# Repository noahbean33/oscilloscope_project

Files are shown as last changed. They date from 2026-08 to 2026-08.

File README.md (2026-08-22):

# Digital Oscilloscope Project

Complete project files for the digital oscilloscope system.

## Project Overview

This is a complete high-performance digital oscilloscope implementation featuring:
- **High-speed analog data acquisition** using ADC
- **FPGA-based signal processing** with Xilinx Artix-7
- **Real-time waveform capture and display**
- **Custom PCB design** with professional circuit layout
- **Embedded firmware** running on MicroBlaze soft processor

## Project Structure

```
oscilloscope_project/
├── oscilloscope-fpga/         # Xilinx Vivado FPGA project (Chapter 8 version)
│   ├── oscilloscope-fpga.xpr  # Main Vivado project file
│   ├── oscilloscope-fpga.srcs/# VHDL source files and constraints
│   └── oscilloscope-fpga.cache/# Vivado build cache
│
├── oscilloscope-software/     # Xilinx Vitis C/C++ software project (Chapter 8 version)
│   ├── oscilloscope-software/ # Application source code
│   └── oscilloscope-software_system/ # System configuration
│
├── oscilloscope-circuit/      # KiCad PCB design project (Chapter 6)
│   ├── Oscilloscope.sch       # Main schematic (hierarchical)
│   ├── Oscilloscope.kicad_pcb # PCB layout
│   ├── *.sch                  # Hierarchical schematic sheets
│   ├── Schematic Symbols.lib  # Custom schematic symbols
│   ├── Footprints.pretty/     # Custom PCB footprints
│   └── Oscilloscope.xlsx      # Bill of materials
│
├── set_drive_letter.bat       # Windows helper script for path length limits
└── README.md                  # This file
```

## Components

### 1. FPGA Project (`oscilloscope-fpga/`)
**Purpose**: Implements high-speed digital logic for ADC interface and data processing

**Key Features**:
- ADC interface logic (SPI communication)
- High-speed data capture buffer
- MicroBlaze soft processor integration
- AXI bus interconnect
- GPIO for status and control
- UART for debugging

**Tools Required**:
- Xilinx Vivado Design Suite (2019.2 or later recommended)
- Xilinx Artix-7 device support

**Opening the Project**:
1. Launch Xilinx Vivado
2. Open Project → Navigate to `oscilloscope-fpga/oscilloscope-fpga.xpr`
3. Generate bitstream or modify design as needed

### 2. Software Project (`oscilloscope-software/`)
**Purpose**: Embedded C firmware for MicroBlaze processor

**Key Features**:
- ADC configuration and control
- Data acquisition and buffering
- Waveform processing algorithms
- User interface logic
- Communication protocols

**Tools Required**:
- Xilinx Vitis (formerly SDK)
- Compatible with Vivado version

**Opening the Project**:
1. Launch Xilinx Vitis
2. Set workspace to `oscilloscope-software/`
3. Import existing application project
4. Build and debug on hardware

### 3. Circuit Design (`oscilloscope-circuit/`)
**Purpose**: Professional PCB schematic and layout

**Schematic Hierarchy**:
- `Oscilloscope.sch` - Top-level sheet
- `ADC.sch` - Analog-to-digital converter circuit
- `Analog Inputs.sch` - Input conditioning and protection
- `Calibration.sch` - Calibration circuitry
- `PMOD Ports.sch` - FPGA interface connectors
- `Power Supply.sch` - Power regulation circuits
- `SPI.sch` - SPI communication interface

**Key Features**:
- High-speed analog front-end
- Multi-layer PCB design
- Proper signal integrity considerations
- Power supply regulation
- FPGA interface via PMOD connectors

**Tools Required**:
- KiCad EDA 5.0 or later

**Opening the Project**:
1. Launch KiCad
2. Open Project → Navigate to `oscilloscope-circuit/Oscilloscope.pro`
3. **Important**: Add custom libraries first:
   - Open KiCad project manager
   - Go to *Preferences → Manage Symbol Libraries*
   - Add `Schematic Symbols.lib` as a project library
   - Go to *Preferences → Manage Footprint Libraries*
   - Add `Footprints.pretty/` directory as a project library
4. Open schematic or PCB editor

## Getting Started

### Prerequisites

**Hardware**:
- Xilinx Arty A7-100 development board
- Custom oscilloscope PCB (optional - can be ordered from Gerber files)
- USB cable for FPGA programming
- Power supply (5V for Arty board)

**Software**:
- Xilinx Vivado Design Suite (free WebPACK edition supports Artix-7)
- Xilinx Vitis Unified Software Platform
- KiCad EDA (for viewing/modifying circuit design)

### Build and Run Instructions

#### Step 1: Build FPGA Design
```bash
# Open oscilloscope-fpga.xpr in Vivado
# In Vivado TCL Console or GUI:
# 1. Run Synthesis
# 2. Run Implementation
# 3. Generate Bitstream
```

#### Step 2: Export Hardware Platform
```bash
# In Vivado, after successful bitstream generation:
# File → Export → Export Hardware
# Include bitstream
# Export to a location accessible by Vitis
```

#### Step 3: Build Software Application
```bash
# Open Vitis and import the software project
# 1. Set hardware platform (exported from Vivado)
# 2. Build application (hammer icon or Project → Build All)
# 3. Connect Arty board via USB
# 4. Program FPGA and run application
```

#### Step 4: Program and Test
```bash
# In Vitis:
# Xilinx → Program FPGA (loads bitstream)
# Run → Debug or Run (launches firmware)
# Monitor via UART terminal (115200 baud, 8N1)
```

### Manufacturing PCB (Optional)

If you want to build the custom oscilloscope circuit:

1. **Generate Manufacturing Files**:
   - Open `Oscilloscope.kicad_pcb` in KiCad
   - File → Plot → Generate Gerbers
   - File → Fabrication Outputs → Generate Drill Files

2. **Order PCB**:
   - Upload Gerber files to PCB manufacturer (OSH Park, JLCPCB, PCBWay, etc.)
   - Recommended specs: 4-layer board, 1.6mm thickness, ENIG finish

3. **Order Components**:
   - Use `Oscilloscope.xlsx` or `Oscilloscope.csv` for BOM
   - Purchase from Digi-Key, Mouser, or other electronics distributors

4. **Assembly**:
   - Follow Chapter 7 guidelines for component placement
   - Use reflow soldering for SMT components
   - Hand solder through-hole components

## System Architecture

```
┌─────────────────────────────────────────────────────────────┐
│                     Oscilloscope System                      │
├─────────────────────────────────────────────────────────────┤
│                                                              │
│  Analog Input → Front-End Conditioning → ADC → FPGA        │
│                                                ↓            │
│                                         Data Capture        │
│                                         & Processing        │
│                                                ↓            │
│                                        MicroBlaze CPU       │
│                                                ↓            │
│                                    Display/Communication    │
│                                                              │
└─────────────────────────────────────────────────────────────┘
```

### Signal Flow:
1. **Analog Input** - External signal via BNC/scope probe
2. **Conditioning** - Amplification, attenuation, filtering
3. **ADC** - High-speed analog-to-digital conversion
4. **FPGA Logic** - Parallel data capture and buffering
5. **MicroBlaze** - Signal processing and control
6. **Output** - Display via UART/interface

## Configuration

### FPGA Clock Configuration
- System clock: Typically 100 MHz from Arty board
- ADC sampling clock: Configurable based on requirements
- Check constraints file (`.xdc`) in `oscilloscope-fpga.srcs/constrs_1/`

### Software Configuration
- UART baud rate: 115200 (default)
- ADC sample rate: Configured in firmware
- Buffer sizes: Adjustable in source code

## Troubleshooting

### Vivado Path Length Issues (Windows)
- Use `set_drive_letter.bat` to create shorter paths
- Edit script to match your installation location
- Maps directory to drive letter Z:

### Library Not Found (KiCad)
- Ensure custom libraries are added to project
- Check `sym-lib-table` and `fp-lib-table` files
- Re-add libraries via Preferences if needed

### FPGA Programming Fails
- Check USB cable connection
- Verify Arty board is powered
- Install Xilinx cable drivers
- Check Device Manager (Windows) or lsusb (Linux)

### Software Build Errors
- Ensure hardware platform matches FPGA design
- Regenerate BSP (Board Support Package)
- Clean and rebuild project

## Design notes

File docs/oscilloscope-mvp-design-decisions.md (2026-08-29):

# MVP Design Decisions

## Status and revision boundary

This file records the implemented **Oscilloscope internal-ADC MVP** decisions as of 2026-08-28. The live design has 101 components and 57 nets. **Proposed, locked, target, configured, implemented, modeled, measured, tested, certified, and production-proven are distinct statuses.** Implementation does not establish measured or certified performance.

## Fixed product requirements and exclusions

- Retain STM32L432KCU6, internal ADC, native USB FS, 192×96 LCD, three buttons, four LEDs, two BNC channels, and STDC14 SWD/VCP.
- **CH1 = PA0 / ADC1_IN5. CH2 = PA1 / ADC1_IN6.** ADC regular sequence is **CH1 rank 1, then CH2 rank 2**.
- Two identical DC-coupled, unipolar channels. No AC coupling, gain/range switching, external ADC, FPGA, bipolar supply, hardware comparator trigger, isolation, battery, or probe-compensation output in MVP.
- Normal rated measurement range is **0–12 V DC**, ground referenced. **15 V is only an unverified overload-survival design target**; it is not bench-tested, safety certified, or part of the normal measurement rating.
- Prohibited: negative inputs, floating measurements, mains, CAT environments, motor/inverter power nodes, high-energy sources, or any source whose ground cannot safely be bonded to USB/PCB ground.
- Low-frequency nominal input impedance: **1.10 MΩ** per channel.
- BNC shells, PCB signal ground, MCU ground, and USB ground are common.

## Locked decision table

| Item | Rev 0.2 MVP decision | Status / verification gate |
|---|---|---|
| ADC pins and sequence | CH1 = PA0/ADC1_IN5, rank 1; CH2 = PA1/ADC1_IN6, rank 2 | Schematic implemented; firmware register/readback confirmation required |
| ADC clock/rate | ADC asynchronous clock target 80 MHz; timer-triggered 3.2 Msps aggregate; 12.5-cycle sample + 12.5-cycle conversion | Proposed configuration; ADC timing remains unmeasured |
| Channel timing | CH1 then CH2, nominal 312.5 ns sample-time offset and 1.6 Msps/channel | Configuration targets, not measured facts |
| Input range | 0–12 V DC normal rated measurement | Locked |
| Overload | 15 V non-destructive survival target | Unverified prototype gate; not a user rating or certification |
| Input impedance | 1.10 MΩ low-frequency nominal | Locked |
| Analog architecture | Divider → CHx_CLAMP → 10 kΩ → TLV9062 non-inverting input → follower → 47 Ω/1 nF ADC RC | Implemented |
| Divider | 3 × 300 kΩ high arm + 200 kΩ low arm; all 0.1%, ≤25 ppm/°C | Locked |
| Compensation | 12 pF C0G across each 300 kΩ; 8.2 pF C0G across 200 kΩ plus 2.2 pF/4.7 pF trim pads | 8.2 pF-only baseline fails modeled ±1 dB-to-100 kHz flatness. Expected robust population is both trims (15.1 pF total); 12.9 pF remains the measured-parasitic alternate. |
| Clamp | One BAV199LT1G per channel, both internal diodes used | Locked; exact mapping below |
| Buffer/filter | TLV9062IDGKR; 1.0 nF C0G at ADC pin; R12/R18 = 47 Ω Yageo RC0603FR-0747RL | Implemented; bounded model passes, hardware timing/settling unmeasured |
| Clock accuracy | HSI timebase with USB-SOF/factory correction | Locked approach; HSI accuracy over temperature is a prototype gate |
| VCP | Explicit crossed target/probe UART nets | Locked; continuity/loopback confirmation required |
| LCD procurement | Exact **ERM19296-1, “4-Wire SPI Pin Header Connection”** option | Locked; connector/interface captured below |
| Backlight resistor | 27 Ω, 0.75 W initial prototype tuning value | Bounded value-selection gate: accept only if measured current is 60–75 mA |
| Backlight switching | Protected-5-V high-side PWM: NCE3401 P-MOS plus 2N7002KT1G gate pull-down; LCD pin 6 remains solid ground | Implemented; PWM high = backlight ON; operating point and thermals unmeasured |
| Spare headers | Remove both TS-107-T-AA headers | Locked |
| Protection/thermal/ESD | Existing specified USB and input-protection architecture | Thermal, hot-plug, overload, and ESD performance remain prototype gates |

## Analog front end

### Per-channel connection

`BNC center → 300 kΩ → 300 kΩ → 300 kΩ → divider node/CHx_CLAMP; 200 kΩ CHx_CLAMP-to-AGND; compensation capacitors across divider resistors; BAV199 clamps at CHx_CLAMP; 10 kΩ CHx_CLAMP-to-TLV9062 non-inverting input; TLV9062 follower; 47 Ω output series; 1 nF ADC-pin-to-AGND; MCU ADC pin.`

The divider node is the named **CH1_CLAMP** or **CH2_CLAMP** net. The 10 kΩ resistor is downstream of that net, between CHx_CLAMP and the corresponding TLV9062 non-inverting input.

### BAV199LT1G exact pin mapping

The authoritative onsemi BAV199LT1G datasheet, SOT-23 Case 318 Style 11, defines **pin 1 = ANODE, pin 2 = CATHODE, pin 3 = CATHODE-ANODE series junction**. Therefore connect each clamp as follows:

- **Pin 1 (lower-diode anode) → AGND**
- **Pin 3 (series junction: lower cathode / upper anode) → CHx_CLAMP**
- **Pin 2 (upper-diode cathode) → VDDA, the 3.3 V analog rail**

This uses both internal diodes. Do not leave either diode unused, and do not connect the upper clamp to noisy digital 3V3.

### Divider calculation and tolerance

Nominal values are `RH = 3 × 300 kΩ = 900 kΩ` and `RL = 200 kΩ`.

- Nominal ratio: `k = RL/(RH+RL) = 200/1100 = 0.1818181818`.
- Low-frequency nominal input impedance: `RH + RL = 1.10 MΩ`.
- 12 V input → 2.1818 V nominal at CHx_CLAMP.
- 15 V input → 2.7273 V nominal; this supports only the unverified overload-survival target.
- 3.3 V ADC full-scale corresponds to 18.15 V nominal input and is headroom, not a rating.

Three equal 300 kΩ, ±0.1% resistors in series form a 900 kΩ arm with **±0.1% guaranteed resistance tolerance**, because their absolute worst-case errors sum in the same proportion as their nominal values; the arm is not ±0.3%.

Exact opposing-arm worst case:

- `kMAX = 200.2/(899.1+200.2) = 0.1821158919`, or **+0.163741%** relative to nominal.
- `kMIN = 199.8/(900.9+199.8) = 0.1815208504`, or **−0.163532%** relative to nominal.

Thus the guaranteed divider-ratio limit is approximately **+0.1637% / −0.1635%** before calibration, commonly rounded to **±0.164%**.

For statistical/RSS estimates, keep assumptions explicit:

- If each resistor's 0.1% is treated as an independent 1σ value, first-order ratio RSS is **0.0945% (1σ)**.
- If ±0.1% is treated as a rectangular guaranteed bound, each resistor has σ = 0.1%/√3 and the first-order ratio RSS is **0.0545% (1σ)**.

Neither RSS figure replaces the guaranteed worst-case limit.

## ADC and firmware acquisition targets

- ADC asynchronous clock target: **80 MHz**.
- Regular conversion sequence: **ADC1_IN5/CH1 rank 1**, then **ADC1_IN6/CH2 rank 2**.
- Per-rank timing target: **12.5 ADC clock cycles sampling + 12.5 cycles conversion = 25 cycles = 312.5 ns** at 80 MHz.
- Timer-triggered sequence target: **3.2 Msps aggregate**, yielding **1.6 Msps/channel** for the two alternating ranks.
- The **312.5 ns channel skew** and **1.6 Msps/channel** values are configuration targets requiring firmware register verification and bench timing confirmation; they are not measured performance claims.
- The superseded 330 Ω/1 nF network modeled at approximately **9.5–9.9 LSB external acquisition error**. The implemented **47 Ω/1 nF** network models at **0.558 LSB worst case** over RADC bounds 0–680 Ω. This is not a measured ADC timing or settling result.
- DMA circular acquisition, software trigger, and 10/50/90% pretrigger remain locked.
- HSI timebase accuracy, including temperature behavior after USB-SOF/factory correction, is a prototype verification gate.

## VCP net naming

Use direction-explicit nets and preserve the crossover:

- **VCP_TARGET_TX_TO_PROBE_RX:** MCU UART TX → STDC14 probe RX.
- **VCP_PROBE_TX_TO_TARGET_RX:** STDC14 probe TX → MCU UART RX.

Do not use ambiguous bare `TX`/`RX` names. Confirm with continuity and loopback during bring-up.

## LCD procurement and interface capture

Procurement is locked to the exact **ERM19296-1 “4-Wire SPI Pin Header Connection”** option. The module uses a **1×20, 2.54 mm-pitch pin header**. Capture the connector as follows for the ordered 4-wire SPI option:

| Pin | Module signal | Rev 0.2 disposition |
|---:|---|---|
| 1–4 | Optional font-chip SI, SO, SCLK, CS# | NC unless the exact ordered option includes and uses the font chip |
| 5 | LEDA | Backlight anode supply path through the prototype-selected series resistor |
| 6 | VSS | Common module ground and backlight return; the authoritative pin table exposes no separate LEDK connector pin |
| 7 | VDD | 3.3 V logic supply |
| 8 | A0(RS) | MCU LCD data/command select |
| 9 | RSTB | MCU LCD reset |
| 10 | CSB | MCU LCD chip select |
| 11–14 | DB7–DB4 | Tie high to VDD for serial mode |
| 15–17 | DB3–DB1 | Tie together and connect to MCU SPI MOSI/SDA |
| 18 | DB0 | Connect to MCU SPI SCK/SCL |
| 19 | ERD | Tie to VDD in serial mode |
| 20 | RWR | Tie to VDD in serial mode |

The ordered module's interface selection must be **IF2:IF1:IF0 = L:L:L for 4-wire serial SPI**. Capture A0/RS, CSB, RSTB, MOSI/SDA, and SCK/SCL explicitly. Incoming inspection must verify the ordered option and any factory straps.

The backlight uses a protected-5-V high-side PWM switch. Protected VBUS connects to the **source of fitted NCE3401 P-channel MOSFET Q1**;

Logic polarity is non-inverting end-to-end: **MCU PWM high turns the 2N7002 on, pulls the NCE3401 gate low, turns the P-MOS on, and turns the backlight ON**. PWM low leaves both devices off through their pull resistors. The fitted NCE3401 has 75 mΩ maximum RDS(on) at VGS = −4.5 V;

The 27 Ω value remains provisional: measure the exact ordered module and retain or change it only if maximum-brightness current is **60–75 mA** under the defined VBUS condition. Verify resistor and MOSFET temperatures at acceptance limits.

## Power budget and current derivation

An LDO input current is approximately its output current plus small quiescent current; it is **not** power-converted as it would be through an ideal switching regulator. The backlight is a separate direct-VBUS load.

The exact accounting is LDO input current = LDO output current + LDO quiescent current, with direct-VBUS loads added separately. Including 80 µA LDO IQ and 20 µA TVS leakage gives 125.10/145.10/175.10 mA; rounded totals are:

- Typical case: `50 mA 3.3 V rail + 75 mA direct-VBUS backlight ≈ 125 mA USB`.
- Design case: `70 mA + 75 mA = 145 mA USB`.
- Validation case: `100 mA + 75 mA = 175 mA USB`.

Backlight remains off before USB configuration; pre-enumeration target is <100 mA. AP7361C thermal performance, VBUS hot-plug behavior, PPTC behavior, and backlight heating remain prototype verification gates.

## Verification gates and claim limits

The following are **not measured facts** and must be labeled as prototype verification gates wherever mentioned:

- Analog bandwidth, amplitude flatness, −3 dB point, alias response, and ADC settling/crosstalk.
- HSI/timebase accuracy over voltage and temperature.
- 15 V overload survival and recovery.
- Divider compensation trim and square-wave response.
- Regulator, MOSFET, LCD/backlight, and enclosure thermal performance.
- USB and external-input ESD/hot-plug robustness.

Required warning wording: **“0–12 V DC RATED MEASUREMENT; 15 V OVERLOAD-SURVIVAL TARGET UNVERIFIED; GROUND REFERENCED; NOT ISOLATED; NO MAINS/CAT/HIGH ENERGY; NO NEGATIVE INPUT.”**

## Implemented PCB and release state

- Board: 100 × 100 mm, four copper layers, nominal 1.30 mm custom stackup; all components top-side.
- Routing: complete, zero airwires and zero DRC errors.
- USB_DP final repair: bottom-layer bypass with explicit top/bottom transition vias.
- USB configuration target: 45 Ω single-ended / 90 Ω differential; fabrication target only, not measured or certified performance.
- Remaining protected warnings: `Trace a4ae` and `Trace b74f`; Gerber cleanup or explicit waiver required.
- SMT assembly blocker: fourteen fabricated 1.0 × 1.0 mm test pads remain BOM elements and must be excluded from BOM and pick-and-place. TP_GND (Keystone 4952) remains included.
- DNI exclusion set: C16, C17, C23, and C24.

## Schematic acceptance

- PA0/ADC1_IN5 is CH1 and PA1/ADC1_IN6 is CH2; rank order is documented.
- Both channels use the exact BAV199 pin mapping above and both internal diodes.
- CHx_CLAMP naming and the downstream 10 kΩ-to-op-amp connection are explicit.
- LCD connector, 4-wire SPI strapping, and signal dispositions are explicit; pin 6 remains solid ground and pin 5 is driven by the protected-5-V high-side PWM path.
- VCP crossover nets are direction-explicit.
- Both TS-107-T-AA headers are absent.
- Implemented items are not described as measured, tested, certified, or production-proven without evidence.

**Remaining schematic blocker:** none identified. Bandwidth, divider compensation, 15 V overload survival, backlight operating point, USB ESD/hot-plug, ADC timing, thermals, and HSI accuracy remain unmeasured prototype gates.

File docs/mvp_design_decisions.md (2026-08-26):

# MVP Design Decisions

## Status and revision boundary

This file locks the **Sillyscope Rev 0.2 MVP** decisions for schematic capture. **Proposed/locked means approved for capture; it does not mean implemented, tested, measured, or certified.** Rev 0.2 circuitry is not yet present in the schematic. Firmware-confirmation and prototype-verification gates do not block capture unless explicitly identified as a capture blocker.

## Fixed product requirements and exclusions

- Retain STM32L432KCU6, internal ADC, native USB FS, 192×96 LCD, three buttons, four LEDs, two BNC channels, and STDC14 SWD/VCP.
- **CH1 = PA0 / ADC1_IN5. CH2 = PA1 / ADC1_IN6.** ADC regular sequence is **CH1 rank 1, then CH2 rank 2**.
- Two identical DC-coupled, unipolar channels. No AC coupling, gain/range switching, external ADC, FPGA, bipolar supply, hardware comparator trigger, isolation, battery, or probe-compensation output in MVP.
- Normal rated measurement range is **0–12 V DC**, ground referenced. **15 V is only an unverified overload-survival design target**; it is not bench-tested, safety certified, or part of the normal measurement rating.
- Prohibited: negative inputs, floating measurements, mains, CAT environments, motor/inverter power nodes, high-energy sources, or any source whose ground cannot safely be bonded to USB/PCB ground.
- Low-frequency nominal input impedance: **1.10 MΩ** per channel.
- BNC shells, PCB signal ground, MCU ground, and USB ground are common.

## Locked decision table

| Item | Rev 0.2 MVP decision | Status / verification gate |
|---|---|---|
| ADC pins and sequence | CH1 = PA0/ADC1_IN5, rank 1; CH2 = PA1/ADC1_IN6, rank 2 | Locked for capture; firmware register/readback confirmation required |
| ADC clock/rate | ADC asynchronous clock target 80 MHz; timer-triggered 3.2 Msps aggregate; 12.5-cycle sample + 12.5-cycle conversion | **Current 330 Ω/1 nF drive fails modeled acquisition settling (~9.5–9.9 LSB).** Change R12/R18 to 47 Ω is recommended before layout freeze; then re-simulate and bench-confirm. |
| Channel timing | CH1 then CH2, nominal 312.5 ns sample-time offset and 1.6 Msps/channel | Configuration targets, not measured facts |
| Input range | 0–12 V DC normal rated measurement | Locked |
| Overload | 15 V non-destructive survival target | Unverified prototype gate; not a user rating or certification |
| Input impedance | 1.10 MΩ low-frequency nominal | Locked |
| Analog architecture | Divider → CHx_CLAMP → 10 kΩ → TLV9062 non-inverting input → follower → 330 Ω/1 nF ADC RC | Locked |
| Divider | 3 × 300 kΩ high arm + 200 kΩ low arm; all 0.1%, ≤25 ppm/°C | Locked |
| Compensation | 12 pF C0G across each 300 kΩ; 8.2 pF C0G across 200 kΩ plus 2.2 pF/4.7 pF trim pads | 8.2 pF-only baseline fails modeled ±1 dB-to-100 kHz flatness. Expected robust population is both trims (15.1 pF total); 12.9 pF remains the measured-parasitic alternate. |
| Clamp | One BAV199LT1G per channel, both internal diodes used | Locked; exact mapping below |
| Buffer/filter | TLV9062IDR; 1.0 nF C0G at ADC pin; **47 Ω series recommended in place of captured 330 Ω** | Simulation-proven change required to retain 12.5-cycle target; not yet implemented |
| Clock accuracy | HSI timebase with USB-SOF/factory correction | Locked approach; HSI accuracy over temperature is a prototype gate |
| VCP | Explicit crossed target/probe UART nets | Locked; continuity/loopback confirmation required |
| LCD procurement | Exact **ERM19296-1, “4-Wire SPI Pin Header Connection”** option | Locked; connector/interface captured below |
| Backlight resistor | 27 Ω, 0.5 W initial prototype tuning value | Bounded value-selection gate: accept only if measured current is 60–75 mA |
| Backlight switching | Protected-5-V high-side PWM: AO3401A P-MOS plus 2N7002KT1G gate pull-down; LCD pin 6 remains solid ground | Locked for capture; PWM high = backlight ON; thermal verification required |
| Spare headers | Remove both TS-107-T-AA headers | Locked |
| Protection/thermal/ESD | Existing specified USB and input-protection architecture | Thermal, hot-plug, overload, and ESD performance remain prototype gates |

## Analog front end

### Per-channel connection

`BNC center → 300 kΩ → 300 kΩ → 300 kΩ → divider node/CHx_CLAMP; 200 kΩ CHx_CLAMP-to-AGND; compensation capacitors across divider resistors; BAV199 clamps at CHx_CLAMP; 10 kΩ CHx_CLAMP-to-TLV9062 non-inverting input; TLV9062 follower; 330 Ω output series; 1 nF ADC-pin-to-VSSA; MCU ADC pin.`

The divider node is the named **CH1_CLAMP** or **CH2_CLAMP** net. The 10 kΩ resistor is downstream of that net, between CHx_CLAMP and the corresponding TLV9062 non-inverting input.

### BAV199LT1G exact pin mapping

The authoritative onsemi BAV199LT1G datasheet, SOT-23 Case 318 Style 11, defines **pin 1 = ANODE, pin 2 = CATHODE, pin 3 = CATHODE-ANODE series junction**. Therefore connect each clamp as follows:

- **Pin 1 (lower-diode anode) → AGND**
- **Pin 3 (series junction: lower cathode / upper anode) → CHx_CLAMP**
- **Pin 2 (upper-diode cathode) → VDDA, the 3.3 V analog rail**

This uses both internal diodes. Do not leave either diode unused, and do not connect the upper clamp to noisy digital 3V3.

### Divider calculation and tolerance

Nominal values are `RH = 3 × 300 kΩ = 900 kΩ` and `RL = 200 kΩ`.

- Nominal ratio: `k = RL/(RH+RL) = 200/1100 = 0.1818181818`.
- Low-frequency nominal input impedance: `RH + RL = 1.10 MΩ`.
- 12 V input → 2.1818 V nominal at CHx_CLAMP.
- 15 V input → 2.7273 V nominal; this supports only the unverified overload-survival target.
- 3.3 V ADC full-scale corresponds to 18.15 V nominal input and is headroom, not a rating.

Three equal 300 kΩ, ±0.1% resistors in series form a 900 kΩ arm with **±0.1% guaranteed resistance tolerance**, because their absolute worst-case errors sum in the same proportion as their nominal values; the arm is not ±0.3%.

Exact opposing-arm worst case:

- `kMAX = 200.2/(899.1+200.2) = 0.1821158919`, or **+0.163741%** relative to nominal.
- `kMIN = 199.8/(900.9+199.8) = 0.1815208504`, or **−0.163532%** relative to nominal.

Thus the guaranteed divider-ratio limit is approximately **+0.1637% / −0.1635%** before calibration, commonly rounded to **±0.164%**.

For statistical/RSS estimates, keep assumptions explicit:

- If each resistor's 0.1% is treated as an independent 1σ value, first-order ratio RSS is **0.0945% (1σ)**.
- If ±0.1% is treated as a rectangular guaranteed bound, each resistor has σ = 0.1%/√3 and the first-order ratio RSS is **0.0545% (1σ)**.

Neither RSS figure replaces the guaranteed worst-case limit.

## ADC and firmware acquisition targets

- ADC asynchronous clock target: **80 MHz**.
- Regular conversion sequence: **ADC1_IN5/CH1 rank 1**, then **ADC1_IN6/CH2 rank 2**.
- Per-rank timing target: **12.5 ADC clock cycles sampling + 12.5 cycles conversion = 25 cycles = 312.5 ns** at 80 MHz.
- Timer-triggered sequence target: **3.2 Msps aggregate**, yielding **1.6 Msps/channel** for the two alternating ranks.
- The **312.5 ns channel skew** and **1.6 Msps/channel** values are configuration targets requiring firmware register verification and bench timing confirmation; they are not measured performance claims.
- Rev 0.2 simulation of the captured 330 Ω/1 nF ADC network produced approximately **9.5–9.9 LSB external acquisition error** for alternating 0.5 V/12 V channel-equivalent levels. A candidate sweep found **47 Ω/1 nF** gives **0.558 LSB worst-case modeled error** over RADC bounds 0–680 Ω. Treat R12/R18=47 Ω as the required pre-layout change unless a subsequent authoritative macromodel contradicts it.
- DMA circular acquisition, software trigger, and 10/50/90% pretrigger remain locked.
- HSI timebase accuracy, including temperature behavior after USB-SOF/factory correction, is a prototype verification gate.

## VCP net naming

Use direction-explicit nets and preserve the crossover:

- **VCP_TARGET_TX_TO_PROBE_RX:** MCU UART TX → STDC14 probe RX.
- **VCP_PROBE_TX_TO_TARGET_RX:** STDC14 probe TX → MCU UART RX.

Do not use ambiguous bare `TX`/`RX` names. Confirm with continuity and loopback during bring-up.

## LCD procurement and interface capture

Procurement is locked to the exact **ERM19296-1 “4-Wire SPI Pin Header Connection”** option. The module uses a **1×20, 2.54 mm-pitch pin header**. Capture the connector as follows for the ordered 4-wire SPI option:

| Pin | Module signal | Rev 0.2 disposition |
|---:|---|---|
| 1–4 | Optional font-chip SI, SO, SCLK, CS# | NC unless the exact ordered option includes and uses the font chip |
| 5 | LEDA | Backlight anode supply path through the prototype-selected series resistor |
| 6 | VSS | Common module ground and backlight return; the authoritative pin table exposes no separate LEDK connector pin |
| 7 | VDD | 3.3 V logic supply |
| 8 | A0(RS) | MCU LCD data/command select |
| 9 | RSTB | MCU LCD reset |
| 10 | CSB | MCU LCD chip select |
| 11–14 | DB7–DB4 | Tie high to VDD for serial mode |
| 15–17 | DB3–DB1 | Tie together and connect to MCU SPI MOSI/SDA |
| 18 | DB0 | Connect to MCU SPI SCK/SCL |
| 19 | ERD | Tie to VDD in serial mode |
| 20 | RWR | Tie to VDD in serial mode |

The ordered module's interface selection must be **IF2:IF1:IF0 = L:L:L for 4-wire serial SPI**. Capture A0/RS, CSB, RSTB, MOSI/SDA, and SCK/SCL explicitly. Incoming inspection must verify the ordered option and any factory straps.

The backlight uses a protected-5-V high-side PWM switch. Connect protected VBUS to the **source of AO3401A P-channel MOSFET**; connect its drain through the provisional **27 Ω, 0.5 W** resistor to LCD **LEDA pin 5**. LCD **pin 6 VSS remains continuously bonded to ground** for both logic and backlight return. Pull the AO3401A gate up to protected VBUS with **100 kΩ** for default OFF. A **2N7002KT1G** N-MOS has its drain at the P-MOS gate, source at ground, and gate driven by the MCU PWM through **100 Ω**, with **100 kΩ gate-to-ground** for default OFF.

Logic polarity is non-inverting end-to-end: **MCU PWM high turns the 2N7002 on, pulls the AO3401A gate low, turns the P-MOS on, and turns the backlight ON**. PWM low leaves both devices off through their pull resistors. AO3401A is rated −30 V VDS and ±12 V VGS, with RDS(on) maximum 60 mΩ at VGS = −4.5 V; the protected-5-V gate swing is within rating and provides negligible conduction loss at 60–75 mA. 2N7002KT1G is rated 60 V VDS, ±20 V VGS, and at least 230 mA continuous drain current under its stated minimum-pad/high-temperature condition; it only sinks the 100 kΩ pull-up current plus gate transient current. These ratings are suitable for this driver.

The 27 Ω value remains provisional: measure the exact ordered module and retain or change it only if maximum-brightness current is **60–75 mA** under the defined VBUS condition. Verify resistor and MOSFET temperatures at acceptance limits.

## Power budget and current derivation

An LDO input current is approximately its output current plus small quiescent current; it is **not** power-converted as it would be through an ideal switching regulator. The backlight is a separate direct-VBUS load.

Ignoring small LDO quiescent current in these rounded totals:

- Typical case: `50 mA 3.3 V rail + 75 mA direct-VBUS backlight ≈ 125 mA USB`.
- Design case: `70 mA + 75 mA = 145 mA USB`.
- Validation case: `100 mA + 75 mA = 175 mA USB`.

Backlight remains off before USB configuration; pre-enumeration target is <100 mA. AP7361C thermal performance, VBUS hot-plug behavior, PPTC behavior, and backlight heating remain prototype verification gates.

## Verification gates and claim limits

The following are **not measured facts** and must be labeled as prototype verification gates wherever mentioned:

- Analog bandwidth, amplitude flatness, −3 dB point, alias response, and ADC settling/crosstalk.
- HSI/timebase accuracy over voltage and temperature.
- 15 V overload survival and recovery.
- Divider compensation trim and square-wave response.
- Regulator, MOSFET, LCD/backlight, and enclosure thermal performance.
- USB and external-input ESD/hot-plug robustness.

Required warning wording: **“0–12 V DC RATED MEASUREMENT; 15 V OVERLOAD-SURVIVAL TARGET UNVERIFIED; GROUND REFERENCED; NOT ISOLATED; NO MAINS/CAT/HIGH ENERGY; NO NEGATIVE INPUT.”**

## Schematic-capture acceptance

- PA0/ADC1_IN5 is CH1 and PA1/ADC1_IN6 is CH2; rank order is documented.
- Both channels use the exact BAV199 pin mapping above and both internal diodes.
- CHx_CLAMP naming and the downstream 10 kΩ-to-op-amp connection are explicit.
- LCD connector, 4-wire SPI strapping, and signal dispositions are explicit; pin 6 remains solid ground and pin 5 is driven by the protected-5-V high-side PWM path.
- VCP crossover nets are direction-explicit.
- Both TS-107-T-AA headers are absent.
- Proposed/locked items are not described as implemented or tested.

**Remaining schematic-capture blocker:** none identified after adopting the high-side backlight switch. Firmware confirmation, compensation selection, bandwidth, HSI accuracy, overload, thermal, hot-plug, backlight-current tuning, and ESD tests remain post-capture prototype gates rather than capture blockers.

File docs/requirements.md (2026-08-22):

- two channels
- display shows one channel
- 0v to 3.3v range
- accurate to 500 khz
- data streaming/logging to pc
- small form factor
- buttons for channel activation
- button for start/stop recording
- led indicator for power, channel activity, recording, etc

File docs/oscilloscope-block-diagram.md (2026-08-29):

# Block Diagram

## Rev 0.2 status

The following architecture is implemented in the live 101-component, 57-net design. Implementation does not imply measured, tested, certified, or production-proven performance.

```mermaid
flowchart LR
  B1[CH1 BNC\n0–12 V rated] --> D1[1.10 MΩ low-frequency nominal\n5.5:1 compensated divider]
  B2[CH2 BNC\n0–12 V rated] --> D2[1.10 MΩ low-frequency nominal\n5.5:1 compensated divider]
  D1 --> C1[CH1_CLAMP\nBAV199: P1 AGND, P3 node, P2 VDDA]
  D2 --> C2[CH2_CLAMP\nBAV199: P1 AGND, P3 node, P2 VDDA]
  C1 --> R1[10 kΩ] --> O1[TLV9062IDGKR buffer A] --> F1[47 Ω R12 + 1 nF] --> A1[PA0 / ADC1_IN5\nCH1 rank 1]
  C2 --> R2[10 kΩ] --> O2[TLV9062IDGKR buffer B] --> F2[47 Ω R18 + 1 nF] --> A2[PA1 / ADC1_IN6\nCH2 rank 2]
  A1 --> MCU[STM32L432KCU6\n80 MHz ADC clock target\n3.2 Msps aggregate target]
  A2 --> MCU

  USB[USB-C VBUS + USB FS] --> ESD[USBLC6-2SC6]
  ESD --> MCU
  USB --> PF[MF-PSMF035X-2] --> V5[Protected VBUS]
  V5 --> LDO[AP7361C 3.3 V]
  V5 --> PM[NCE3401 Q1 P-MOS high-side switch\n100 kΩ gate pull-up = default OFF]
  PM --> BR[27 Ω, 0.75 W provisional] --> BL[ERM19296-1 LEDA pin 5]
  BL --> GND[LCD pin 6 VSS\nsolid common ground/return]
  LDO --> MCU
  LDO --> VDDA[Filtered VDDA]
  VDDA --> C1
  VDDA --> C2
  LDO --> OP[TLV9062]
  LDO --> LCD[ERM19296-1 exact\n4-wire SPI, 1x20 2.54 mm]
  MCU --> LCD
  MCU -->|PWM high = ON\n100 Ω gate series| NM[2N7002KT1G\n100 kΩ gate pulldown]
  NM -->|pulls P-MOS gate low| PM

  MTX[MCU TX] -->|VCP_TARGET_TX_TO_PROBE_RX| PRX[STDC14 probe RX]
  PTX[STDC14 probe TX] -->|VCP_PROBE_TX_TO_TARGET_RX| MRX[MCU RX]
```

## Timing and rating annotations

- ADC sequence target: CH1 rank 1 then CH2 rank 2.
- Target timing: 12.5-cycle sample + 12.5-cycle conversion at 80 MHz, giving 312.5 ns skew and 1.6 Msps/channel at 3.2 Msps aggregate.
- These timing values require firmware and bench confirmation.
- Normal measurement rating is 0–12 V DC. Fifteen-volt survival is an unverified overload target, not a rating.

## Ground and safety

BNC shells, AGND/PCB ground, MCU ground, and USB ground are common. Rev 0.2 remains non-isolated and has no CAT, mains, high-energy, or negative-input rating.

Detailed interface pin dispositions and verification gates: [MVP Design Decisions](https://www.flux.ai/nbean/oscilloscope/files/mvp-design-decisions).

The high-side switch preserves the required solid VSS/backlight return on pin 6. The 27 Ω value remains provisional pending module current and thermal measurement.

## PCB status

The PCB is 100 × 100 mm, four copper layers, nominal 1.30 mm custom stackup, with all components top-side. Routing is complete with zero airwires and zero DRC errors. USB_DP uses a bottom-layer bypass with explicit top/bottom transition vias. The configured USB target is 45 Ω single-ended / 90 Ω differential for fabrication, not measured or certified performance. Protected warnings remain for `Trace a4ae` and `Trace b74f`.

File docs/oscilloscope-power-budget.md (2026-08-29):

# Power Budget

## Revision boundary

These are planning and bounded-calculation values for the implemented design, not measured results. The LCD backlight is supplied directly from protected VBUS; logic and analog circuitry use the 3.3 V LDO.

## Rev 0.2 budget

| Load | Typical/planning | Design/validation |
|---|---:|---:|
| STM32L432KCU6 | 12 mA | 25 mA allowance |
| TLV9062 dual | 1.1 mA | 1.5 mA allowance |
| LCD logic | 5 mA planning | 15 mA allowance |
| Four indicator LEDs | up to 24 mA | 24 mA |
| Miscellaneous | 3–5 mA | included in rail totals |
| **3.3 V rail** | **about 50 mA** | **70 mA design; 100 mA validation case** |
| LCD backlight from protected VBUS | **60–75 mA acceptance band** | **75 mA budget** |

## Correct USB-current derivation

An LDO input current is approximately its output current plus its quiescent current. It is not calculated by ideal power conversion. The backlight current is separately drawn directly from VBUS.

Using AP7361C maximum quiescent current of 80 µA and adding the direct-source backlight and 20 µA TVS leakage separately:

- **Typical:** `50.00 mA LDO output + 0.08 mA LDO IQ + 75.00 mA backlight + 0.02 mA TVS = 125.10 mA USB`.
- **Design:** `70.00 + 0.08 + 75.00 + 0.02 = 145.10 mA USB`.
- **Validation case:** `100.00 + 0.08 + 75.00 + 0.02 = 175.10 mA USB`.

The rounded architecture totals are 125/145/175 mA. Other direct-VBUS loads, if added, must be included separately rather than reflected through the LDO.

Backlight is held off until USB configuration; pre-enumeration target remains <100 mA.

## LDO thermal planning

At 5.0 V input and 3.3 V output:

- 50 mA → `(5.0−3.3)×0.050 = 85 mW`.
- 70 mA → **119 mW**.
- 100 mA → **170 mW**.

These are calculated dissipation targets. AP7361C case temperature, closed-enclosure temperature rise, and 3.3 V regulation under maximum load remain prototype verification gates.

## Backlight value-selection gate

Protected VBUS feeds fitted **NCE3401 Q1** as the P-MOS high-side switch, then provisional **27 Ω R19** (Yageo RC2010FK-0727RL, 0.75 W), then ERM19296-1 LEDA pin 5.

At 75 mA, NCE3401 conduction loss using 75 mΩ maximum RDS(on) at −4.5 V is about `I²R = 0.075²×0.075 = 0.42 mW`.

**27 Ω remains an initial tuning value, not a final electrical acceptance.** Measure the exact ordered module Vf/current and retain or replace the resistor so maximum-brightness current is **60–75 mA**. Verify resistor, P-MOS, LCD, and enclosure temperatures. This correction removes the backlight schematic-capture blocker without changing the 75 mA current budget.

## Protected power path gates

PPTC voltage drop/nuisance trip, VBUS hot-plug overshoot, TVS behavior, regulator and backlight thermal performance, and USB ESD performance remain unmeasured prototype gates.

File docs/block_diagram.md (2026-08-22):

# Block Diagram

## Rev 0.2 status

The following architecture is locked for schematic capture but is not yet implemented or tested.

```mermaid
flowchart LR
  B1[CH1 BNC\n0–12 V rated] --> D1[1.10 MΩ low-frequency nominal\n5.5:1 compensated divider]
  B2[CH2 BNC\n0–12 V rated] --> D2[1.10 MΩ low-frequency nominal\n5.5:1 compensated divider]
  D1 --> C1[CH1_CLAMP\nBAV199: P1 AGND, P3 node, P2 VDDA]
  D2 --> C2[CH2_CLAMP\nBAV199: P1 AGND, P3 node, P2 VDDA]
  C1 --> R1[10 kΩ] --> O1[TLV9062 buffer A] --> F1[330 Ω + 1 nF] --> A1[PA0 / ADC1_IN5\nCH1 rank 1]
  C2 --> R2[10 kΩ] --> O2[TLV9062 buffer B] --> F2[330 Ω + 1 nF] --> A2[PA1 / ADC1_IN6\nCH2 rank 2]
  A1 --> MCU[STM32L432KCU6\n80 MHz ADC clock target\n3.2 Msps aggregate target]
  A2 --> MCU

  USB[USB-C VBUS + USB FS] --> ESD[USBLC6-2SC6]
  ESD --> MCU
  USB --> PF[MF-PSMF035X-2] --> V5[Protected VBUS]
  V5 --> LDO[AP7361C 3.3 V]
  V5 --> PM[AO3401A P-MOS high-side switch\n100 kΩ gate pull-up = default OFF]
  PM --> BR[27 Ω, 0.5 W provisional] --> BL[ERM19296-1 LEDA pin 5]
  BL --> GND[LCD pin 6 VSS\nsolid common ground/return]
  LDO --> MCU
  LDO --> VDDA[Filtered VDDA]
  VDDA --> C1
  VDDA --> C2
  LDO --> OP[TLV9062]
  LDO --> LCD[ERM19296-1 exact\n4-wire SPI, 1x20 2.54 mm]
  MCU --> LCD
  MCU -->|PWM high = ON\n100 Ω gate series| NM[2N7002KT1G\n100 kΩ gate pulldown]
  NM -->|pulls P-MOS gate low| PM

  MTX[MCU TX] -->|VCP_TARGET_TX_TO_PROBE_RX| PRX[STDC14 probe RX]
  PTX[STDC14 probe TX] -->|VCP_PROBE_TX_TO_TARGET_RX| MRX[MCU RX]
```

## Timing and rating annotations

- ADC sequence target: CH1 rank 1 then CH2 rank 2.
- Target timing: 12.5-cycle sample + 12.5-cycle conversion at 80 MHz, giving 312.5 ns skew and 1.6 Msps/channel at 3.2 Msps aggregate.
- These timing values require firmware and bench confirmation.
- Normal measurement rating is 0–12 V DC. Fifteen-volt survival is an unverified overload target, not a rating.

## Ground and safety

BNC shells, AGND/PCB ground, MCU ground, and USB ground are common. Rev 0.2 remains non-isolated and has no CAT, mains, high-energy, or negative-input rating.

Detailed interface pin dispositions and verification gates: [MVP Design Decisions](https://www.flux.ai/nbean/oscilloscope/files/mvp-design-decisions).

The high-side switch preserves the required solid VSS/backlight return on pin 6. The 27 Ω value remains provisional pending exact module Vf/current measurement, 60–75 mA acceptance, and resistor/MOSFET thermal verification. **No true schematic-capture blocker remains identified.**

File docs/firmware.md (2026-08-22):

# Firmware Getting Started

## Rev 0.2 MCU pin map

| STM32L432 pin | Function | Schematic net |
|---|---|---|
| PA0 / ADC1_IN5 | CH1 ADC, sequence rank 1 | CH1_ADC |
| PA1 / ADC1_IN6 | CH2 ADC, sequence rank 2 | CH2_ADC |
| PA2 / USART2_TX | Target TX to probe RX | VCP_TARGET_TX_TO_PROBE_RX |
| PA3 / USART2_RX | Probe TX to target RX | VCP_PROBE_TX_TO_TARGET_RX |
| PA4 / SPI1_NSS | LCD chip select | LCD_CS |
| PA5 / SPI1_SCK | LCD serial clock | LCD_SCK |
| PA7 / SPI1_MOSI | LCD serial data; module DB3–DB1 tied | LCD_MOSI |
| PA8 / TIM1_CH1 | Backlight PWM, active high | LCD_BL_PWM |
| PA11 / USB_DM | Native USB FS D− | USB_DM |
| PA12 / USB_DP | Native USB FS D+ | USB_DP |
| PA13 | SWDIO | SWDIO |
| PA14 | SWCLK | SWCLK |
| PA15 | USB/activity LED | LED_USB_DRV |
| PB0 | LCD A0/RS data-command | LCD_DC |
| PB1 | LCD reset | LCD_RST |
| PB3 | RUN/STOP button, active low | BTN_RUN_STOP |
| PB4 | MODE button, active low | BTN_MODE |
| PB5 | SELECT button, active low | BTN_SELECT |
| PB6 | RUN LED | LED_RUN_DRV |
| PB7 | TRIGGER/ARM LED | LED_TRIGGER_DRV |

PA6, PA9, PA10, PC14 and PC15 are intentionally unused in Rev 0.2.

## Required peripheral setup

- System clock: HSI-based plan; verify the final clock tree and USB clock in STM32CubeMX.
- ADC1: asynchronous clock target 80 MHz; regular sequence IN5 rank 1 then IN6 rank 2; 12.5-cycle sample time; timer-triggered DMA circular operation; target 3.2 Msps aggregate.
- USB device: PA11/PA12 native USB FS.
- SPI1 transmit-only: PA5 SCK, PA7 MOSI; GPIO controls PA4 CS, PB0 A0/RS, PB1 reset.
- TIM1_CH1: PA8 PWM. Logic high commands backlight ON.
- USART2: PA2 TX and PA3 RX, with the direction-explicit STDC14 crossover nets.
- Buttons: GPIO inputs with active-low interpretation; external 10 kΩ pull-ups and 100 Ω/100 nF filters are fitted.
- LEDs: PB6, PB7 and PA15 are active-high outputs; the power LED is rail-driven.

## Startup order

1. Configure power/flash latency and HSI clock tree.
2. Initialize GPIO default states: LCD CS high, LCD reset high after reset pulse, PA8 low, status LEDs off.
3. Start USB device and USART2 VCP test path.
4. Initialize SPI1 and the ERM19296-1 in 4-wire serial mode.
5. Calibrate and configure ADC1, timer trigger and circular DMA.
6. Enable button processing and acquisition state machine.

## Bring-up notes

- Confirm ADC rank order by register readback before interpreting interleaved samples.
- Keep the backlight off before USB configuration.
- The compensation, bandwidth, 15 V overload, HSI accuracy and backlight-current targets are prototype verification gates, not firmware-assumed verified performance.

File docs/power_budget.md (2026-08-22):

# Power Budget

## Revision boundary

Rev 0.2 values are approved planning targets for schematic capture, not measured results. The LCD backlight is supplied directly from protected VBUS; only logic and analog circuitry use the 3.3 V LDO.

## Rev 0.2 budget

| Load | Typical/planning | Design/validation |
|---|---:|---:|
| STM32L432KCU6 | 12 mA | 25 mA allowance |
| TLV9062 dual | 1.1 mA | 1.5 mA allowance |
| LCD logic | 5 mA planning | 15 mA allowance |
| Four indicator LEDs | up to 24 mA | 24 mA |
| Miscellaneous | 3–5 mA | included in rail totals |
| **3.3 V rail** | **about 50 mA** | **70 mA design; 100 mA validation case** |
| LCD backlight from protected VBUS | **60–75 mA acceptance band** | **75 mA budget** |

## Correct USB-current derivation

An LDO input current is approximately its output current plus its quiescent current. It is not calculated by ideal power conversion. The backlight current is separately drawn directly from VBUS.

Using rounded rail values and neglecting the small LDO quiescent current:

- **Typical:** `50 mA LDO input + 75 mA backlight = 125 mA USB`.
- **Design:** `70 mA + 75 mA = 145 mA USB`.
- **Validation case:** `100 mA + 75 mA = 175 mA USB`.

Backlight is held off until USB configuration; pre-enumeration target remains <100 mA.

## LDO thermal planning

At 5.0 V input and 3.3 V output:

- 50 mA → `(5.0−3.3)×0.050 = 85 mW`.
- 70 mA → **119 mW**.
- 100 mA → **170 mW**.

These are calculated dissipation targets. AP7361C case temperature, closed-enclosure temperature rise, and 3.3 V regulation under maximum load remain prototype verification gates.

## Backlight value-selection gate

Protected VBUS feeds an AO3401A P-MOS high-side switch, then the provisional **27 Ω, 0.5 W** resistor, then ERM19296-1 LEDA pin 5. Pin 6 VSS remains solid ground. A 2N7002KT1G level-shift/inverter pulls the P-MOS gate low; **MCU PWM high means backlight ON**. Static pull-up current while on is approximately `5 V / 100 kΩ = 50 µA`, negligible in the rounded USB totals.

At 75 mA, AO3401A conduction loss using its 60 mΩ maximum RDS(on) at −4.5 V is about `I²R = 0.075²×0.060 = 0.34 mW`. The 2N7002 carries only the approximately 50 µA pull-up current in steady state, so its conduction loss is negligible. The resistor worst-case planning dissipation at 75 mA is `I²R = 0.075²×27 = 152 mW`, below its 0.5 W rating but still subject to board/enclosure thermal verification.

**27 Ω remains an initial tuning value, not a final electrical acceptance.** Measure the exact ordered module Vf/current and retain or replace the resistor so maximum-brightness current is **60–75 mA**. Verify resistor, P-MOS, LCD, and enclosure temperatures. This correction removes the backlight schematic-capture blocker without changing the 75 mA current budget.

## Protected power path gates

PPTC voltage drop/nuisance trip, VBUS hot-plug overshoot, TVS behavior, regulator thermal performance, and USB ESD performance remain unverified prototype gates.

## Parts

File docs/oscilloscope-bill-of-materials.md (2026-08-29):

# Bill of Materials

## Live design basis — 2026-08-28

The Oscilloscope design contains **101 schematic components and 57 nets**. It implements the STM32L432KCU6 internal-ADC MVP architecture. This file is a curated BOM guide; the generated BOM remains the export source of truth and must be reviewed before release.

## Principal fitted parts

- U1: STM32L432KCU6, UFQFPN-32.
- U2: AP7361C-33Y5-13 3.3 V LDO.
- U3: TLV9062IDGKR dual op amp, VSSOP-8.
- Q1: NCE3401 P-channel high-side backlight switch.
- Q2: 2N7002KT1G gate pull-down.
- J1: USB4215-03-A USB-C receptacle; J2/J3: Molex 0731000105 BNC; J4: SSW-120-01-T-S LCD socket; J5: FTSH-107-01-L-DV-K-P-TR debug header.
- TP_GND: Keystone 4952 physical test point; **include in BOM and pick-and-place**.

## Critical fitted passives

| Designators | Value / MPN | Status |
|---|---|---|
| R7–R9, R13–R15 | 300 kΩ Vishay TNPW1206300KBYEA | Fitted precision high arms |
| R10, R16 | 200 kΩ Vishay TNPW1206200KBYEA | Fitted precision low arms |
| R12, R18 | **47 Ω Yageo RC0603FR-0747RL** | Fitted ADC isolation resistors |
| C18, C25 | 1.0 nF KEMET C0603C102J5GACTU | Fitted ADC capacitors |
| R19 | 27 Ω Yageo RC2010FK-0727RL | Fitted provisional backlight value; validate operating point |

## DNI and fabricated-feature exclusions

- **DNI:** C16, C17, C23, and C24; exclude from BOM and pick-and-place.
- Fourteen 1.0 × 1.0 mm fabricated PCB test pads currently appear as BOM elements and are an **SMT assembly blocker**: TP_3V3, TP_CH1_DIV, TP_USB_DM, TP_CH1_IN, TP_VBUS_RAW, TP_BL_K, TP_USB_DP, TP_CH2_DIV, TP_NRST, TP_VDDA, TP_CH1_ADC, TP_CH2_ADC, TP_CH2_IN, TP_VBUS_PROT. Exclude all fourteen from BOM and pick-and-place.
- TP_GND is not one of the fabricated pads and remains included.

## Manufacturing status

The 100 × 100 mm PCB uses four copper layers and a nominal 1.30 mm custom stackup; all 101 components are top-side. Routing is complete with zero airwires and zero DRC errors. The configured USB target is 45 Ω single-ended / 90 Ω differential and requires fabricator confirmation; it is not measured or certified impedance. Protected dangling-trace warnings `Trace a4ae` and `Trace b74f` require Gerber cleanup or explicit waiver.

## Claim boundary

BOM selection and implementation do not establish measured bandwidth, divider compensation, 15 V overload survival, backlight operating point, USB ESD/hot-plug robustness, ADC timing, thermals, HSI accuracy, certification, or production readiness.

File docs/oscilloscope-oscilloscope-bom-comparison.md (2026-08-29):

# Oscilloscope BOM Comparison

## Locked architectural conclusion

The comparison design's external LTC2267 ADC, high-speed amplifiers, bipolar rails, FPGA/PMOD-style host assumptions, and high placement count are **not adopted** for the implemented Oscilloscope MVP. The live design uses 101 components and 57 nets and retains the STM32L432KCU6 internal ADC, standalone LCD/buttons/LEDs, native USB, and two BNC channels.

The transferable lessons—defined attenuation, protection, buffering, deliberate filtering, calibration, test points, grounding, and power integrity—are incorporated in [MVP Design Decisions](https://www.flux.ai/nbean/oscilloscope/files/mvp-design-decisions).

## Rev 0.2 answer to the comparison

| Comparison topic | Rev 0.2 MVP choice |
|---|---|
| ADC/host | Keep STM32 internal 12-bit ADC, DMA, native USB, LCD/UI |
| Channels | Keep two sequentially sampled channels; disclose 312.5 ns nominal skew |
| Input | Two identical 1.10 MΩ, 5.5:1, 0–12 V normal channels |
| Protection | Split precision divider, BAV199 low-leakage clamps, buffered ADC input; ELV-only, no CAT rating |
| Amplifier | One TLV9062IDGKR dual 10 MHz RRIO VSSOP-8 |
| Filter | 47 Ω/1 nF per channel plus compensated divider; bandwidth remains unmeasured |
| Trigger | Software rising/falling Auto/Normal/Single with circular pretrigger |
| Clock | HSI retained; USB-SOF/factory correction instead of HSE for MVP |
| Power | Existing AP7361C retained; backlight moved to protected VBUS |
| Calibration | External precision DC/square-wave procedure; coefficients stored in MCU flash |
| Complexity | No external ADC, FPGA, bipolar rail, GDT, PMOD host, or high-speed differential ADC driver |

## Implementation and verification boundary

The internal-ADC MVP architecture and 47 Ω ADC isolation resistors are implemented. R12 and R18 are Yageo RC0603FR-0747RL. This does not establish measured bandwidth, compensated-divider performance, overload survival, timing accuracy, thermals, USB robustness, or certified impedance.

The PCB is 100 × 100 mm, four copper layers, nominal 1.30 mm custom stackup, with all 101 components top-side. Routing is complete with zero airwires and zero DRC errors; two protected legacy dangling-trace warnings remain (`Trace a4ae`, `Trace b74f`).

## Deferred comparison-design features

External ADC/FPGA, simultaneous sampling, bipolar inputs/rails, multiple ranges, AC coupling, hardware trigger, high-order filtering, onboard calibration source, and GDT/surge-rated protection remain deferred until a future product requirement justifies their cost and validation burden.

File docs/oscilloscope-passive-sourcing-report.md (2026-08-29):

# Passive Sourcing Report

## Scope and result

All **63 generic passives** have specified manufacturer part numbers: **33 resistors** and **30 capacitors**. Existing values, connectivity, and footprints are preserved. The live DNI set is **C16, C17, C23, and C24**, excluded from BOM and pick-and-place.

## Grouped production selections

| Manufacturer | MPN | Value / rating / dielectric | Package | Designators |
|---|---|---|---|---|
| Yageo | RC0603FR-075K1L | 5.1 kΩ, 1%, 0.1 W, thick film | 0603 | R1, R2 |
| Yageo | RC0603JR-070RL | 0 Ω jumper, 0.1 W | 0603 | R3, R33 |
| Yageo | RC0603FR-07100KL | 100 kΩ, 1%, 0.1 W, thick film | 0603 | R4, R20, R22 |
| Yageo | RC0603FR-0710KL | 10 kΩ, 1%, 0.1 W, thick film | 0603 | R5, R6, R11, R17, R23, R25, R27 |
| Vishay | TNPW1206300KBYEA | 300 kΩ, 0.1%, 10 ppm/°C, 200 V, 0.52 W, thin film | 1206 | R7–R9, R13–R15 |
| Vishay | TNPW1206200KBYEA | 200 kΩ, 0.1%, 10 ppm/°C, 200 V, 0.52 W, thin film | 1206 | R10, R16 |
| Yageo | RC0603FR-0747RL | 47 Ω, 1%, 0.1 W, thick film | 0603 | R12, R18 |
| Yageo | RC2010FK-0727RL | 27 Ω, 1%, 0.75 W, thick film; value remains provisional in Role Details | 2010 | R19 |
| Yageo | RC0603FR-07100RL | 100 Ω, 1%, 0.1 W, thick film | 0603 | R21, R24, R26, R28 |
| Yageo | RC0603FR-07200RL | 200 Ω, 1%, 0.1 W, thick film | 0603 | R29–R32 |
| TDK | C2012X7R1E475K125AB | 4.7 µF, 25 V, ±10%, X7R | 0805 | C1, C2, C5 |
| TDK | C1608X7R1H104K080AA | 100 nF, 50 V, ±10%, X7R | 0603 | C3, C4, C6, C10, C11, C26, C28–C30 |
| TDK | C1608X7R1E105K080AB | 1 µF, 25 V, ±10%, X7R | 0603 | C7, C9, C27 |
| TDK | C1608X7R1H103K080AA | 10 nF, 50 V, ±10%, X7R | 0603 | C8 |
| KEMET | C0603C120J5GACTU | 12 pF, 50 V, ±5%, C0G/NP0 | 0603 | C12–C14, C19–C21 |
| KEMET | C0603C829C5GACTU | 8.2 pF, 50 V, ±0.25 pF, C0G/NP0 | 0603 | C15, C22 |
| KEMET | C0603C229C5GACTU | 2.2 pF, 50 V, ±0.25 pF, C0G/NP0, DNI | 0603 | C16, C23 |
| KEMET | C0603C479C5GACTU | 4.7 pF, 50 V, ±0.25 pF, C0G/NP0, DNI | 0603 | C17, C24 |
| KEMET | C0603C102J5GACTU | 1.0 nF, 50 V, ±5%, C0G/NP0 | 0603 | C18, C25 |

## Selection notes

- Precision divider parts exceed the locked requirements: 0.1% tolerance, 10 ppm/°C TCR, 200 V rating, and 0.52 W in the existing 1206 footprint. Substitution is disabled.
- C1 and C2 retain the 4.7 µF nominal value and 0805 footprint, but use a 25 V X7R part to improve DC-bias margin relative to a 16 V selection. Substitution is disabled for the regulator input/output pair.
- Analog compensation and ADC-filter C0G parts have substitution disabled.
- R12 and R18 use 47 Ω after ADC acquisition-settling simulation showed the original 330 Ω value produced approximately 9.5–9.9 LSB of external settling error at the locked 12.5-cycle sample time. The implemented 47 Ω/1 nF network models at 0.558 LSB worst case.
- Commodity pull, damping, LED, gate, debounce, and decoupling parts allow same-spec substitutes.
- C16, C17, C23, and C24 are the live DNI parts and must remain excluded from BOM and pick-and-place.

## Final verification

| Review | Open error/warning findings |
|---|---:|
| Manufacturer Part Number manufacturing review | 0 |
| Capacitor voltage rating review | 0 |
| Resistor power rating review | 0 |
| Parts availability review | 0 |
| Missing footprint review | 0 |
| Current PCB routing | 0 airwires; 0 DRC errors; 2 protected dangling-trace warnings |

The intended assembly population is **33 resistors and 26 capacitors**, with C16/C17/C23/C24 excluded. Fourteen fabricated 1.0 × 1.0 mm PCB test pads are also currently BOM elements and must be excluded from BOM and pick-and-place; TP_GND stays included.

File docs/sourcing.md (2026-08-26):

# Passive Sourcing Report

## Scope and result

All **63 generic passives** in Oscilloscope Rev 0.2 now have an exact production manufacturer part number: **33 resistors** and **30 capacitors**. Existing values, connectivity, and footprints were preserved. The four optional trim capacitors remain DNI and are excluded from both BOM and pick-and-place outputs.

## Grouped production selections

| Manufacturer | MPN | Value / rating / dielectric | Package | Designators |
|---|---|---|---|---|
| Yageo | RC0603FR-075K1L | 5.1 kΩ, 1%, 0.1 W, thick film | 0603 | R1, R2 |
| Yageo | RC0603JR-070RL | 0 Ω jumper, 0.1 W | 0603 | R3, R33 |
| Yageo | RC0603FR-07100KL | 100 kΩ, 1%, 0.1 W, thick film | 0603 | R4, R20, R22 |
| Yageo | RC0603FR-0710KL | 10 kΩ, 1%, 0.1 W, thick film | 0603 | R5, R6, R11, R17, R23, R25, R27 |
| Vishay | TNPW1206300KBYEA | 300 kΩ, 0.1%, 10 ppm/°C, 200 V, 0.52 W, thin film | 1206 | R7–R9, R13–R15 |
| Vishay | TNPW1206200KBYEA | 200 kΩ, 0.1%, 10 ppm/°C, 200 V, 0.52 W, thin film | 1206 | R10, R16 |
| Yageo | RC0603FR-0747RL | 47 Ω, 1%, 0.1 W, thick film | 0603 | R12, R18 |
| Yageo | RC2010FK-0727RL | 27 Ω, 1%, 0.75 W, thick film; value remains provisional in Role Details | 2010 | R19 |
| Yageo | RC0603FR-07100RL | 100 Ω, 1%, 0.1 W, thick film | 0603 | R21, R24, R26, R28 |
| Yageo | RC0603FR-07200RL | 200 Ω, 1%, 0.1 W, thick film | 0603 | R29–R32 |
| TDK | C2012X7R1E475K125AB | 4.7 µF, 25 V, ±10%, X7R | 0805 | C1, C2, C5 |
| TDK | C1608X7R1H104K080AA | 100 nF, 50 V, ±10%, X7R | 0603 | C3, C4, C6, C10, C11, C26, C28–C30 |
| TDK | C1608X7R1E105K080AB | 1 µF, 25 V, ±10%, X7R | 0603 | C7, C9, C27 |
| TDK | C1608X7R1H103K080AA | 10 nF, 50 V, ±10%, X7R | 0603 | C8 |
| KEMET | C0603C120J5GACTU | 12 pF, 50 V, ±5%, C0G/NP0 | 0603 | C12–C14, C19–C21 |
| KEMET | C0603C829C5GACTU | 8.2 pF, 50 V, ±0.25 pF, C0G/NP0 | 0603 | C15, C22 |
| KEMET | C0603C229C5GACTU | 2.2 pF, 50 V, ±0.25 pF, C0G/NP0, DNI | 0603 | C16, C23 |
| KEMET | C0603C479C5GACTU | 4.7 pF, 50 V, ±0.25 pF, C0G/NP0, DNI | 0603 | C17, C24 |
| KEMET | C0603C102J5GACTU | 1.0 nF, 50 V, ±5%, C0G/NP0 | 0603 | C18, C25 |

## Selection notes

- Precision divider parts exceed the locked requirements: 0.1% tolerance, 10 ppm/°C TCR, 200 V rating, and 0.52 W in the existing 1206 footprint. Substitution is disabled.
- C1 and C2 retain the 4.7 µF nominal value and 0805 footprint, but use a 25 V X7R part to improve DC-bias margin relative to a 16 V selection. Substitution is disabled for the regulator input/output pair.
- Analog compensation and ADC-filter C0G parts have substitution disabled.
- R12 and R18 use 47 Ω after ADC acquisition-settling simulation showed the original 330 Ω value produced approximately 9.5–9.9 LSB of external settling error at the locked 12.5-cycle sample time. The implemented 47 Ω/1 nF network models at 0.558 LSB worst case.
- Commodity pull, damping, LED, gate, debounce, and decoupling parts allow same-spec substitutes.
- C16, C17, C23, and C24 retain `Exclude from BOM: true` and now also have `Exclude from Pick & Place: true`, while retaining documented optional-population MPNs.

## Final verification

| Review | Open error/warning findings |
|---|---:|
| Manufacturer Part Number manufacturing review | 0 |
| Capacitor voltage rating review | 0 |
| Resistor power rating review | 0 |
| Parts availability review | 0 |
| Missing footprint review | 0 |
| ERC review set | 0 |

BOM summary shows **33 resistor instances** and **26 populated capacitor instances**. The difference from 30 schematic capacitors is the four intentionally excluded DNI trim capacitors. No package changes were required, and every selected MPN package agrees with its existing 0603, 0805, 1206, or 2010 footprint.

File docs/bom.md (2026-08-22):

# Bill of Materials

## Revision boundary

This is the Rev 0.2 delta approved for schematic capture. It is not yet implemented or tested.

## Retained principal parts

- STM32L432KCU6, UFQFPN32.
- AP7361C-33Y5-13 3.3 V LDO.
- Exact **ERM19296-1, “4-Wire SPI Pin Header Connection”** procurement option.
- Existing USB-C receptacle, two BNCs, STDC14, buttons, and LEDs.

## Locked Rev 0.2 additions/changes

| Block | Exact part/value or approved requirement | Qty | Note |
|---|---|---:|---|
| Dual input buffer | TLV9062IDR, TI, SOIC-8 | 1 | One channel per input |
| High divider | 300 kΩ, 0.1%, ≤25 ppm/°C, 1206, ≥100 V working, pulse-rated | 6 | Three in series per channel; combined arm remains ±0.1% |
| Low divider | 200 kΩ, 0.1%, ≤25 ppm/°C, 1206 | 2 | One per channel |
| High compensation | 12 pF C0G, ≥50 V | 6 | Across each 300 kΩ |
| Low compensation | 8.2 pF C0G fitted; 2.2 pF and 4.7 pF C0G DNI | 2 fitted + 4 DNI | Prototype trim gate |
| Rail clamps | BAV199LT1G, onsemi, SOT-23 | 2 | Pin 1→AGND; pin 3→CHx_CLAMP; pin 2→VDDA; both diodes used |
| Clamp-to-buffer | 10 kΩ, 1% | 2 | CHx_CLAMP to TLV9062 non-inverting input |
| ADC isolation/filter | 330 Ω, 1% + 1.0 nF C0G | 2 each | To PA0/ADC1_IN5 and PA1/ADC1_IN6 |
| Op-amp decoupling | 100 nF X7R | 1 | Close to TLV9062 supply |
| USB data ESD | USBLC6-2SC6 | 1 | Prototype ESD performance gate |
| VBUS PPTC | MF-PSMF035X-2 | 1 | 0.35 A hold |
| VBUS TVS | SMAJ5.0A-TR | 1 | Hot-plug behavior remains a gate |
| VBUS input capacitor | 4.7 µF X7R, ≥16 V | 1 replacement | Account for DC bias |
| Backlight high-side MOSFET | AO3401A, Alpha & Omega Semiconductor, P-channel, SOT-23 | 1 | Source to protected VBUS; drain to backlight resistor; −30 V VDS, ±12 V VGS, ≤60 mΩ at VGS = −4.5 V |
| Backlight gate-pull N-MOS | 2N7002KT1G, onsemi, SOT-23 | 1 | Drain pulls AO3401A gate low; source to GND; 60 V VDS, ±20 V VGS |
| Backlight resistor | 27 Ω, 0.5 W initial prototype value | 1 | Select final value for 60–75 mA; value is not architecture-locked |
| P-MOS gate pull-up | 100 kΩ | 1 | AO3401A gate to protected VBUS; default OFF |
| N-MOS gate parts | 100 Ω series, 100 kΩ pulldown | 1 each | MCU PWM through 100 Ω; 2N7002 gate to GND through 100 kΩ; PWM high = ON |
| NRST capacitor | 100 nF X7R | 1 | — |
| VDDA ferrite | BLM21PG221SN1D-class | 1 | — |
| VDDA/VREF capacitors | VDDA 100 nF + 1 µF; VREF+ 10 nF + 1 µF | as required | — |
| Button RC | 100 Ω series + 100 nF to ground | 3 each | — |

## LCD connector/interface capture

The exact 4-wire SPI module option uses a **1×20, 2.54 mm-pitch pin header**. Capture: pins 1–4 optional font-chip interface (NC unless ordered/used); pin 5 LEDA; pin 6 VSS, also the documented backlight return; pin 7 VDD; pin 8 A0/RS; pin 9 RSTB; pin 10 CSB; pins 11–14 DB7–DB4 tied to VDD; pins 15–17 DB3–DB1 tied together as MOSI/SDA; pin 18 DB0 as SCK/SCL; pins 19–20 ERD/RWR tied to VDD. Ordered interface selection is IF2:IF1:IF0 = L:L:L. No separate LEDK connector pin is documented.

## Removed items

- **Remove both TS-107-T-AA headers.** They are not present in the Rev 0.2 BOM or schematic.
- Remove the invalid AO3400A low-side backlight switch and any switched-return/LEDK net. Retain LCD pin 6 as solid ground.

## Net labels affecting capture

- CH1 ADC: PA0 / ADC1_IN5, rank 1.
- CH2 ADC: PA1 / ADC1_IN6, rank 2.
- VCP: `VCP_TARGET_TX_TO_PROBE_RX` and `VCP_PROBE_TX_TO_TARGET_RX`.

**Remaining capture blocker:** none identified. Capture the protected-5-V AO3401A/2N7002KT1G high-side PWM circuit exactly as specified; 27 Ω selection and thermal acceptance remain prototype gates.

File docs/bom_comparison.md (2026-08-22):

# Oscilloscope BOM Comparison

## Locked architectural conclusion

The comparison design's external LTC2267 ADC, high-speed amplifiers, bipolar rails, FPGA/PMOD-style host assumptions, and high placement count are **not adopted** for Sillyscope Rev 0.2 MVP. Sillyscope retains the STM32L432KCU6 internal ADC and original standalone LCD/buttons/LEDs/native-USB/two-BNC architecture.

The transferable lessons—defined attenuation, protection, buffering, deliberate filtering, calibration, test points, grounding, and power integrity—are incorporated in [MVP Design Decisions](https://www.flux.ai/nbean/oscilloscope/files/mvp-design-decisions).

## Rev 0.2 answer to the comparison

| Comparison topic | Rev 0.2 MVP choice |
|---|---|
| ADC/host | Keep STM32 internal 12-bit ADC, DMA, native USB, LCD/UI |
| Channels | Keep two sequentially sampled channels; disclose 312.5 ns nominal skew |
| Input | Two identical 1.10 MΩ, 5.5:1, 0–12 V normal channels |
| Protection | Split precision divider, BAV199 low-leakage clamps, buffered ADC input; ELV-only, no CAT rating |
| Amplifier | One TLV9062IDR dual 10 MHz RRIO SOIC-8 |
| Filter | 330 Ω/1 nF per channel plus compensated divider; ~200 kHz expected useful bandwidth |
| Trigger | Software rising/falling Auto/Normal/Single with circular pretrigger |
| Clock | HSI retained; USB-SOF/factory correction instead of HSE for MVP |
| Power | Existing AP7361C retained; backlight moved to protected VBUS |
| Calibration | External precision DC/square-wave procedure; coefficients stored in MCU flash |
| Complexity | No external ADC, FPGA, bipolar rail, GDT, PMOD host, or high-speed differential ADC driver |

## Important boundary

The Rev 0.1A schematic still has direct BNC-to-ADC paths and lacks these proposed additions. No Rev 0.2 capability or safety rating should be attributed to Rev 0.1A.

## Deferred comparison-design features

External ADC/FPGA, simultaneous sampling, bipolar inputs/rails, multiple ranges, AC coupling, hardware trigger, high-order filtering, onboard calibration source, and GDT/surge-rated protection remain deferred until a future product requirement justifies their cost and validation burden.

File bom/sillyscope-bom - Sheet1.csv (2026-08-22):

Part Number | Description | Manufacturer | Package | Designator | Quantity | Price (AUD) | Real Price (AUD) | URL
STM32L432KCU6 | STM32 Microcontroller | STMicroelectronics | UFQFPN | U1 | 1 | $7.57 | $7.57 | https://www.digikey.com.au/en/products/detail/stmicroelectronics/STM32L432KCU6/6132749
FTSH-107-01-L-DV-K-P | JTAG programming header | Samtec | SMD | J2 | 1 | $4.98 | $4.98 | https://www.digikey.com.au/en/products/detail/samtec-inc/FTSH-107-01-L-DV-K-P/7434355
GSB1C41110SSHR | USB-C Header | Amphenol ICC | SMD | J1 | 1 | $0.98 | $0.98 | https://www.digikey.com.au/en/products/detail/amphenol-cs-commercial-products/GSB1C41110SSHR/21623839
AP7361C-33Y5-13 | Linear Voltage Regulator 3.3V | Diodes Incorporated | SMD | U2 | 1 | $0.79 | $0.79 | https://www.digikey.com.au/en/products/detail/diodes-incorporated/AP7361C-33Y5-13/5638323
ERM19296-1 | LCD Display (ST75256, 4-Wire SPI) | EastRising | Breakout | LCD1 | 1 | $12.22 | $12.22 | https://www.buydisplay.com/2-8-inch-white-192x96-graphic-lcd-display-module-st75256-for-arduino
Y41A00517FPLFS | UI Push Button (Red) | C&K | Through-Hole | BTN3 | 1 | $2.56 | $2.56 | https://www.digikey.com.au/en/products/detail/c-k/Y41A00517FPLFS/1466332
Y41A00511FPLFS | UI Push Button (Black) | C&K | Through-Hole | BTN1,BTN2 | 2 | $2.56 | $5.12 | https://www.digikey.com.au/en/products/detail/c-k/Y41A00511FPLFS/1466335
LTL-4252N | LED Yellow (2.1V, Power) | Lite-On | Through-Hole | D1 | 1 | $0.30 | $0.30 | https://www.digikey.com.au/en/products/detail/liteon/LTL-4252N/214456
LTL-4238 | LED Green (2.1V, Channel) | Lite-On | Through-Hole | D2,D3 | 2 | $0.30 | $0.60 | https://www.digikey.com.au/en/products/detail/liteon/LTL-4238/217578
C503B-RCN-CW0Z0AA1 | LED Red (2.1V, Recording) | Cree LED | Through-Hole | D4 | 1 | $0.28 | $0.28 | https://www.digikey.com.au/en/products/detail/cree-led/C503B-RCN-CW0Z0AA1/1922930
CF14JT5K10 | 5.1kOhm Resistor | Stackpole | Through-Hole | R1,R2 | 2 | $0.16 | $0.32 | https://www.digikey.com.au/en/products/detail/stackpole-electronics-inc/CF14JT5K10/1741447
CF14JT10K0 | 10kOhm Resistor | Stackpole | Through-Hole | R3,R8,R9,R10,R11,R13 | 6 | $0.16 | $0.96 | https://www.digikey.com.au/en/products/detail/stackpole-electronics-inc/CF14JT10K0/1741265
KGM21NR71H104JT | 0.1uF Ceramic Cap (5%) | Kyocera | SMD (0805) | C5,C6,C7 | 3 | $0.17 | $0.51 | https://www.digikey.com.au/en/products/detail/kyocera-avx/KGM21NR71H104JT/929984
CONBNC001 | BNC Connector | TE Connectivity Linx | Through-Hole | J3,J4 | 2 | $2.78 | $5.56 | https://www.digikey.com.au/en/products/detail/te-connectivity-linx/CONBNC001/16013844
C0805C475J8RACAUTO | 4.7uF Ceramic Cap (5%) | KEMET | SMD (0805) | C1,C2,C8 | 3 | $0.89 | $2.67 | https://www.digikey.com.au/en/products/detail/kemet/C0805C475J8RACAUTO/7427538
CF14JT1K00 | 1kOhm Resistor (5%) | Stackpole | Through-Hole | R14,R15 | 2 | $0.16 | $0.32 | https://www.digikey.com.au/en/products/detail/stackpole-electronics-inc/CF14JT1K00/1741314
MBB02070C1000FCT00 | 100Ohm Resistor | Vishay | Through-Hole | R12 | 1 | $0.16 | $0.16 | https://www.digikey.com.au/en/products/detail/vishay-beyschlag-draloric-bc-components/MBB02070C1000FCT00/5062929
CF18JT200R | 200Ohm Resistor (5%) | Stackpole | Through-Hole | R4,R5,R6,R7 | 4 | $0.16 | $0.64 | https://www.digikey.com.au/en/products/detail/stackpole-electronics-inc/CF18JT200R/1741632
5000 | Test Point Header (Red) OPTIONAL | Keystone | Through-Hole | TP1,TP2 | 2 | $0.62 | $1.24 | https://www.digikey.com.au/en/products/detail/keystone-electronics/5000/255326
5001 | Test Point Header (Black) OPTIONAL | Keystone | Through-Hole | TP5 | 1 | $0.41 | $0.41 | https://www.digikey.com.au/en/products/detail/keystone-electronics/5001/255327
5009 | Test Point Header (Yellow) OPTIONAL | Keystone | Through-Hole | TP3,TP4 | 2 | $0.62 | $1.24 | https://www.digikey.com.au/en/products/detail/keystone-electronics/5009/362671
TS-107-T-AA | 7-Position Pin Header | Samtec | Through-Hole | N/A | 2 | $2.02 | $4.04 | https://www.digikey.com.au/en/products/detail/samtec-inc/TS-107-T-AA/10218878
STLINK-V3MINIESTM32 | STM32 Programmer | STMicroelectronics | N/A | N/A | 1 | $18.56 | $18.56 | https://www.digikey.com.au/en/products/detail/stmicroelectronics/stlink-v3minie/16284301
Totals (AUD) exc. Shipping |  |  |  |  | 43 |  | $72.03
Totals w/out Programmer (AUD) exc. Shipping |  |  |  |  | 42 |  | $53.47
Totals (USD) exc. Shipping |  |  |  |  |  |  | $47.56
Totals w/out Programmer (USD) exc. Shipping |  |  |  |  |  |  | $35.30

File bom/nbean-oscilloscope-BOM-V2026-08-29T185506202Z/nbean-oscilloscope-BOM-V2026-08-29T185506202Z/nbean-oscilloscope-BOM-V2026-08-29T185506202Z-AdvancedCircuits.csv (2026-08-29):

Component Description | QTY | Ref Des | Mfg P/N # | Manufacturer | Distributor P/N #
Non-Polarized Capacitor, 4.7uF, SMD_0805_2012Metric | 3 | C1,C2,C5 | C2012X7R1E475K125AB | TDK
Non-Polarized Capacitor, 10nF, SMD_0603_1608Metric | 1 | C8 | C1608X7R1H103K080AA | TDK
Non-Polarized Capacitor, 100nF, SMD_0603_1608Metric | 9 | C10,C11,C26,C28,C29,C3,C30,C4,C6 | C1608X7R1H104K080AA | TDK
Non-Polarized Capacitor, 12pF, SMD_0603_1608Metric | 6 | C12,C13,C14,C19,C20,C21 | C0603C120J5GACTU | KEMET
Non-Polarized Capacitor, 8.2pF, SMD_0603_1608Metric | 2 | C15,C22 | C0603C829C5GACTU | KEMET
Non-Polarized Capacitor, 1.0nF, SMD_0603_1608Metric | 2 | C18,C25 | C0603C102J5GACTU | KEMET
Non-Polarized Capacitor, 1uF, SMD_0603_1608Metric | 3 | C27,C7,C9 | C1608X7R1E105K080AB | TDK
Protection | 1 | D1 | USBLC6-2SC6 | STMicroelectronics
Diode, D_SMA | 1 | D2 | SMAJ5.0A-TR | STMicroelectronics
Diodes - General Purpose, SOT-23_L2.9-W1.3-P1.90-LS2.4-BR | 2 | D3,D4 | BAV199LT1G | onsemi(安森美)
Resettable Fuses, F0805 | 1 | F1 | MF-PSMF035X-2 | BOURNS
Ferrite Beads, L0805 | 1 | FB1 | BLM21PG221SZ1D | muRata(村田)
USB C, GCT_USB4215-03-A_REVA | 1 | J1 | USB4215-03-A | GCT
Connector | 2 | J2,J3 | 0731000105 | Molex
Connector | 1 | J4 | SSW-120-01-T-S | Samtec
Connector, FTSH-107-XX-YYY-DV-K-P-TR | 1 | J5 | FTSH-107-01-L-DV-K-P-TR | SAMTEC
LED, D_0603_1608Metric | 1 | LED1 | APTD1608CGCK | Kingbright
LED | 1 | LED2 | 150060RS75000 | Würth Elektronik
LED | 1 | LED3 | 150060YS75000 | Würth Elektronik
Light Emitting Diodes (LED), LED0603-RD | 1 | LED4 | LTST-C190TBKT | LITEON(光宝)
MOSFETs, SOT-23-3_L2.9-W1.6-P1.90-LS2.8-BR | 1 | Q1 | NCE3401 | NCE(无锡新洁能)
MOSFETs, SOT-23-3_L2.9-W1.3-P1.90-LS2.4-BR | 1 | Q2 | 2N7002KT1G | onsemi(安森美)
Resistor, 5.1kΩ, SMD_0603_1608Metric | 2 | R1,R2 | RC0603FR-075K1L | Yageo
Resistor, 0Ω, SMD_0603_1608Metric | 2 | R3,R33 | RC0603JR-070RL | Yageo
Resistor, 200kΩ, SMD_1206_3216Metric | 2 | R10,R16 | TNPW1206200KBYEA | Vishay
Resistor, 10kΩ, SMD_0603_1608Metric | 7 | R11,R17,R23,R25,R27,R5,R6 | RC0603FR-0710KL | Yageo
Resistor, 47Ω, SMD_0603_1608Metric | 2 | R12,R18 | RC0603FR-0747RL | Yageo
Resistor, 300kΩ, SMD_1206_3216Metric | 6 | R13,R14,R15,R7,R8,R9 | TNPW1206300KBYEA | Vishay
Resistor, 27Ω, SMD_2010_5025Metric | 1 | R19 | RC2010FK-0727RL | Yageo
Resistor, 100kΩ, SMD_0603_1608Metric | 3 | R20,R22,R4 | RC0603FR-07100KL | Yageo
Resistor, 100Ω, SMD_0603_1608Metric | 4 | R21,R24,R26,R28 | RC0603FR-07100RL | Yageo
Resistor, 200Ω, SMD_0603_1608Metric | 4 | R29,R30,R31,R32 | RC0603FR-07200RL | Yageo
Electromechanical Components | 3 | SW1,SW2,SW3 | 434123043816 | Würth
Connector | 14 | TP_3V3,TP_BL_K,TP_CH1_ADC,TP_CH1_DIV,TP_CH1_IN,TP_CH2_ADC,TP_CH2_DIV,TP_CH2_IN,TP_NRST,TP_USB_DM,TP_USB_DP,TP_VBUS_PROT,TP_VBUS_RAW,TP_VDDA | PCB-TESTPAD-1.0X1.0 | PCB Fabricated Feature
Test Points/Test Rings, CONN-TH_L3.0-W1.2 | 1 | TP_GND | 4952 | Keystone
ST Microelectronics, UFQFPN-32_L5.0-W5.0-P0.50-TL-EP3.5 | 1 | U1 | STM32L432KCU6 | ST(意法半导体)
Linear Voltage Regulators (LDO), SOT-89-5_L4.5-W2.5-P1.50-LS4.5-BR | 1 | U2 | AP7361C-33Y5-13 | DIODES(美台)
Operational Amplifier (OP-AMP), SOP65P490X110-8N | 1 | U3 | TLV9062IDGKR | Texas Instruments

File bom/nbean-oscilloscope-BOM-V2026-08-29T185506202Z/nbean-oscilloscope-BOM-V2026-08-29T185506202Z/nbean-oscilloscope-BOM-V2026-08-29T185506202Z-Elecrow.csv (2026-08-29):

*Reference | *Manufacturer Part number | *QTY | *Original | Description | Purchase Link
"C1 | C2 | C5" | "C2012X7R1E475K125AB" | "3" | "Y" | "A generic fixed capacitor ideal for rapid circuit topology development. You can choose between polarized and non-polarized types | its symbol and the footprint will automatically adapt based on your selection. Supported options include standard SMD sizes for ceramic capacitors (e.g. | 0402 | 0603 | 0805) | SMD sizes for aluminum electrolytic capacitors | and through-hole footprints for polarized capacitors.
Save precious design time by seamlessly add more information to this part (value | footprint | etc.) as it becomes available.
Standard capacitor values: 1.0pF | 10pF | 100pF | 1000pF | 0.01uF | 0.1uF | 1.0uF | 10uF | 100uF | 1000uF | 10000uF
1.1pF | 11pF | 110pF | 1100pF
1.2pF | 12pF | 120pF | 1200pF
1.3pF | 13pF | 130pF | 1300pF
1.5pF | 15pF | 150pF | 1500pF | 0.015uF | 0.15uF | 1.5uF | 15uF | 150uF | 1500uF
1.6pF | 16pF | 160pF | 1600pF
1.8pF | 18pF | 180pF | 1800pF
2.0pF | 20pF | 200pF | 2000pF
2.2pF | 22pF | 220pF | 2200pF | 0.022uF | 0.22uF | 2.2uF | 22uF | 220uF | 2200uF
2.4pF | 24pF | 240pF | 2400pF
2.7pF | 27pF | 270pF | 2700pF
3.0pF | 30pF | 300pF | 3000pF
3.3pF | 33pF | 330pF | 3300pF | 0.033uF | 0.33uF | 3.3uF | 33uF | 330uF | 3300uF
3.6pF | 36pF | 360pF | 3600pF
3.9pF | 39pF | 390pF | 3900pF
4.3pF | 43pF | 430pF | 4300pF
4.7pF | 47pF | 470pF | 4700pF | 0.047uF | 0.47uF | 4.7uF | 47uF | 470uF | 4700uF
5.1pF | 51pF | 510pF | 5100pF
5.6pF | 56pF | 560pF | 5600pF
6.2pF | 62pF | 620pF | 6200pF
6.8pF | 68pF | 680pF | 6800pF | 0.068uF | 0.68uF | 6.8uF | 68uF | 680uF | 6800uF
7.5pF | 75pF | 750pF | 7500pF
8.2pF | 82pF | 820pF | 8200pF
9.1pF | 91pF | 910pF | 9100pF #generics #CommonPartsLibrary" | ""
"C8" | "C1608X7R1H103K080AA" | "1" | "N" | "A generic fixed capacitor ideal for rapid circuit topology development. You can choose between polarized and non-polarized types | its symbol and the footprint will automatically adapt based on your selection. Supported options include standard SMD sizes for ceramic capacitors (e.g. | 0402 | 0603 | 0805) | SMD sizes for aluminum electrolytic capacitors | and through-hole footprints for polarized capacitors.
Save precious design time by seamlessly add more information to this part (value | footprint | etc.) as it becomes available.
Standard capacitor values: 1.0pF | 10pF | 100pF | 1000pF | 0.01uF | 0.1uF | 1.0uF | 10uF | 100uF | 1000uF | 10000uF
1.1pF | 11pF | 110pF | 1100pF
1.2pF | 12pF | 120pF | 1200pF
1.3pF | 13pF | 130pF | 1300pF
1.5pF | 15pF | 150pF | 1500pF | 0.015uF | 0.15uF | 1.5uF | 15uF | 150uF | 1500uF
1.6pF | 16pF | 160pF | 1600pF
1.8pF | 18pF | 180pF | 1800pF
2.0pF | 20pF | 200pF | 2000pF
2.2pF | 22pF | 220pF | 2200pF | 0.022uF | 0.22uF | 2.2uF | 22uF | 220uF | 2200uF
2.4pF | 24pF | 240pF | 2400pF
2.7pF | 27pF | 270pF | 2700pF
3.0pF | 30pF | 300pF | 3000pF
3.3pF | 33pF | 330pF | 3300pF | 0.033uF | 0.33uF | 3.3uF | 33uF | 330uF | 3300uF
3.6pF | 36pF | 360pF | 3600pF
3.9pF | 39pF | 390pF | 3900pF
4.3pF | 43pF | 430pF | 4300pF
4.7pF | 47pF | 470pF | 4700pF | 0.047uF | 0.47uF | 4.7uF | 47uF | 470uF | 4700uF
5.1pF | 51pF | 510pF | 5100pF
5.6pF | 56pF | 560pF | 5600pF
6.2pF | 62pF | 620pF | 6200pF
6.8pF | 68pF | 680pF | 6800pF | 0.068uF | 0.68uF | 6.8uF | 68uF | 680uF | 6800uF
7.5pF | 75pF | 750pF | 7500pF
8.2pF | 82pF | 820pF | 8200pF
9.1pF | 91pF | 910pF | 9100pF #generics #CommonPartsLibrary" | ""
"C10 | C11 | C26 | C28 | C29 | C3 | C30 | C4 | C6" | "C1608X7R1H104K080AA" | "9" | "N" | "A generic fixed capacitor ideal for rapid circuit topology development. You can choose between polarized and non-polarized types | its symbol and the footprint will automatically adapt based on your selection. Supported options include standard SMD sizes for ceramic capacitors (e.g. | 0402 | 0603 | 0805) | SMD sizes for aluminum electrolytic capacitors | and through-hole footprints for polarized capacitors.
Save precious design time by seamlessly add more information to this part (value | footprint | etc.) as it becomes available.
Standard capacitor values: 1.0pF | 10pF | 100pF | 1000pF | 0.01uF | 0.1uF | 1.0uF | 10uF | 100uF | 1000uF | 10000uF
1.1pF | 11pF | 110pF | 1100pF
1.2pF | 12pF | 120pF | 1200pF
1.3pF | 13pF | 130pF | 1300pF
1.5pF | 15pF | 150pF | 1500pF | 0.015uF | 0.15uF | 1.5uF | 15uF | 150uF | 1500uF
1.6pF | 16pF | 160pF | 1600pF
1.8pF | 18pF | 180pF | 1800pF
2.0pF | 20pF | 200pF | 2000pF
2.2pF | 22pF | 220pF | 2200pF | 0.022uF | 0.22uF | 2.2uF | 22uF | 220uF | 2200uF
2.4pF | 24pF | 240pF | 2400pF
2.7pF | 27pF | 270pF | 2700pF
3.0pF | 30pF | 300pF | 3000pF
3.3pF | 33pF | 330pF | 3300pF | 0.033uF | 0.33uF | 3.3uF | 33uF | 330uF | 3300uF
3.6pF | 36pF | 360pF | 3600pF
3.9pF | 39pF | 390pF | 3900pF
4.3pF | 43pF | 430pF | 4300pF
4.7pF | 47pF | 470pF | 4700pF | 0.047uF | 0.47uF | 4.7uF | 47uF | 470uF | 4700uF
5.1pF | 51pF | 510pF | 5100pF
5.6pF | 56pF | 560pF | 5600pF
6.2pF | 62pF | 620pF | 6200pF
6.8pF | 68pF | 680pF | 6800pF | 0.068uF | 0.68uF | 6.8uF | 68uF | 680uF | 6800uF
7.5pF | 75pF | 750pF | 7500pF
8.2pF | 82pF | 820pF | 8200pF
9.1pF | 91pF | 910pF | 9100pF #generics #CommonPartsLibrary" | ""
"C12 | C13 | C14 | C19 | C20 | C21" | "C0603C120J5GACTU" | "6" | "Y" | "A generic fixed capacitor ideal for rapid circuit topology development. You can choose between polarized and non-polarized types | its symbol and the footprint will automatically adapt based on your selection. Supported options include standard SMD sizes for ceramic capacitors (e.g. | 0402 | 0603 | 0805) | SMD sizes for aluminum electrolytic capacitors | and through-hole footprints for polarized capacitors.
Save precious design time by seamlessly add more information to this part (value | footprint | etc.) as it becomes available.
Standard capacitor values: 1.0pF | 10pF | 100pF | 1000pF | 0.01uF | 0.1uF | 1.0uF | 10uF | 100uF | 1000uF | 10000uF
1.1pF | 11pF | 110pF | 1100pF
1.2pF | 12pF | 120pF | 1200pF
1.3pF | 13pF | 130pF | 1300pF
1.5pF | 15pF | 150pF | 1500pF | 0.015uF | 0.15uF | 1.5uF | 15uF | 150uF | 1500uF
1.6pF | 16pF | 160pF | 1600pF
1.8pF | 18pF | 180pF | 1800pF
2.0pF | 20pF | 200pF | 2000pF
2.2pF | 22pF | 220pF | 2200pF | 0.022uF | 0.22uF | 2.2uF | 22uF | 220uF | 2200uF
2.4pF | 24pF | 240pF | 2400pF
2.7pF | 27pF | 270pF | 2700pF
3.0pF | 30pF | 300pF | 3000pF
3.3pF | 33pF | 330pF | 3300pF | 0.033uF | 0.33uF | 3.3uF | 33uF | 330uF | 3300uF
3.6pF | 36pF | 360pF | 3600pF
3.9pF | 39pF | 390pF | 3900pF
4.3pF | 43pF | 430pF | 4300pF
4.7pF | 47pF | 470pF | 4700pF | 0.047uF | 0.47uF | 4.7uF | 47uF | 470uF | 4700uF
5.1pF | 51pF | 510pF | 5100pF
5.6pF | 56pF | 560pF | 5600pF
6.2pF | 62pF | 620pF | 6200pF
6.8pF | 68pF | 680pF | 6800pF | 0.068uF | 0.68uF | 6.8uF | 68uF | 680uF | 6800uF
7.5pF | 75pF | 750pF | 7500pF
8.2pF | 82pF | 820pF | 8200pF
9.1pF | 91pF | 910pF | 9100pF #generics #CommonPartsLibrary" | ""
"C15 | C22" | "C0603C829C5GACTU" | "2" | "Y" | "A generic fixed capacitor ideal for rapid circuit topology development. You can choose between polarized and non-polarized types | its symbol and the footprint will automatically adapt based on your selection. Supported options include standard SMD sizes for ceramic capacitors (e.g. | 0402 | 0603 | 0805) | SMD sizes for aluminum electrolytic capacitors | and through-hole footprints for polarized capacitors.
Save precious design time by seamlessly add more information to this part (value | footprint | etc.) as it becomes available.
Standard capacitor values: 1.0pF | 10pF | 100pF | 1000pF | 0.01uF | 0.1uF | 1.0uF | 10uF | 100uF | 1000uF | 10000uF
1.1pF | 11pF | 110pF | 1100pF
1.2pF | 12pF | 120pF | 1200pF
1.3pF | 13pF | 130pF | 1300pF
1.5pF | 15pF | 150pF | 1500pF | 0.015uF | 0.15uF | 1.5uF | 15uF | 150uF | 1500uF
1.6pF | 16pF | 160pF | 1600pF
1.8pF | 18pF | 180pF | 1800pF
2.0pF | 20pF | 200pF | 2000pF
2.2pF | 22pF | 220pF | 2200pF | 0.022uF | 0.22uF | 2.2uF | 22uF | 220uF | 2200uF
2.4pF | 24pF | 240pF | 2400pF
2.7pF | 27pF | 270pF | 2700pF
3.0pF | 30pF | 300pF | 3000pF
3.3pF | 33pF | 330pF | 3300pF | 0.033uF | 0.33uF | 3.3uF | 33uF | 330uF | 3300uF
3.6pF | 36pF | 360pF | 3600pF
3.9pF | 39pF | 390pF | 3900pF
4.3pF | 43pF | 430pF | 4300pF
4.7pF | 47pF | 470pF | 4700pF | 0.047uF | 0.47uF | 4.7uF | 47uF | 470uF | 4700uF
5.1pF | 51pF | 510pF | 5100pF
5.6pF | 56pF | 560pF | 5600pF
6.2pF | 62pF | 620pF | 6200pF
6.8pF | 68pF | 680pF | 6800pF | 0.068uF | 0.68uF | 6.8uF | 68uF | 680uF | 6800uF
7.5pF | 75pF | 750pF | 7500pF
8.2pF | 82pF | 820pF | 8200pF
9.1pF | 91pF | 910pF | 9100pF #generics #CommonPartsLibrary" | ""
"C18 | C25" | "C0603C102J5GACTU" | "2" | "Y" | "A generic fixed capacitor ideal for rapid circuit topology development. You can choose between polarized and non-polarized types | its symbol and the footprint will automatically adapt based on your selection. Supported options include standard SMD sizes for ceramic capacitors (e.g. | 0402 | 0603 | 0805) | SMD sizes for aluminum electrolytic capacitors | and through-hole footprints for polarized capacitors.
Save precious design time by seamlessly add more information to this part (value | footprint | etc.) as it becomes available.
Standard capacitor values: 1.0pF | 10pF | 100pF | 1000pF | 0.01uF | 0.1uF | 1.0uF | 10uF | 100uF | 1000uF | 10000uF
1.1pF | 11pF | 110pF | 1100pF
1.2pF | 12pF | 120pF | 1200pF
1.3pF | 13pF | 130pF | 1300pF
1.5pF | 15pF | 150pF | 1500pF | 0.015uF | 0.15uF | 1.5uF | 15uF | 150uF | 1500uF
1.6pF | 16pF | 160pF | 1600pF
1.8pF | 18pF | 180pF | 1800pF
2.0pF | 20pF | 200pF | 2000pF
2.2pF | 22pF | 220pF | 2200pF | 0.022uF | 0.22uF | 2.2uF | 22uF | 220uF | 2200uF
2.4pF | 24pF | 240pF | 2400pF
2.7pF | 27pF | 270pF | 2700pF
3.0pF | 30pF | 300pF | 3000pF
3.3pF | 33pF | 330pF | 3300pF | 0.033uF | 0.33uF | 3.3uF | 33uF | 330uF | 3300uF
3.6pF | 36pF | 360pF | 3600pF
3.9pF | 39pF | 390pF | 3900pF
4.3pF | 43pF | 430pF | 4300pF
4.7pF | 47pF | 470pF | 4700pF | 0.047uF | 0.47uF | 4.7uF | 47uF | 470uF | 4700uF
5.1pF | 51pF | 510pF | 5100pF
5.6pF | 56pF | 560pF | 5600pF
6.2pF | 62pF | 620pF | 6200pF
6.8pF | 68pF | 680pF | 6800pF | 0.068uF | 0.68uF | 6.8uF | 68uF | 680uF | 6800uF
7.5pF | 75pF | 750pF | 7500pF
8.2pF | 82pF | 820pF | 8200pF
9.1pF | 91pF | 910pF | 9100pF #generics #CommonPartsLibrary" | ""
"C27 | C7 | C9" | "C1608X7R1E105K080AB" | "3" | "N" | "A generic fixed capacitor ideal for rapid circuit topology development. You can choose between polarized and non-polarized types | its symbol and the footprint will automatically adapt based on your selection. Supported options include standard SMD sizes for ceramic capacitors (e.g. | 0402 | 0603 | 0805) | SMD sizes for aluminum electrolytic capacitors | and through-hole footprints for polarized capacitors.
Save precious design time by seamlessly add more information to this part (value | footprint | etc.) as it becomes available.
Standard capacitor values: 1.0pF | 10pF | 100pF | 1000pF | 0.01uF | 0.1uF | 1.0uF | 10uF | 100uF | 1000uF | 10000uF
1.1pF | 11pF | 110pF | 1100pF
1.2pF | 12pF | 120pF | 1200pF
1.3pF | 13pF | 130pF | 1300pF
1.5pF | 15pF | 150pF | 1500pF | 0.015uF | 0.15uF | 1.5uF | 15uF | 150uF | 1500uF
1.6pF | 16pF | 160pF | 1600pF
1.8pF | 18pF | 180pF | 1800pF
2.0pF | 20pF | 200pF | 2000pF
2.2pF | 22pF | 220pF | 2200pF | 0.022uF | 0.22uF | 2.2uF | 22uF | 220uF | 2200uF
2.4pF | 24pF | 240pF | 2400pF
2.7pF | 27pF | 270pF | 2700pF
3.0pF | 30pF | 300pF | 3000pF
3.3pF | 33pF | 330pF | 3300pF | 0.033uF | 0.33uF | 3.3uF | 33uF | 330uF | 3300uF
3.6pF | 36pF | 360pF | 3600pF
3.9pF | 39pF | 390pF | 3900pF
4.3pF | 43pF | 430pF | 4300pF
4.7pF | 47pF | 470pF | 4700pF | 0.047uF | 0.47uF | 4.7uF | 47uF | 470uF | 4700uF
5.1pF | 51pF | 510pF | 5100pF
5.6pF | 56pF | 560pF | 5600pF
6.2pF | 62pF | 620pF | 6200pF
6.8pF | 68pF | 680pF | 6800pF | 0.068uF | 0.68uF | 6.8uF | 68uF | 680uF | 6800uF
7.5pF | 75pF | 750pF | 7500pF
8.2pF | 82pF | 820pF | 8200pF
9.1pF | 91pF | 910pF | 9100pF #generics #CommonPartsLibrary" | ""
"D1" | "USBLC6-2SC6" | "1" | "" | "17V Clamp 5A (8/20µs) Ipp Tvs Diode Surface Mount SOT-23-6 #C7519" | ""
"D2" | "SMAJ5.0A-TR" | "1" | "" | "13.4V Clamp 174A (8/20µs) Ipp Tvs Diode Surface Mount DO-214AC (SMA) #Commonpartslibrary
#Circuitprotection
#TVS
#Diode" | ""
"D3 | D4" | "BAV199LT1G" | "2" | "" | "Diodes - General Purpose
BAV199LT1G
SOT-23_L2.9-W1.3-P1.90-LS2.4-BR
LCSC Part Number: C145516
JLCPCB Part Class: Extended Part
Manufactured by onsemi(安森美) " | ""
"F1" | "MF-PSMF035X-2" | "1" | "" | "Resettable Fuses
MF-PSMF035X-2
F0805
LCSC Part Number: C116172
JLCPCB Part Class: Extended Part
Manufactured by BOURNS " | ""
"FB1" | "BLM21PG221SZ1D" | "1" | "" | "Ferrite Beads
BLM21PG221SZ1D
L0805
LCSC Part Number: C437411
JLCPCB Part Class: Extended Part
Manufactured by muRata(村田) " | ""
"J1" | "USB4215-03-A" | "1" | "" | "USB-C (USB TYPE-C) USB 2.0 Receptacle Connector 24 (16+8 Dummy) Position Surface Mount | Right Angle; Through Hole USB Type-C receptacle 16 pin USB2.0
The USB4215-03-A is a USB Type-C receptacle connector designed for USB 2.0 applications. It features a 16-pin configuration supporting reversible plug orientation with standard USB 2.0 differential data lines and configuration channel (CC) pins. The connector is intended for surface-mount PCB assembly with through-hole shell stakes for enhanced mechanical strength. It is widely used in compact embedded systems for power delivery | charging interfaces | and basic data communication.
Key Features
USB Type-C receptacle (USB 2.0 compliant)
16 functional pins (no SuperSpeed support)
Reversible plug orientation
Surface-mount contacts with through-hole shell tabs
Compact | low-profile design
High insertion cycle durability
Suitable for automated assembly
Electrical Characteristics
Rated Current:
VBUS: up to 5.0 A (depending on PCB design and cable)
Signal pins: 0.25 A max
Rated Voltage: 20 V DC max
Contact Resistance: ≤ 40 mΩ
Insulation Resistance: ≥ 100 MΩ
Dielectric Withstanding Voltage: 100 V AC
Mechanical Characteristics
Mounting Type: Surface Mount (SMT) with Through-Hole Shield Tabs
Number of Positions: 16
Mating Cycles: 10 | 000 cycles (typical)
Insertion Force: 5–20 N
Extraction Force: 8–20 N
Material Specifications
Contacts: Copper Alloy
Contact Plating: Gold over Nickel
Housing: High-temperature thermoplastic (UL94V-0)
Shell: Stainless Steel
Environmental Characteristics
Operating Temperature Range: -25°C to +85°C
Storage Temperature Range: -40°C to +85°C
RoHS Compliant: Yes
Halogen Free: Yes
Pin Configuration (USB 2.0 Type-C)
VBUS (Power)
GND (Ground)
D+ / D− (USB 2.0 differential pair)
CC1 / CC2 (Configuration channel)
SBU pins (optional/unused in USB 2.0 designs)
Applications
USB power input (5 V / USB-C PD trigger designs)
Embedded systems and development boards
Consumer electronics
Charging interfaces
Low-speed USB communication devices
Packaging
Tape & Reel for automated pick-and-place assembly
Compliance & Standards
USB Type-C Specification (USB 2.0 interface)
RoHS / REACH compliant
UL recognized materials
#CommonPartsLibrary #Connector #USB-C" | ""
"J2 | J3" | "0731000105" | "2" | "" | "BNC Connector Jack | Female Socket 50 Ohms Through Hole | Right Angle Solder #commonpartslibrary
#connector
#bnc
#femalesocket" | ""
"J4" | "SSW-120-01-T-S" | "1" | "" | "20 Position Receptacle Connector 0.100"" (2.54mm) Through Hole Tin
The SSW-120-01-T-S is a single-row | 20-position female (receptacle) socket strip with a 2.54 mm (0.1"") pitch | intended for through-hole PCB mounting. It uses Samtec’s Tiger Buy™ contact system | providing reliable electrical performance and durability for repeated mating cycles.
It is commonly used in embedded systems | development boards | and general PCB interconnections | especially where standard 0.1"" headers are required.
Female header 1x20 2.54mm
Key Features
Standard 2.54 mm Pitch
Industry-standard spacing compatible with most pin headers and prototyping systems
20 Positions | Single Row
Ideal for compact signal connections and header interfaces
Tiger Buy™ Contact System
Provides low insertion force and reliable electrical contact
Available in standard or low insertion force variants
Through-Hole Mounting
Ensures strong mechanical retention and durability on PCBs
Tin-Plated Contacts (T option)
Cost-effective plating suitable for general-purpose applications
High-Speed Capability
Supports signals up to ~8 Gbps | depending on application and layout
Wide Operating Temperature Range
Typically −55 °C to +105 °C | suitable for industrial environments
Material Construction
Contacts: Phosphor bronze
Insulator: High-temperature plastic (e.g. | LCP)
Versatile Mating Compatibility
Mates with common Samtec header series (TSW | MTSW | etc.) and standard 0.025"" square posts
#CommonPartsLibrary #Connector #SSW-120" | ""
"J5" | "FTSH-107-01-L-DV-K-P-TR" | "1" | "" | "Samtec | FTSH | 14 Way | 2 Row | Vertical Pin Header Connector Header Surface Mount 14 position 0.050"" (1.27mm) #CommonPartsLibrary #Connector #Header #FTSH" | ""
"LED1" | "APTD1608CGCK" | "1" | "" | "Green 570nm LED Indication - Discrete 2.1V 0603 (1608 Metric)
Green LED Chip LED | 1.6 × 0.8 mm SMD Package – APTD1608CGCK is a surface-mount green LED with a water-clear lens | designed for indicator applications. It features a 568 nm dominant wavelength | 20 mA forward current | 2.5 V typical forward voltage | and is housed in a 1608 (0603) package.
#LED #GreenLED #SMDLED #IndicatorLED #Kingbright #APTD1608CGCK
#commonpartslibrary
#optoelectronic
#led
#green" | ""
"LED2" | "150060RS75000" | "1" | "" | "Red 0603 SMD LED – Water-clear red chip LED designed for status indication and general-purpose PCB indicator applications. The Würth Elektronik 150060RS75000 uses AlInGaP chip technology | with a 625 nm dominant wavelength | 630 nm peak wavelength | and 140° viewing angle. At 20 mA | it has a typical 2 V forward voltage and 120–250 mcd luminous intensity. The device supports 30 mA continuous forward current | 100 mA peak forward current | and −40°C to +85°C operating temperature.
#WurthElektronik #150060RS75000 #LED #RedLED #0603LED #SMDLED #ChipLED #IndicatorLED #AlInGaP #PCBDesign" | ""
"LED3" | "150060YS75000" | "1" | "" | "Yellow 0603 SMD LED – Water-clear yellow chip LED designed for status indication and general-purpose PCB indicator applications. The Würth Elektronik 150060YS75000 uses AlInGaP chip technology | with a 590 nm dominant wavelength | 595 nm peak wavelength | and 140° viewing angle. At 20 mA | it has a typical 2 V forward voltage and 120–250 mcd luminous intensity. The device supports 30 mA continuous forward current | 100 mA peak forward current | and −40°C to +85°C operating temperature.
#WurthElektronik #150060YS75000 #LED #RedLED #0603LED #SMDLED #ChipLED #IndicatorLED #AlInGaP #PCBDesign" | ""
"LED4" | "LTST-C190TBKT" | "1" | "" | "Light Emitting Diodes (LED)
LTST-C190TBKT
LED0603-RD
LCSC Part Number: C125096
JLCPCB Part Class: Extended Part
Manufactured by LITEON(光宝) " | ""
"Q1" | "NCE3401" | "1" | "" | "MOSFETs
NCE3401
SOT-23-3_L2.9-W1.6-P1.90-LS2.8-BR
LCSC Part Number: C113490
JLCPCB Part Class: Extended Part
Manufactured by NCE(无锡新洁能) " | ""
"Q2" | "2N7002KT1G" | "1" | "" | "MOSFETs
2N7002KT1G
SOT-23-3_L2.9-W1.3-P1.90-LS2.4-BR
LCSC Part Number: C116584
JLCPCB Part Class: Extended Part
Manufactured by onsemi(安森美) " | ""
"R1 | R2" | "RC0603FR-075K1L" | "2" | "N" | "A generic fixed resistor ideal for rapid circuit topology development. Its footprint automatically adapts based on the selected package case code—supporting 0402 | 0603 | 0805 | 1203 | and many other standard SMD packages | as well as axial horizontal and vertical configurations.
Save precious design time by seamlessly add more information to this part (value | footprint | etc.) as it becomes available.
Standard resistor values:
1.0 ohm | 10 ohm | 100 ohm | 1.0k ohm | 10k ohm | 100k ohm | 1.0M ohm
1.1 ohm | 11 ohm | 110 ohm | 1.1k ohm | 11k ohm | 110k ohm | 1.1M ohm
1.2 ohm | 12 ohm | 120 ohm | 1.2k ohm | 12k ohm | 120k ohm | 1.2M ohm
1.3 ohm | 13 ohm | 130 ohm | 1.3k ohm | 13k ohm | 130k ohm | 1.3M ohm
1.5 ohm | 15 ohm | 150 ohm | 1.5k ohm | 15k ohm | 150k ohm | 1.5M ohm
1.6 ohm | 16 ohm | 160 ohm | 1.6k ohm | 16k ohm | 160k ohm | 1.6M ohm
1.8 ohm | 18 ohm | 180 ohm | 1.8K ohm | 18k ohm | 180k ohm | 1.8M ohm
2.0 ohm | 20 ohm | 200 ohm | 2.0k ohm | 20k ohm | 200k ohm | 2.0M ohm
2.2 ohm | 22 ohm | 220 ohm | 2.2k ohm | 22k ohm | 220k ohm | 2.2M ohm
2.4 ohm | 24 ohm | 240 ohm | 2.4k ohm | 24k ohm | 240k ohm | 2.4M ohm
2.7 ohm | 27 ohm | 270 ohm | 2.7k ohm | 27k ohm | 270k ohm | 2.7M ohm
3.0 ohm | 30 ohm | 300 ohm | 3.0K ohm | 30K ohm | 300K ohm | 3.0M ohm
3.3 ohm | 33 ohm | 330 ohm | 3.3k ohm | 33k ohm | 330k ohm | 3.3M ohm
3.6 ohm | 36 ohm | 360 ohm | 3.6k ohm | 36k ohm | 360k ohm | 3.6M ohm
3.9 ohm | 39 ohm | 390 ohm | 3.9k ohm | 39k ohm | 390k ohm | 3.9M ohm
4.3 ohm | 43 ohm | 430 ohm | 4.3k ohm | 43K ohm | 430K ohm | 4.3M ohm
4.7 ohm | 47 ohm | 470 ohm | 4.7k ohm | 47k ohm | 470k ohm | 4.7M ohm
5.1 ohm | 51 ohm | 510 ohm | 5.1k ohm | 51k ohm | 510k ohm | 5.1M ohm
5.6 ohm | 56 ohm | 560 ohm | 5.6k ohm | 56k ohm | 560k ohm | 5.6M ohm
6.2 ohm | 62 ohm | 620 ohm | 6.2k ohm | 62K ohm | 620K ohm | 6.2M ohm
6.8 ohm | 68 ohm | 680 ohm | 6.8k ohm | 68k ohm | 680k ohm | 6.8M ohm
7.5 ohm | 75 ohm | 750 ohm | 7.5k ohm | 75k ohm | 750k ohm | 7.5M ohm
8.2 ohm | 82 ohm | 820 ohm | 8.2k ohm | 82k ohm | 820k ohm | 8.2M ohm
9.1 ohm | 91 ohm | 910 ohm | 9.1k ohm | 91k ohm | 910k ohm | 9.1M ohm
#generics #CommonPartsLibrary" | ""
"R3 | R33" | "RC0603JR-070RL" | "2" | "N" | "A generic fixed resistor ideal for rapid circuit topology development. Its footprint automatically adapts based on the selected package case code—supporting 0402 | 0603 | 0805 | 1203 | and many other standard SMD packages | as well as axial horizontal and vertical configurations.
Save precious design time by seamlessly add more information to this part (value | footprint | etc.) as it becomes available.
Standard resistor values:
1.0 ohm | 10 ohm | 100 ohm | 1.0k ohm | 10k ohm | 100k ohm | 1.0M ohm
1.1 ohm | 11 ohm | 110 ohm | 1.1k ohm | 11k ohm | 110k ohm | 1.1M ohm
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

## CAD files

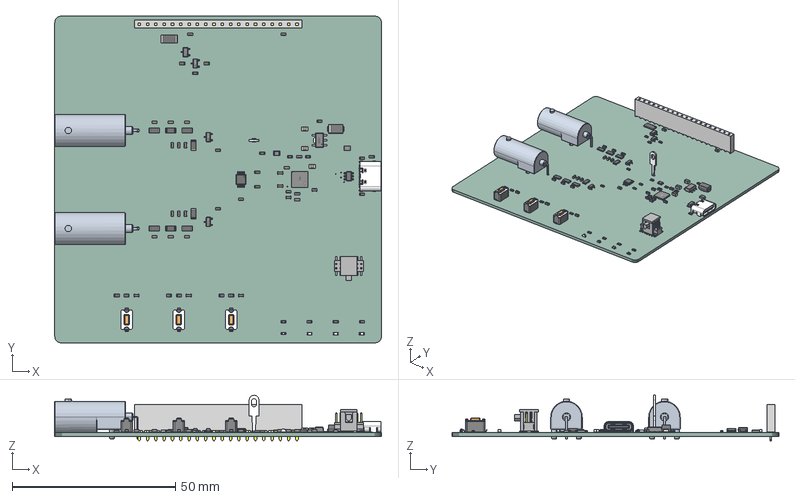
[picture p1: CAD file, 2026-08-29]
docs/oscilloscope.step
100.1 x 100.0 x 13.9 mm
C_0603_1608Metric x 27
150060YS75000 x 2
R_1206_3216Metric x 8
R_0603_1608Metric x 24
R0805_L2.0-W1.3-H0.6
HSMA-C120
FTSH-107-01-L-DV-K-P-TR_pp_pad
FTSH-107-01-L-DV-K-P-TR_pins2
FTSH-107-01-L-DV-K-P-TR_pins1
FTSH-107-01-L-DV-K-P-TR_body
SOT-23-3P_L2.9-W1.3-H1.0-LS2.4-P0.95 x 3
Frame x 3
Cover x 3
pins x 6
C_0805_2012Metric x 3
LED0603-RD
BODY_MUA08A
LEAD_MUA08A x 8
SOT_23_6
UFQFPN-32_L5.0-W5.0-H0.6-P0.50
CONN-TH_L3.0-W1.2
D_SMA
R_2010_5025Metric
F0805_L2.1-W1.4-H0.8
T1SSW-120-01-T-S
P2SSW-120-01-T-S
SOT-89-5_L4.5-W2.5-H1.5-LS4.1-P1.50
HSG_ASM_1
SOT-23-3L_L2.9-W1.6-H1.1-LS2.8-P0.95
input_PCB

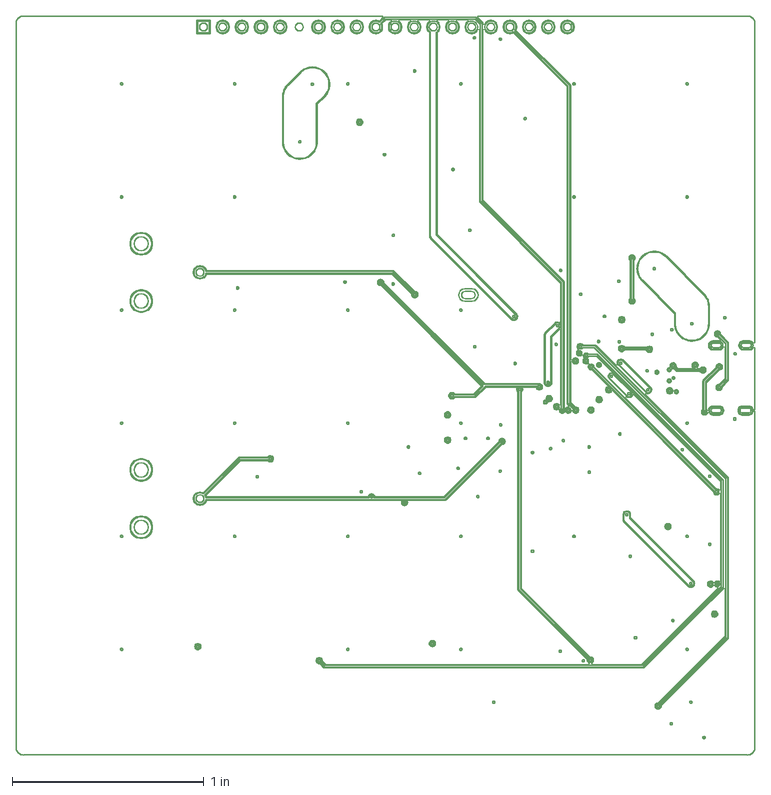
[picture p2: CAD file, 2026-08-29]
manufacturing/oscilloscope-dxf/oscilloscope-In1_Cu.dxf
3.86 x 3.86 in

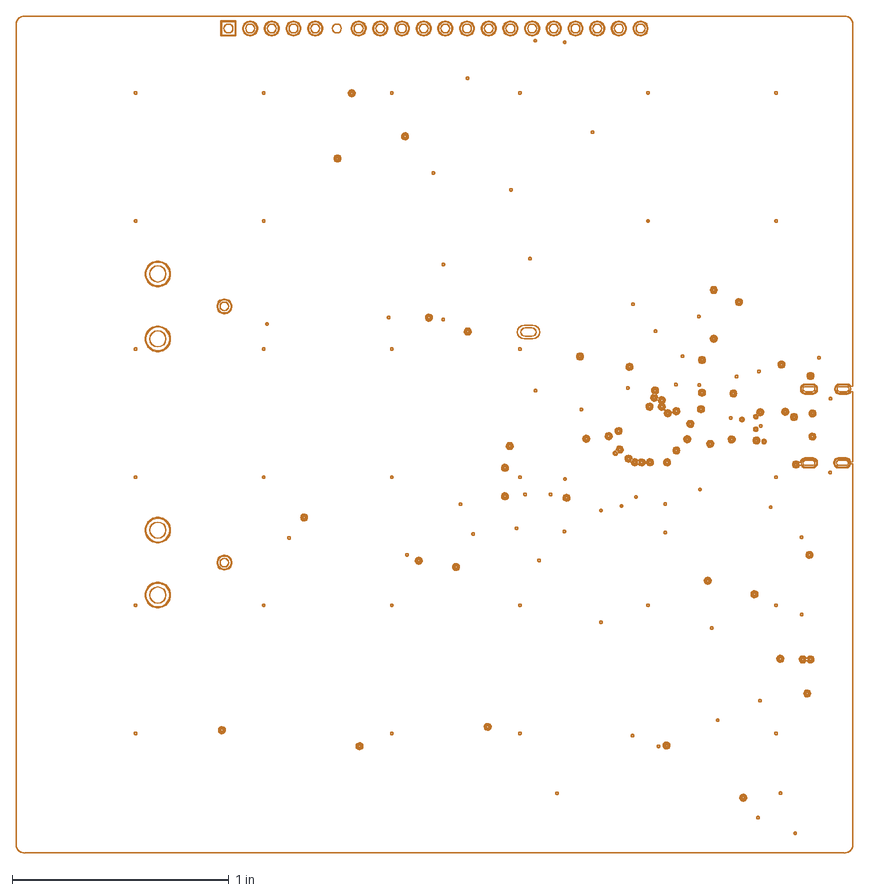
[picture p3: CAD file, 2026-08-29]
manufacturing/oscilloscope-dxf/oscilloscope-In2_Cu.dxf
3.86 x 3.86 in

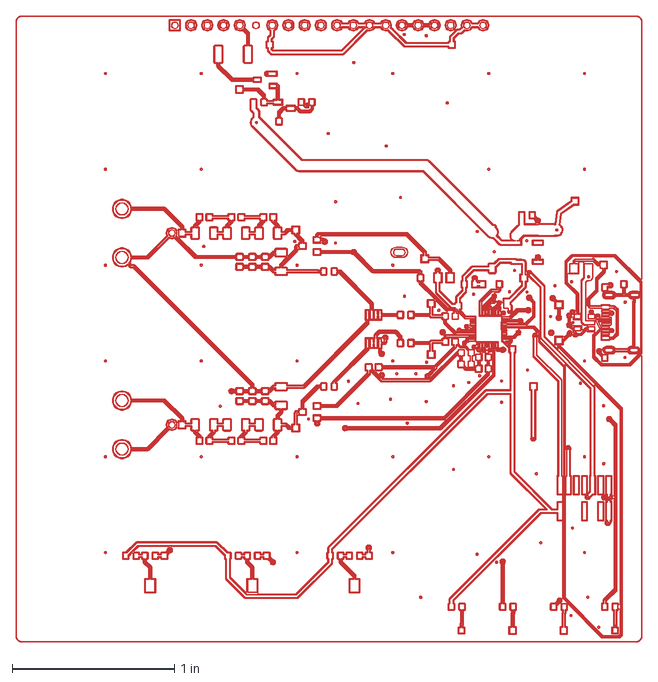
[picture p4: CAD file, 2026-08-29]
manufacturing/oscilloscope-dxf/oscilloscope-F_Cu.dxf
3.86 x 3.86 in

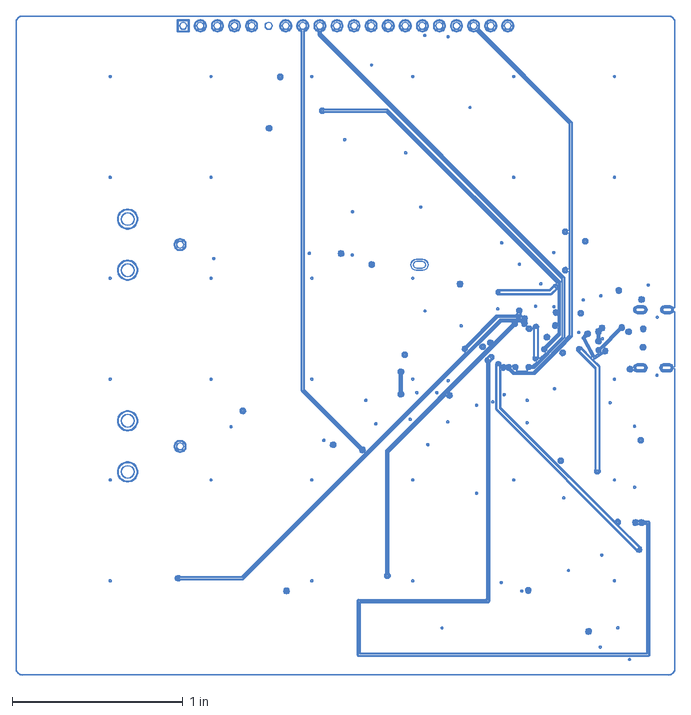
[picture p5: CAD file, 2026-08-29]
manufacturing/oscilloscope-dxf/oscilloscope-B_Cu.dxf
3.86 x 3.86 in

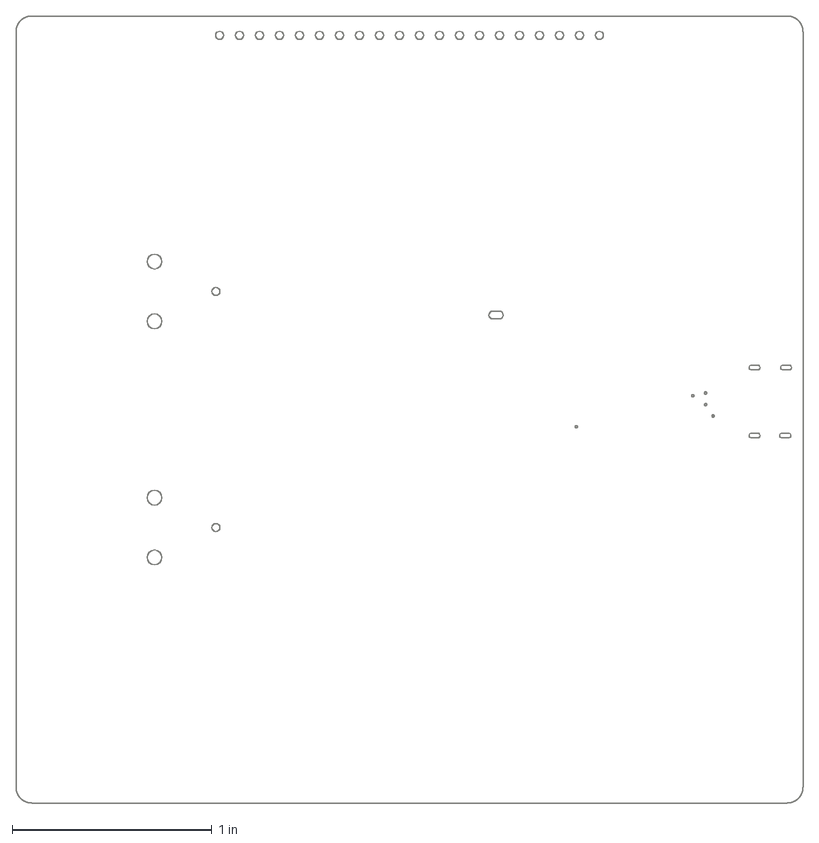
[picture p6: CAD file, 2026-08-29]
manufacturing/oscilloscope-dxf/oscilloscope-Edge_Cuts.dxf
3.94 x 3.94 in

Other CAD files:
manufacturing/oscilloscope-dxf/oscilloscope-B_Mask.dxf
manufacturing/oscilloscope-dxf/oscilloscope-B_Paste.dxf
manufacturing/oscilloscope-dxf/oscilloscope-B_Silkscreen.dxf
manufacturing/oscilloscope-dxf/oscilloscope-F_Mask.dxf
manufacturing/oscilloscope-dxf/oscilloscope-F_Paste.dxf
manufacturing/oscilloscope-dxf/oscilloscope-F_Silkscreen.dxf

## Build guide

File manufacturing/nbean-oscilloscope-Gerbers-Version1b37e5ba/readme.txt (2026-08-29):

Project Name: Oscilloscope
Project Version: #1b37e5ba
Project Url: https://www.flux.ai/nbean/oscilloscope~47

Project Description:
Welcome to your new project. Imagine what you can build here.

Index:

Bottom Copper (Gerber): oscilloscope-b_cu.gbr
Bottom Solder Mask (Gerber): oscilloscope-b_mask.gbr
Bottom Solder Paste (Gerber): oscilloscope-b_paste.gbr
Bottom Silkscreen (Gerber): oscilloscope-b_silks.gbr
Board Outline (Gerber): oscilloscope-edge_cuts.gbr
Top Copper (Gerber): oscilloscope-f_cu.gbr
Top Solder Mask (Gerber): oscilloscope-f_mask.gbr
Top Solder Paste (Gerber): oscilloscope-f_paste.gbr
Top Silkscreen (Gerber): oscilloscope-f_silks.gbr
Mid-Layer 1 (Gerber): oscilloscope-in1_cu.gbr
Mid-Layer 2 (Gerber): oscilloscope-in2_cu.gbr
Drill Holes (Excellon): oscilloscope.drl
Electrical Test Netlist (IPC-D-356): oscilloscope.d356
Component Positions, for assembly (Pick and Place, CSV): pick_and_place.csv

Bill of Materials: multiple versions are provided optimized for various contract manufacturers:

Bill of Materials (AdvancedCircuits): BOM/nbean-oscilloscope-BOM-V1b37e5ba-AdvancedCircuits.csv
Bill of Materials (AllPCB): BOM/nbean-oscilloscope-BOM-V1b37e5ba-AllPCB.csv
Bill of Materials (Elecrow): BOM/nbean-oscilloscope-BOM-V1b37e5ba-Elecrow.csv
Bill of Materials (Eurocircuits): BOM/nbean-oscilloscope-BOM-V1b37e5ba-Eurocircuits.csv
Bill of Materials (Flux): BOM/nbean-oscilloscope-BOM-V1b37e5ba-Flux.csv
Bill of Materials (JLCPCB): BOM/nbean-oscilloscope-BOM-V1b37e5ba-JLCPCB.csv
Bill of Materials (PCBWay): BOM/nbean-oscilloscope-BOM-V1b37e5ba-PCBWay.csv
Bill of Materials (Seeed): BOM/nbean-oscilloscope-BOM-V1b37e5ba-Seeed.csv

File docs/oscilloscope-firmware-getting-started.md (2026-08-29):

# Firmware Getting Started

## Live MCU pin map (STM32L432KCU6 U1)

| STM32L432 pin | Function | Schematic net |
|---|---|---|
| PA0 / ADC1_IN5 | CH1 ADC, sequence rank 1 | CH1_ADC |
| PA1 / ADC1_IN6 | CH2 ADC, sequence rank 2 | CH2_ADC |
| PA2 / USART2_TX | Target TX to probe RX | VCP_TARGET_TX_TO_PROBE_RX |
| PA3 / USART2_RX | Probe TX to target RX | VCP_PROBE_TX_TO_TARGET_RX |
| PA4 / SPI1_NSS | LCD chip select | LCD_CS |
| PA5 / SPI1_SCK | LCD serial clock | LCD_SCK |
| PA7 / SPI1_MOSI | LCD serial data; module DB3–DB1 tied | LCD_MOSI |
| PA8 / TIM1_CH1 | Backlight PWM, active high | LCD_BL_PWM |
| PA11 / USB_DM | Native USB FS D− | USB_DM |
| PA12 / USB_DP | Native USB FS D+ | USB_DP |
| PA13 | SWDIO | SWDIO |
| PA14 | SWCLK | SWCLK |
| PA15 | USB/activity LED | LED_USB_DRV |
| PB0 | LCD A0/RS data-command | LCD_DC |
| PB1 | LCD reset | LCD_RST |
| PB3 | RUN/STOP button, active low | BTN_RUN_STOP |
| PB4 | MODE button, active low | BTN_MODE |
| PB5 | SELECT button, active low | BTN_SELECT |
| PB6 | RUN LED | LED_RUN_DRV |
| PB7 | TRIGGER/ARM LED | LED_TRIGGER_DRV |

PA6, PA9, PA10, PC14 and PC15 are intentionally unused. PH3/BOOT0 is strapped low through R6.

## Required peripheral setup

- System clock: HSI-based plan; verify the final clock tree and USB clock in STM32CubeMX.
- ADC1: proposed asynchronous clock target 80 MHz; regular sequence IN5 rank 1 then IN6 rank 2; 12.5-cycle sample time; timer-triggered DMA circular operation; target 3.2 Msps aggregate. Timing remains unmeasured.
- USB device: PA11/PA12 native USB FS.
- SPI1 transmit-only: PA5 SCK, PA7 MOSI; GPIO controls PA4 CS, PB0 A0/RS, PB1 reset.
- TIM1_CH1: PA8 PWM. Logic high commands backlight ON.
- USART2: PA2 TX and PA3 RX, with the direction-explicit STDC14 crossover nets.
- Buttons: GPIO inputs with active-low interpretation; external 10 kΩ pull-ups and 100 Ω/100 nF filters are fitted.
- LEDs: PB6, PB7 and PA15 are active-high outputs; the power LED is rail-driven.

## Startup order

1. Configure power/flash latency and HSI clock tree.
2. Initialize GPIO default states: LCD CS high, LCD reset high after reset pulse, PA8 low, status LEDs off.
3. Start USB device and USART2 VCP test path.
4. Initialize SPI1 and the ERM19296-1 in 4-wire serial mode.
5. Calibrate and configure ADC1, timer trigger and circular DMA.
6. Enable button processing and acquisition state machine.

## STM32 HAL implementation skeleton

Generate the clock, GPIO, ADC1, DMA, TIM trigger, SPI1, USART2, and USB-device setup with STM32CubeMX for the **STM32L432KCU6** package, then keep application code within generated user sections. The following calls are real STM32 HAL APIs; they are an implementation example, not tested project firmware:

```c
static void Scope_StartAcquisition(void)
{
    HAL_ADCEx_Calibration_Start(&hadc1, ADC_SINGLE_ENDED);
    HAL_TIM_Base_Start(&htim6); /* Use the timer selected as ADC external trigger. */
    HAL_ADC_Start_DMA(&hadc1, (uint32_t *)adc_interleaved,
                      ADC_INTERLEAVED_SAMPLE_COUNT);
}

static void Backlight_Set(uint16_t compare)
{
    __HAL_TIM_SET_COMPARE(&htim1, TIM_CHANNEL_1, compare);
}

static void Lcd_Write(const uint8_t *data, uint16_t length)
{
    HAL_GPIO_WritePin(LCD_CS_GPIO_Port, LCD_CS_Pin, GPIO_PIN_RESET);
    HAL_SPI_Transmit(&hspi1, (uint8_t *)data, length, HAL_MAX_DELAY);
    HAL_GPIO_WritePin(LCD_CS_GPIO_Port, LCD_CS_Pin, GPIO_PIN_SET);
}

static void ProbeUart_Send(const uint8_t *data, uint16_t length)
{
    HAL_UART_Transmit(&huart2, (uint8_t *)data, length, HAL_MAX_DELAY);
}
```

ADC channel configuration must explicitly use `ADC_CHANNEL_5` as rank 1 and `ADC_CHANNEL_6` as rank 2, both with `ADC_SAMPLETIME_12CYCLES_5`, and an external timer trigger selected in CubeMX/HAL. Verify generated register settings and actual sample timing before relying on the target rate.

Toolchain: STM32CubeIDE with the STM32CubeL4 HAL package. Build and flash with the generated CubeIDE project or equivalent `arm-none-eabi-gcc` flow; no repository-specific build command is documented or claimed tested here.

## Bring-up notes

- Confirm ADC rank order by register readback before interpreting interleaved samples.
- Keep the backlight off before USB configuration.
- Bandwidth, divider compensation, 15 V overload survival, backlight operating point, USB ESD/hot-plug, ADC timing, thermals, and HSI accuracy are prototype verification gates, not firmware-assumed verified performance.

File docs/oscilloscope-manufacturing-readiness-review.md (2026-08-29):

# Manufacturing Readiness Review

**Review date:** 2026-08-28  
**Scope:** Pre-export validation for bare-board fabrication and SMT assembly. No manufacturing files were exported during this review.

## Release Decision

| Package | Status | Decision |
|---|---|---|
| Bare PCB fabrication | **Conditionally ready** | Mandatory connectivity/fabrication gates pass. Resolve or formally waive the two protected dangling-copper warnings before release. |
| SMT assembly | **Blocked pending BOM cleanup** | Fourteen fabricated PCB test pads are currently included as BOM elements and should be excluded from BOM and pick-and-place outputs. |

## Mandatory Fabrication Gates

| Gate | Result | Evidence |
|---|---|---|
| Airwires | **PASS** | 0 remaining airwires. |
| DRC errors | **PASS** | 0 current DRC errors. Two protected dangling-trace warnings remain and are tracked separately. |
| Overlapping copper / shorts | **PASS** | 0 open overlapping-copper or overlapping-trace errors. |
| Missing footprints | **PASS** | 101 schematic components are placed; no missing-footprint error. |
| Invalid layers | **PASS** | No invalid-layer error. |
| Board outline | **PASS** | Closed 100 mm × 100 mm rectangular outline with 2 mm corner radius. |
| Stackup definition | **PASS WITH FAB CONFIRMATION** | Four copper layers; nominal finished thickness 1.30 mm. Custom construction must be approved by the selected fabricator. |
| Components outside board | **PASS / MECHANICAL REVIEW REQUIRED** | No open component-outside-board DRC. J1, J2, and J3 intentionally overhang the board edge; confirm panelization and enclosure clearances. |
| Production MPN coverage | **PASS WITH EXCLUSIONS** | Active components and fitted passives have MPNs. DNI capacitors are marked excluded. |

## Fabrication and Assembly Blockers

### 1. Fabricated test pads are included in the assembly BOM

**Severity:** Assembly-package blocker  
**Affected:** TP_3V3, TP_CH1_DIV, TP_USB_DM, TP_CH1_IN, TP_VBUS_RAW, TP_BL_K, TP_USB_DP, TP_CH2_DIV, TP_NRST, TP_VDDA, TP_CH1_ADC, TP_CH2_ADC, TP_CH2_IN, TP_VBUS_PROT.

These are 1.0 mm × 1.0 mm PCB copper features but currently appear as a BOM line with MPN `PCB-TESTPAD-1.0X1.0`. Mark all fourteen **Exclude from BOM = true** and **Exclude from Pick & Place = true** before producing assembly files. TP_GND is a real Keystone 4952 component and should remain in the BOM.

### 2. Two protected dangling-copper groups remain

**Severity:** Fabrication release warning; waiver or cleanup required  
**DRC groups:** `Trace a4ae` and `Trace b74f`.

The board has zero airwires and no copper-short errors, so these warnings do not represent missing electrical connectivity. They are locked legacy protected copper. Remove them if the editor permits, or visually verify in the Gerber viewer that they do not create exposed stubs, unintended antennas, mask slivers, or copper near the board edge. Record an explicit waiver if retained.

## Required Fabricator Confirmations

1. **Stackup:** Approve the custom four-layer, 1.30 mm nominal construction rather than silently substituting a standard 1.6 mm stackup.
2. **USB impedance:** Request 90 Ω differential USB 2.0 routing (45 Ω single-ended target per leg) using the released stackup. The configured target is a design target, not measured or certified impedance.
   - The final USB_DP repair is a bottom-layer bypass with explicit top/bottom transition vias; inspect both transitions and reference-plane continuity in Gerbers.
3. **Minimum geometry:** Confirm support for 0.15 mm USB traces, 0.15 mm USB clearance rule, and 0.30 mm finished via drills with 0.60 mm pads.
4. **Edge connectors:** Confirm J1 USB-C and J2/J3 BNC overhangs are acceptable for panel rails, routing tabs, and assembly fixtures.
5. **Surface finish:** Select a finish compatible with the USB-C fine-pitch contacts and exposed test pads; ENIG is preferred for flatness and probe durability.

## BOM and Assembly Notes

- 101 placed components; all are on the top side.
- DNI capacitors C16, C17, C23, and C24 are the live exclusion set; verify all four are omitted from generated BOM and pick-and-place outputs.
- Several active parts are extended-class items for JLCPCB-style assembly; verify stock and substitution policy before ordering.
- Confirm polarity/orientation for LEDs, D1/D2/D3/D4, Q1/Q2, and connector pin-1 conventions in the pick-and-place preview.

## Pre-Order Checklist

- [ ] Exclude the fourteen fabricated test pads from BOM and pick-and-place.
- [ ] Verify C16/C17/C23/C24 are excluded from the generated assembly outputs.
- [ ] Remove or waive `Trace a4ae` and `Trace b74f` after Gerber inspection.
- [ ] Confirm the 1.30 mm four-layer stackup with the fabricator.
- [ ] Confirm controlled-impedance service and USB geometry.
- [ ] Inspect all Gerber layers, solder-mask openings, drill files, and the closed outline in an independent viewer.
- [ ] Verify J1/J2/J3 edge geometry against panelization and enclosure constraints.
- [ ] Review BOM quantities and pick-and-place rotations before release.

## Conclusion

There are **zero airwires and zero DRC errors**, with no hard bare-board connectivity or copper-short blockers. SMT assembly export is blocked until the fourteen fabricated test-pad entries are excluded. The two protected dangling-copper warnings, USB transition-via review, and the custom stackup require explicit review before the manufacturing package is released.

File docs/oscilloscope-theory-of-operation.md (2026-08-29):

# Theory of Operation

## Design and claim boundary

This file describes the live **101-component, 57-net STM32L432KCU6 internal-ADC MVP** as of 2026-08-28. Implemented circuitry, configured targets, and modeled results must not be described as measured, tested, certified, or production-proven without evidence.

## Analog signal paths

Each channel is DC-coupled and unipolar:

`BNC → 3 × 300 kΩ high arm → CHx_CLAMP with 200 kΩ low arm and compensation → BAV199LT1G rail clamp → 10 kΩ → TLV9062IDGKR unity buffer → 47 Ω / 1 nF ADC network → STM32 ADC`

- CH1 terminates at PA0 / ADC1_IN5.
- CH2 terminates at PA1 / ADC1_IN6.
- R12 and R18 are **47 Ω Yageo RC0603FR-0747RL**.
- D3/D4 BAV199 mapping is pin 1 to AGND, pin 3 to CHx_CLAMP, and pin 2 to VDDA.
- Nominal low-frequency input impedance is 1.10 MΩ and nominal divider ratio is 5.5:1.

The normal measurement range is 0–12 V DC. Fifteen volts is an **unmeasured overload-survival target**, not a normal rating or safety certification. Inputs are ground referenced and non-isolated; negative, mains, CAT, floating, and high-energy measurements are prohibited.

## Acquisition architecture

The proposed firmware configuration uses ADC1 rank 1 = IN5/CH1 and rank 2 = IN6/CH2, an 80 MHz asynchronous ADC clock target, 12.5-cycle sample time, timer-triggered DMA, and 3.2 Msps aggregate target. Calculated target values are 312.5 ns rank spacing and 1.6 Msps/channel. ADC timing, settling, crosstalk, and rate remain unmeasured.

The implemented 47 Ω/1 nF network passed a bounded acquisition model at 0.558 LSB worst-case external error. That is a simulation result, not a hardware measurement.

## LCD, controls, and backlight

J4 is the SSW-120-01-T-S 1×20 interface for the exact ERM19296-1 4-wire SPI pin-header option. U1 uses PA4 for LCD_CS, PA5 for LCD_SCK, PA7 for LCD_MOSI, PB0 for LCD_DC, and PB1 for LCD_RST.

The backlight is switched from VBUS_PROT by fitted **NCE3401 Q1** with 2N7002KT1G Q2 as the gate pull-down. PA8/TIM1_CH1 drives the control path; PWM high commands backlight ON. R19 is a provisional 27 Ω Yageo RC2010FK-0727RL. LCD pin 6 remains continuously grounded. Backlight current and thermal performance remain unmeasured.

Buttons are active-low on PB3/PB4/PB5. Status LED drive nets use PB6, PB7, and PA15. USART2 uses PA2 TX on `VCP_TARGET_TX_TO_PROBE_RX` and PA3 RX on `VCP_PROBE_TX_TO_TARGET_RX`.

## USB and power

USB FS uses PA11/USB_DM and PA12/USB_DP through USBLC6-2SC6. The final USB_DP repair uses a bottom-layer bypass with explicit top/bottom transition vias. The configured routing target is **45 Ω single-ended / 90 Ω differential**; this is a fabrication target, not measured or certified impedance.

USB VBUS passes through MF-PSMF035X-2 protection to VBUS_PROT. AP7361C-33Y5-13 generates 3.3 V; FB1 filters VDDA. LDO input current is **output current plus quiescent current**. Direct-VBUS loads such as the backlight and protection leakage are added separately. Bounded totals including 80 µA LDO IQ and 20 µA TVS leakage are 125.10 mA typical, 145.10 mA design, and 175.10 mA validation case.

## PCB implementation state

The PCB is 100 × 100 mm with four copper layers and a nominal 1.30 mm custom stackup. All 101 components are top-side. Routing is complete with zero airwires and zero DRC errors.

Two locked legacy protected dangling-trace warnings remain: `Trace a4ae` and `Trace b74f`. They require Gerber review and cleanup or an explicit waiver.

Fourteen fabricated 1.0 × 1.0 mm test pads are currently BOM elements and must be excluded from BOM and pick-and-place before SMT assembly export. TP_GND is a real Keystone 4952 component and remains included. The live DNI exclusion set is C16, C17, C23, and C24.

## Unmeasured prototype gates

Bandwidth, divider compensation, 15 V overload survival, backlight operating point, USB ESD/hot-plug behavior, ADC timing, thermals, and HSI accuracy remain open prototype validation gates.

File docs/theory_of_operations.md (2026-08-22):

# Theory of Operation

## Revision boundary

Rev 0.1A is the existing reviewed design. Rev 0.2 is **approved for schematic capture but not yet implemented or tested**. Detailed controls are in [MVP Design Decisions](https://www.flux.ai/nbean/oscilloscope/files/mvp-design-decisions).

## Rev 0.2 signal path

Each channel is a DC-coupled unipolar path: **1.10 MΩ low-frequency nominal, compensated 5.5:1 divider → CHx_CLAMP → BAV199LT1G rail clamp → 10 kΩ → TLV9062IDR unity buffer → 330 Ω/1 nF ADC filter → MCU ADC input**.

- CH1 terminates at **PA0 / ADC1_IN5**.
- CH2 terminates at **PA1 / ADC1_IN6**.
- ADC regular sequence is CH1 rank 1 followed by CH2 rank 2.

For each BAV199LT1G, pin 1 goes to AGND, pin 3 goes to CHx_CLAMP, and pin 2 goes to VDDA. This uses the lower diode from AGND to CHx_CLAMP and the upper diode from CHx_CLAMP to VDDA.

Normal rated measurement is **0–12 V DC**. The 15 V figure is only an **unverified overload-survival design target**, not a normal rating, bench result, or safety certification.

## Acquisition timing

The configuration target is an **80 MHz asynchronous ADC clock**, timer-triggered **3.2 Msps aggregate**, and **12.5-cycle sampling + 12.5-cycle conversion** per rank. This produces target values of **312.5 ns CH1-to-CH2 skew** and **1.6 Msps/channel** for the alternating sequence. These are firmware/bench confirmation targets, not measured facts.

Triggering remains software-based with selectable channel/edge/level, Auto/Normal/Single modes, and circular pretrigger buffering. HSI timebase accuracy after USB-SOF/factory correction remains a prototype verification gate.

## VCP

The UART crossover is explicit:

- `VCP_TARGET_TX_TO_PROBE_RX`: MCU TX → STDC14 probe RX.
- `VCP_PROBE_TX_TO_TARGET_RX`: STDC14 probe TX → MCU RX.

## LCD and backlight

Procure only the exact **ERM19296-1 “4-Wire SPI Pin Header Connection”** option. It uses a 1×20, 2.54 mm header. Four-wire SPI uses A0/RS, CSB, RSTB, DB3–DB1 tied as MOSI/SDA, and DB0 as SCK/SCL; DB7–DB4, ERD, and RWR are tied high, with IF2:IF1:IF0 = L:L:L.

The backlight is PWM-switched on the high side so LCD pin 6 remains a solid common ground. Protected VBUS feeds the source of an AO3401A P-MOS; its drain feeds the provisional 27 Ω, 0.5 W resistor and then LEDA pin 5. A 100 kΩ source-to-gate pull-up defaults the P-MOS OFF. A 2N7002KT1G pulls the P-MOS gate low; its source is grounded and its MCU-driven gate has 100 Ω series resistance and a 100 kΩ ground pulldown. **MCU PWM high turns the backlight ON.** The AO3401A −30 V VDS, ±12 V VGS and 60 mΩ maximum RDS(on) at −4.5 V are suitable at 5 V and 60–75 mA; the 2N7002KT1G 60 V VDS, ±20 V VGS and ≥230 mA stated continuous-current capability provide ample driver margin. The 27 Ω value remains provisional pending exact module Vf/current measurement and resistor/MOSFET thermal verification at the 60–75 mA acceptance band.

## Power and grounding

LDO input current is approximately LDO output current, while the backlight is a separate direct-VBUS load. Rounded USB totals are therefore 50+75 = **125 mA typical**, 70+75 = **145 mA design**, and 100+75 = **175 mA validation case**.

BNC shells, PCB ground, and USB ground are common. The instrument is non-isolated and limited to ground-referenced, current-limited extra-low-voltage sources.

## Prototype verification gates

Bandwidth/flatness, ADC settling and crosstalk, compensation trim, HSI accuracy, 15 V overload survival, thermal performance, hot-plug behavior, and ESD robustness are prototype verification gates rather than implemented or measured performance claims.

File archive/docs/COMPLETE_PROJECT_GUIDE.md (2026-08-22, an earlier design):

# Complete Digital Oscilloscope Project Guide

**Build a Professional High-Performance Digital Oscilloscope System**

From zero to working oscilloscope with FPGA, custom PCB, and embedded software.

---

## Table of Contents

1. [Project Overview](#project-overview)
2. [Prerequisites](#prerequisites)
3. [Phase 1: FPGA Development](#phase-1-fpga-development)
4. [Phase 2: PCB Design and Manufacturing](#phase-2-pcb-design-and-manufacturing)
5. [Phase 3: Hardware Assembly](#phase-3-hardware-assembly)
6. [Phase 4: Hardware Bring-Up](#phase-4-hardware-bring-up)
7. [Phase 5: Software Development](#phase-5-software-development)
8. [Phase 6: System Integration and Testing](#phase-6-system-integration-and-testing)
9. [Troubleshooting Guide](#troubleshooting-guide)
10. [Performance Optimization](#performance-optimization)

---

## Project Overview

### What You'll Build

A **complete digital oscilloscope system** featuring:
- **100 MHz+ sampling rate** analog-to-digital conversion
- **FPGA-based digital signal processing** with Xilinx Artix-7
- **Custom 4-layer PCB** with high-speed analog front-end
- **MicroBlaze soft processor** running embedded firmware
- **Real-time waveform capture** and display
- **Ethernet connectivity** for data transfer
- **Professional instrument-grade** design

### System Architecture

```
┌─────────────────────────────────────────────────────────┐
│                  Digital Oscilloscope                    │
├─────────────────────────────────────────────────────────┤
│                                                          │
│  Signal Input (BNC/Probe)                               │
│         ↓                                               │
│  Analog Conditioning (Amp/Atten/Filter)                 │
│         ↓                                               │
│  High-Speed ADC (SPI Interface)                         │
│         ↓                                               │
│  FPGA Logic (Artix-7)                                   │
│    ├─ Data Capture State Machine                       │
│    ├─ High-Speed Buffer (BRAM)                         │
│    ├─ Trigger Detection                                │
│    └─ MicroBlaze Processor                             │
│         ↓                                               │
│  External DDR3 Memory                                   │
│         ↓                                               │
│  Processing & Display                                   │
│    ├─ UART Terminal Output                             │
│    ├─ Ethernet Data Export                             │
│    └─ Waveform Analysis                                │
│                                                          │
└─────────────────────────────────────────────────────────┘
```

### Time and Cost Estimate

| Phase | Duration | Cost (USD) |
|---|---|---|
| FPGA Development | 2-4 weeks | $0 (software is free) |
| PCB Design | 1-2 weeks | $0 (KiCad is free) |
| PCB Manufacturing | 1-2 weeks | $50-150 (3 boards) |
| Component Procurement | 1-2 weeks | $100-200 |
| Assembly | 1 week | $0-50 (tools if needed) |
| Bring-Up & Testing | 1-2 weeks | $0 |
| Software Development | 2-4 weeks | $0 |
| **Total** | **2-4 months** | **$150-400** |

### Required Hardware

**Essential:**
- Xilinx Arty A7-100 FPGA board (~$200-250)
- USB cable for programming
- 5V power supply (usually included)
- Computer (Windows/Linux/Mac)

**For Complete System:**
- Custom PCB (designed, ordered, assembled)
- Electronic components (see BOM)
- Soldering equipment
- Basic test equipment (multimeter, power supply)

---

## Prerequisites

### Knowledge Requirements

**Essential Skills:**
- ✅ Basic electronics (Ohm's law, voltage/current)
- ✅ Programming in C (moderate level)
- ✅ Command-line comfort (file navigation, running commands)
- ✅ Patience and problem-solving attitude

**Helpful But Not Required:**
- HDL experience (VHDL or Verilog/SystemVerilog)
- PCB design experience
- Soldering experience
- FPGA development background
- Embedded systems knowledge

### Software Installation

#### 1. Xilinx Vivado Design Suite

**Version:** 2019.2 or later (2020.1 recommended for this project)

**Download:**
1. Go to [Xilinx Downloads](https://www.xilinx.com/support/download.html)
2. Create free account (required)
3. Download **Vivado ML Edition - WebPACK** (free version)
4. Size: ~35 GB download, 100 GB installed

**Installation (Linux):**
```bash
# Extract installer
tar -xvf Xilinx_Unified_2020.1_*.tar.gz
cd Xilinx_Unified_2020.1_*/

# Run installer
sudo ./xsetup

# Follow GUI installer:
# - Select "Vivado"
# - Edition: "Vivado ML Standard" or "WebPACK"
# - Include: Artix-7 device support
# - Install to: /tools/Xilinx (or your preference)
```

**Installation (Windows):**
1. Run installer executable
2. Follow on-screen instructions
3. Select WebPACK edition
4. Include Artix-7 devices
5. Takes 2-4 hours to install

**Post-Installation:**
```bash
# Add to PATH (Linux)
echo 'source /tools/Xilinx/Vivado/2020.1/settings64.sh' >> ~/.bashrc
source ~/.bashrc

# Verify installation
vivado -version
```

#### 2. Xilinx Vitis (for embedded software)

**Included with Vivado 2019.2+**

If separate installation needed:
```bash
# Usually at same location as Vivado
source /tools/Xilinx/Vitis/2020.1/settings64.sh
```

#### 3. KiCad EDA (for PCB design)

**Version:** 5.x or 6.x

**Installation (Linux):**
```bash
# Ubuntu/Debian
sudo add-apt-repository ppa:kicad/kicad-6.0-releases
sudo apt update
sudo apt install kicad

# Arch Linux
sudo pacman -S kicad kicad-library kicad-library-3d
```

**Installation (Windows/Mac):**
1. Download from [kicad.org](https://www.kicad.org/download/)
2. Run installer
3. Include all libraries (symbols, footprints, 3D models)

#### 4. Serial Terminal Software

**Linux:**
```bash
sudo apt install minicom
# Or
sudo apt install screen
```

**Windows:**
- PuTTY: https://www.putty.org/
- Tera Term: https://ttssh2.osdn.jp/

**Mac:**
```bash
brew install minicom
```

#### 5. Git (Version Control)

```bash
# Linux
sudo apt install git

# Windows
# Download from git-scm.com

# Mac
brew install git
```

---

## Phase 1: FPGA Development

**Goal:** Create and program the FPGA bitstream  
**Duration:** 2-4 weeks (first-time), 3-5 days (experienced)  
**Prerequisites:** Vivado installed, Arty board available

### Step 1.1: Open Existing Project

```bash
# Navigate to project
cd /path/to/oscilloscope_project/oscilloscope-fpga

# Launch Vivado
vivado oscilloscope-fpga.xpr &
```

**First Time Opening:**
- Vivado will auto-upgrade project if needed
- May take 5-10 minutes to index
- All IP cores will be validated

### Step 1.2: Understand Project Structure

**In Vivado GUI:**

1. **Sources Panel** (left side)
   - Design Sources
     - `design_1` (block design)
     - `adc_interface` (custom ADC interface)
     - `design_1_wrapper` (top-level)
   - Constraints
     - `arty.xdc` (pin assignments)

2. **Block Design** (double-click `design_1.bd`)
   - MicroBlaze processor
   - DDR3 memory controller
   - AXI interconnect
   - Peripherals (GPIO, UART, SPI, Ethernet, Timer)
   - Custom `adc_interface` module

### Step 1.3: Review and Customize Design

#### Customize ADC Interface (Optional)

**File:** `sources_1/new/adc_interface.vhd`

```vhdl
-- Current: 1kHz calibration clock
-- Modify CLK_1KHZ_PERIOD to change frequency
constant clk_1khz_period : integer := 10 * 1000;  -- Divide by 10,000

-- For 10kHz: change to 1000
-- For 100Hz: change to 100,000
```

#### Modify Block Design (If Needed)

**Add Custom Logic:**
1. Open block design (`design_1.bd`)
2. Right-click canvas → **Add Module**
3. Select your custom module
4. Connect to AXI bus or GPIO
5. **Validate Design** (F6)
6. **Save** (Ctrl+S)

**Add IP Cores:**
1. Click **+** icon or IP Integrator → **Add IP**
2. Search for IP (e.g., "FIFO", "DMA", "Timer")
3. Double-click to add
4. Configure parameters
5. Connect ports

### Step 1.4: Synthesize Design

**Method 1: GUI**
1. Flow Navigator → **Synthesis → Run Synthesis**
2. Wait 10-15 minutes
3. Review results

**Method 2: TCL Console**
```tcl
# In Vivado TCL console
reset_run synth_1
launch_runs synth_1 -jobs 4
wait_on_run synth_1

# Check status
get_property STATUS [get_runs synth_1]
# Should return: "synth_design Complete!"
```

**Check for Errors:**
- Messages tab → Filter "Error"
- Should be 0 errors
- Warnings are often OK, but review critical ones

### Step 1.5: Implement Design

```tcl
# In Vivado TCL console
launch_runs impl_1 -jobs 4
wait_on_run impl_1

# Or use GUI: Flow Navigator → Implementation → Run Implementation
```

**Duration:** 15-25 minutes

**Check Results:**
```tcl
# Timing summary
open_run impl_1
report_timing_summary -file timing_summary.rpt

# Utilization
report_utilization -file utilization.rpt -hierarchical

# Power
report_power -file power.rpt
```

### Step 1.6: Generate Bitstream

```tcl
# TCL command
launch_runs impl_1 -to_step write_bitstream
wait_on_run impl_1

# Or GUI: Flow Navigator → Generate Bitstream
```

**Output:** `oscilloscope-fpga.runs/impl_1/design_1_wrapper.bit`

### Step 1.7: Program FPGA

**Connect Hardware:**
1. Connect Arty A7-100 via USB (JTAG port)
2. Power on board (LED should light)
3. Wait for enumeration (10 seconds)

**Program via Vivado:**
```tcl
# Open Hardware Manager
open_hw_manager
connect_hw_server
open_hw_target

# Program device
set_property PROGRAM.FILE {./oscilloscope-fpga.runs/impl_1/design_1_wrapper.bit} [get_hw_devices xc7a100t_0]
program_hw_devices [get_hw_devices xc7a100t_0]

# Or use GUI: Flow Navigator → Program and Debug → Open Hardware Manager
```

**Verify Programming:**
- DONE LED lights up (green)
- User LEDs may show activity
- Board is now running FPGA design

### Step 1.8: Export Hardware for Software

**This creates the hardware description for Vitis:**

```tcl
# In Vivado
write_hw_platform -fixed -include_bit -force -file design_1_wrapper.xsa

# Or GUI:
# File → Export → Export Hardware
# - Include bitstream: YES
# - Output: design_1_wrapper.xsa
```

**Save to:** `oscilloscope-fpga/design_1_wrapper.xsa`

---

## Phase 2: PCB Design and Manufacturing

**Goal:** Design, order, and receive custom PCB  
**Duration:** 3-5 weeks total (1 week design, 2-3 weeks manufacturing)  
**Cost:** $50-150 for 3 boards

### Step 2.1: Review Existing Design

**Open KiCad Project:**
```bash
cd /path/to/oscilloscope_project/oscilloscope-circuit
kicad Oscilloscope.pro
```

**Add Required Libraries (IMPORTANT):**

1. **Symbol Libraries:**
   - KiCad → Preferences → Manage Symbol Libraries
   - Add: `Schematic Symbols.lib` (in project folder)
   - Scope: "Project" (not global)

2. **Footprint Libraries:**
   - KiCad → Preferences → Manage Footprint Libraries
   - Add: `Footprints.pretty/` directory
   - Scope: "Project"

### Step 2.2: Understand Schematic

**Hierarchical Design:**

- **Oscilloscope.sch** - Top sheet (interconnections)
  - **ADC.sch** - ADC interface (SPI, power)
  - **Analog Inputs.sch** - Input conditioning, protection
  - **Calibration.sch** - Calibration DAC and reference
  - **PMOD Ports.sch** - FPGA interface connectors
  - **Power Supply.sch** - Regulators (3.3V, 5V, analog)
  - **SPI.sch** - SPI communication bus

**Key Components:**
- High-speed ADC (likely AD9226 or similar)
- Operational amplifiers for signal conditioning
- Voltage regulators
- PMOD connectors (interface to FPGA)
- Protection diodes

### Step 2.3: Modify Design (Optional)

**Common Modifications:**

**Change Input Range:**
1. Open `Analog Inputs.sch`
2. Modify resistor divider values
3. Update op-amp gain
4. Update annotations

**Add Features:**
- Additional input channels
- Different ADC
- Trigger circuit improvements
- Power supply changes

**Always:**
- Run **ERC** (Electrical Rules Check)
- Update BOM
- Test in simulation if possible

### Step 2.4: Review PCB Layout

**Open PCB Editor:**
- From schematic: Tools → Update PCB from Schematic
- Or directly: `Oscilloscope.kicad_pcb`

**Check Layout:**
- **4-layer stackup:** Signal / Ground / Power / Signal
- High-speed traces (ADC → FPGA) are length-matched
- Ground pour on all layers
- Power decoupling caps near ICs
- Proper clearances for high voltage

**Important Considerations:**
- Analog and digital grounds separated, joined at one point
- Bypass capacitors close to IC power pins
- Trace impedance controlled for high-speed signals
- No ground plane splits under critical paths

### Step 2.5: Design Rule Check (DRC)

```
In PCB Editor:
- Inspect → Design Rules Checker
- Run DRC
- Fix all errors
- Review warnings
```

**Common Issues:**
- Trace too close to edge
- Via too close to pad
- Copper clearance violation
- Unconnected nets

### Step 2.6: Generate Manufacturing Files

#### Gerber Files (for fabrication)

```
In PCB Editor:
1. File → Plot
2. Settings:
   - Format: Gerber
   - Layers: All copper, soldermask, silkscreen, edge cuts
   - Options:
     ☑ Use Protel filename extensions
     ☑ Plot footprint values
     ☑ Plot footprint references
3. Plot Format Settings:
   - Coordinate format: 4.6, unit mm
4. Click "Plot"
5. Click "Generate Drill Files"
   - Format: Excellon
   - Units: Millimeters
   - Zeros: Decimal format
6. Generate Drill File
```

**Output Files:**
```
Oscilloscope-F_Cu.gbr        (Top copper)
Oscilloscope-In1_Cu.gbr      (Inner layer 1 - Ground)
Oscilloscope-In2_Cu.gbr      (Inner layer 2 - Power)
Oscilloscope-B_Cu.gbr        (Bottom copper)
Oscilloscope-F_Mask.gbr      (Top soldermask)
Oscilloscope-B_Mask.gbr      (Bottom soldermask)
Oscilloscope-F_SilkS.gbr     (Top silkscreen)
Oscilloscope-B_SilkS.gbr     (Bottom silkscreen)
Oscilloscope-Edge_Cuts.gbr   (Board outline)
Oscilloscope.drl             (Drill file)
```

#### Bill of Materials (BOM)

```
In Schematic:
1. Tools → Generate Bill of Materials
2. Select BOM plugin
3. Or use existing: Oscilloscope.csv / Oscilloscope.xlsx
```

**Review BOM:**
- Check component availability (Digi-Key, Mouser)
- Note lead times
- Verify part numbers
- Check for obsolete parts

### Step 2.7: Order PCBs

#### Recommended Manufacturers

**Budget Option (2-3 week delivery):**
- **JLCPCB** - jlcpcb.com
  - ~$20 for 5 boards
  - Good quality
  - Slow shipping (2-3 weeks)

**Fast Option (1 week delivery):**
- **OSH Park** - oshpark.com
  - ~$10/sq.in for 3 boards
  - High quality (Purple!)
  - Made in USA
  - 10-12 day turnaround

**Professional Option:**
- **PCBWay** - pcbway.com
- **Sunstone Circuits** - sunstone.com

#### Specifications to Order

```
Board Specifications:
- Layers: 4
- Dimensions: ~100mm x 70mm (check your design)
- Thickness: 1.6mm
- Copper weight: 1 oz (35μm)
- Surface finish: ENIG (best) or HASL
- Soldermask: Green (or your choice)
- Silkscreen: White
- Min trace/space: 6/6 mil
- Min hole: 0.3mm
```

#### Upload Files

1. Zip all Gerber files:
```bash
cd gerber_output/
zip oscilloscope_gerbers.zip *.gbr *.drl
```

2. Upload to manufacturer website
3. Review automatically generated preview
4. **CRITICAL:** Check preview carefully:
   - All layers present
   - Board outline correct
   - No missing copper
   - Drill holes aligned

5. Add to cart and order

**Cost:** $20-60 for 3-5 boards + shipping

### Step 2.8: Order Components

**Use BOM file:** `Oscilloscope.xlsx` or `.csv`

**Recommended Suppliers:**
- Digi-Key (digikey.com)
- Mouser (mouser.com)
- Newark/Element14

**Ordering Strategy:**
1. Copy BOM to spreadsheet
2. Search each part on supplier website
3. Check stock and price
4. Order 10% extra of small components (resistors, caps)
5. Order exact quantity for ICs

**Expected Cost:** $100-200 depending on ADC and components chosen

---

## Phase 3: Hardware Assembly

**Goal:** Assemble populated PCB  
**Duration:** 1-2 days  
**Prerequisites:** PCB received, components received

### Step 3.1: Gather Tools and Materials

#### Essential Tools

- **Soldering iron** (temperature controlled, 350°C)
  - Recommendation: Hakko FX-888D or similar
  - Fine tip (0.5mm conical)
- **Solder** (60/40 or 63/37 tin/lead, or lead-free)
  - 0.5mm or 0.8mm diameter
- **Flux** (rosin flux pen or paste)
- **Tweezers** (ESD-safe, fine tip)
- **Magnification**
  - Magnifying glass
  - Or microscope (10x-40x)
- **Multimeter**
- **Wire cutters** (flush cut)
- **Solder wick** (desoldering braid)
- **Isopropyl alcohol** (IPA, 90%+) and brush

#### Optional But Helpful

- Hot air rework station
- Solder paste and squeegee
- Stencil (for solder paste)
- Reflow oven (toaster oven conversion)
- Helping hands / PCB holder
- ESD mat and wrist strap

### Step 3.2: Prepare Workspace

1. **Clean work area**
2. **Good lighting** (LED desk lamp)
3. **ESD protection** (wrist strap grounded)
4. **Organize components:**
   - Sort by type
   - Label bags
   - Print BOM with checkboxes

### Step 3.3: Inspect PCB

**Before soldering:**
- [ ] Check for manufacturing defects
- [ ] Verify copper traces are intact
- [ ] Check board outline and dimensions
- [ ] Test continuity between power pins
- [ ] Check for shorts between power and ground

```bash
# Use multimeter in continuity mode
# Test all power nets for shorts to ground
# Should be open circuit (no beep)
```

### Step 3.4: Assembly Strategy

**Order of Assembly:**

1. ✅ Smallest components first (0402, 0603 resistors/caps)
2. ✅ ICs (ADC, op-amps, regulators)
3. ✅ Larger passives (electrolytic caps, inductors)
4. ✅ Connectors (PMOD, BNC, power)
5. ✅ Through-hole components last

**Reasoning:** Small parts are hard to access after large ones are placed

### Step 3.5: SMT Component Soldering

#### Method 1: Hand Soldering (No Special Equipment)

**For each component:**

1. **Apply flux** to pads
2. **Pre-tin one pad** (add small amount of solder)
3. **Place component** with tweezers
4. **Reheat tinned pad**, press component down
5. **Solder other pad(s)**
6. **Clean with IPA**

**Tips:**
- Work quickly but carefully
- Don't overheat (< 3 seconds per joint)
- Use minimal solder (less is more)
- Inspect with magnifier after each component

#### Method 2: Reflow Soldering (Recommended for Entire Board)

**Equipment needed:**
- Solder paste (SAC305 or similar)
- Stencil (can order with PCB)
- Squeegee (or old credit card)
- Toaster oven or reflow oven

**Process:**

1. **Apply solder paste:**
   - Align stencil over PCB
   - Apply paste with squeegee
   - Remove stencil carefully

2. **Place components:**
   - Use tweezers
   - Components will "stick" to solder paste
   - Check orientation (IC pin 1, electrolytic cap polarity)

3. **Reflow profile:**
```
Temperature Profile:
- Preheat: 150°C for 60-90 seconds
- Soak: 150-180°C for 60-120 seconds
- Reflow: 220-250°C for 30-60 seconds (peak)
- Cool down: Natural cooling
```

4. **Inspect joints:**
   - Shiny, smooth fillets
   - No bridges between pins
   - No cold joints (dull appearance)

### Step 3.6: Through-Hole Components

**Standard soldering:**

1. Insert component from top
2. Bend leads on bottom to hold in place
3. Solder from bottom
4. Trim excess lead
5. Clean flux

**Large connectors:**
- May need more heat
- Use larger tip
- Take time to fully heat pad and pin

### Step 3.7: Post-Assembly Inspection

#### Visual Inspection

**Check for:**
- [ ] Solder bridges between pins
- [ ] Cold solder joints (dull, grainy)
- [ ] Missing components
- [ ] Reversed polarity (electrolytic caps, diodes)
- [ ] IC orientation (pin 1 marker)

**Use microscope/magnifier for:**
- IC pin inspection (all pins soldered)
- Fine pitch components (< 0.5mm)
- BGA components if present

#### Electrical Testing

**Before applying power:**

```bash
# Multimeter in resistance mode

# 1. Check power supply shorts
#    Measure between each power rail and ground
#    Should read > 10kΩ typically (depends on design)

# 2. Check supply rails for continuity
#    Verify 3.3V net is continuous across board
#    Verify 5V net is continuous

# 3. Check critical signals
#    Verify PMOD pins are not shorted

# 4. Check component values (if uncertain)
#    Measure resistors in-circuit (approximate)
```

### Step 3.8: Clean PCB

```bash
# Materials:
- Isopropyl alcohol (IPA), 90%+
- Soft brush (toothbrush)
- Lint-free wipes
- Compressed air (optional)

# Process:
1. Apply IPA liberally with brush
2. Scrub gently to remove flux residue
3. Wipe with lint-free cloth
4. Repeat if needed
5. Dry with compressed air or let air dry
6. Inspect under magnification
```

**Result:** Clean, professional-looking board ready for testing

---

## Phase 4: Hardware Bring-Up

**Goal:** Verify PCB functions correctly  
**Duration:** 2-5 days  
**Prerequisites:** Assembled PCB, test equipment

### Step 4.1: Pre-Power Inspection

**Critical Checklist:**
- [ ] All components soldered correctly
- [ ] No solder bridges
- [ ] Correct component orientations
- [ ] No shorts between power and ground
- [ ] Visual inspection complete
- [ ] PCB cleaned of flux residue

### Step 4.2: First Power-On

**Setup:**
1. **Current-limited power supply** (bench supply)
2. Set voltage to 5V (or board's input voltage)
3. **Set current limit to 100mA** (important!)
4. Connect to board power input
5. Multimeter ready to measure voltages

**Power-On Sequence:**

```bash
# 1. Connect power supply, DO NOT turn on yet
# 2. Set current limit to 100mA
# 3. Set voltage to 5.0V
# 4. Turn on supply

# Observe:
# - Current draw should be < 100mA typically
# - If current limit trips immediately: POWER OFF, check for shorts
# - Normal draw: 50-100mA without FPGA, 200-500mA with FPGA

# 5. Measure voltages:
Measure 5V rail: Should be 5.0V ± 0.1V
Measure 3.3V rail: Should be 3.3V ± 0.05V
Measure analog supply (if separate): Should match design voltage
```

**Troubleshooting First Power:**

| Symptom | Likely Cause | Fix |
|---|---|-----|
| Current limit trips immediately | Short circuit | Find and fix short |
| No voltage on outputs | Regulator not soldered | Check regulator |
| Low voltage (< spec) | Excessive load or regulator damaged | Check components |
| Voltage oscillating | Instability, missing decoupling caps | Add/fix caps |

### Step 4.3: Test Power Supply Subsystem

**Measure all voltage rails:**

```bash
# Multimeter in DC voltage mode

# Expected voltages (your design may vary):
V_IN (input):          5.0V ± 0.1V
V_3V3 (digital):       3.3V ± 0.05V
V_ANALOG (analog):     3.3V or 5.0V ± 0.05V
V_ADC (ADC supply):    Check datasheet

# Test points:
- At regulator output
- At IC power pins (verify voltage arrives)
- At far end of board (check for voltage drop)

# Load testing:
# Increase current limit to 500mA or 1A
# Monitor voltage stability under load
```

**Ripple measurement (optional but good):**
```bash
# Oscilloscope required
# AC couple, 10mV/div
# Measure ripple on each supply rail
# Should be < 50mV peak-to-peak typically
```

### Step 4.4: Connect FPGA via PMOD

**PMOD Connector:**
- Verify pin assignments match FPGA board
- Check continuity from PMOD pins to circuit
- Verify no shorts between adjacent pins

**Connection to Arty:**
1. Power off both boards
2. Connect PMOD cable (use correct port on Arty)
3. Verify pinout: GND on pin 5, 11
4. Power on Arty first
5. Power on oscilloscope board

### Step 4.5: Test SPI Communication

**Using FPGA:**

Create simple SPI test in Vitis (or use ILA in Vivado):

```c
// Simple SPI loopback test in Vitis
#include "xspi.h"

// Initialize SPI
XSpi_Initialize(&spi_instance, SPI_DEVICE_ID);
XSpi_SetOptions(&spi_instance, XSP_MASTER_OPTION);
XSpi_Start(&spi_instance);

// Send test pattern
uint8_t tx_data[4] = {0xAA, 0x55, 0xF0, 0x0F};
uint8_t rx_data[4];

XSpi_Transfer(&spi_instance, tx_data, rx_data, 4);

// Check rx_data with oscilloscope or logic analyzer
```

**Expected:**
- SPI clock toggles (verify with scope)
- MOSI shows data pattern
- MISO responds (ADC dependent)
- CS asserts low during transfer

### Step 4.6: Test ADC

**ADC Power:**
- Verify ADC power pins have correct voltage
- Check reference voltage (if external)

**ADC Configuration:**
```c
// Example for typical ADC
// Check your ADC datasheet for actual commands

// Read ADC ID register
uint8_t cmd_read_id[] = {0x00, 0x00};  // Example command
uint8_t response[2];
XSpi_Transfer(&spi_instance, cmd_read_id, response, 2);

// response should match ADC ID (check datasheet)
xil_printf("ADC ID: 0x%02X\r\n", response[1]);

// Configure ADC for data capture
// Send configuration commands per datasheet
```

**Test analog input:**
1. Apply known voltage to input (use function generator or DC source)
2. Read ADC values
3. Verify correct readings
4. Test multiple voltage levels
5. Check linearity

### Step 4.7: Signal Path Testing

**End-to-end test:**

```
Signal Generator → Oscilloscope Input → ADC → FPGA → UART Output
```

**Test procedure:**
1. Apply 1kHz, 1Vpp sine wave to input
2. Capture samples in FPGA
3. Output to UART or store in memory
4. Verify waveform shape and frequency

**Python script to analyze UART output:**
```python
import serial
import numpy as np
import matplotlib.pyplot as plt

# Open serial port
ser = serial.Serial('/dev/ttyUSB1', 115200)

# Read samples
samples = []
for i in range(1000):
    line = ser.readline().decode('utf-8').strip()
    try:
        value = int(line, 16)  # If hex format
        samples.append(value)
    except:
        pass

# Plot
plt.plot(samples)
plt.xlabel('Sample')
plt.ylabel('ADC Value')
plt.title('Captured Waveform')
plt.savefig('waveform.png')
plt.show()
```

---

## Phase 5: Software Development

**Goal:** Develop and test embedded firmware  
**Duration:** 2-4 weeks  
**Prerequisites:** Hardware working, Vitis installed

### Step 5.1: Set Up Vitis Workspace

```bash
# Create or open existing workspace
cd /path/to/oscilloscope_project/oscilloscope-software

# Launch Vitis
vitis -workspace ./ &

# Or if not in PATH:
/tools/Xilinx/Vitis/2020.1/bin/vitis -workspace ./ &
```

### Step 5.2: Create Platform Project

**If not already present:**

1. **File → New → Platform Project**
2. Name: `oscilloscope_platform`
3. Hardware Specification: Browse to `design_1_wrapper.xsa`
4. Operating System: `standalone` (bare-metal)
5. Processor: `microblaze_0`
6. Click **Finish**

**Platform will generate:**
- Board support package (BSP)
- Driver libraries
- Memory map
- Interrupt handlers

### Step 5.3: Create Application Project

**If starting from scratch:**

1. **File → New → Application Project**
2. Name: `oscilloscope_app`
3. Platform: Select `oscilloscope_platform`
4. Template: `Empty Application` or `Hello World`
5. Click **Finish**

### Step 5.4: Software Architecture

**Recommended structure:**

```
oscilloscope_app/
├── src/
│   ├── main.c              # Main application loop
│   ├── adc_driver.c        # ADC communication
│   ├── adc_driver.h
│   ├── capture.c           # Data capture state machine
│   ├── capture.h
│   ├── trigger.c           # Trigger detection
│   ├── trigger.h
│   ├── display.c           # Output formatting
│   ├── display.h
│   └── config.h            # Configuration constants
└── README.md
```

### Step 5.5: Implement Core Functionality

#### Main Loop Structure

```c
// main.c
#include <stdio.h>
#include "xparameters.h"
#include "xil_printf.h"
#include "adc_driver.h"
#include "capture.h"
#include "trigger.h"

// System configuration
#define ADC_SAMPLE_RATE     100000000  // 100 MSPS
#define CAPTURE_DEPTH       4096       // Number of samples
#define TRIGGER_LEVEL       2048       // Mid-scale

int main() {
    int status;
    
    // Initialize hardware
    xil_printf("=== Digital Oscilloscope ===\r\n");
    
    // Initialize ADC
    status = adc_init();
    if (status != XST_SUCCESS) {
        xil_printf("ADC initialization failed!\r\n");
        return XST_FAILURE;
    }
    
    // Initialize capture buffer
    capture_init(CAPTURE_DEPTH);
    
    // Configure trigger
    trigger_set_level(TRIGGER_LEVEL);
    trigger_set_edge(TRIGGER_RISING);
    
    xil_printf("Initialization complete. Waiting for trigger...\r\n");
    
    // Main loop
    while (1) {
        // Wait for trigger
        if (trigger_detected()) {
            // Capture samples
            capture_arm();
            
            // Wait for capture complete
            while (!capture_complete()) {
                // Could add timeout here
            }
            
            // Process and display data
            uint16_t *samples = capture_get_buffer();
            display_waveform(samples, CAPTURE_DEPTH);
            
            // Reset for next capture
            trigger_reset();
        }
        
        // Handle user input (commands over UART)
        if (uart_data_available()) {
            char cmd = uart_getchar();
            handle_command(cmd);
        }
    }
    
    return 0;
}
```

#### ADC Driver Implementation

```c
// adc_driver.c
#include "adc_driver.h"
#include "xspi.h"
#include "xparameters.h"

static XSpi spi_instance;

int adc_init(void) {
    int status;
    
    // Initialize SPI driver
    status = XSpi_Initialize(&spi_instance, XPAR_SPI_0_DEVICE_ID);
    if (status != XST_SUCCESS) {
        return XST_FAILURE;
    }
    
    // Set options
    XSpi_SetOptions(&spi_instance, 
                    XSP_MASTER_OPTION | 
                    XSP_CLK_ACTIVE_LOW_OPTION);
    
    // Start SPI
    XSpi_Start(&spi_instance);
    
    // Configure ADC (device-specific)
    // Send configuration commands per datasheet
    adc_configure();
    
    return XST_SUCCESS;
}

uint16_t adc_read_sample(void) {
    uint8_t tx_buf[2] = {0x00, 0x00};  // Read command
    uint8_t rx_buf[2];
    
    XSpi_Transfer(&spi_instance, tx_buf, rx_buf, 2);
    
    // Combine bytes (MSB first typically)
    uint16_t sample = (rx_buf[0] << 8) | rx_buf[1];
    
    return sample;
}

void adc_configure(void) {
    // Device-specific configuration
    // Example: Set ADC to continuous conversion mode
    uint8_t config_cmd[] = {ADC_CONFIG_REG, ADC_CONTINUOUS_MODE};
    XSpi_Transfer(&spi_instance, config_cmd, NULL, 2);
}
```

#### Capture Engine

```c
// capture.c
#include "capture.h"
#include <stdlib.h>

static uint16_t *capture_buffer;
static uint32_t capture_size;
static uint32_t capture_index;
static bool capturing;

void capture_init(uint32_t size) {
    capture_size = size;
    capture_buffer = (uint16_t*)malloc(size * sizeof(uint16_t));
    capture_index = 0;
    capturing = false;
}

void capture_arm(void) {
    capture_index = 0;
    capturing = true;
}

void capture_sample(uint16_t sample) {
    if (capturing && capture_index < capture_size) {
        capture_buffer[capture_index++] = sample;
        
        if (capture_index >= capture_size) {
            capturing = false;
        }
    }
}

bool capture_complete(void) {
    return !capturing;
}

uint16_t* capture_get_buffer(void) {
    return capture_buffer;
}
```

### Step 5.6: Build and Test

**Build Project:**
```bash
# In Vitis:
Project → Build Project

# Or right-click project → Build Project

# Check console for errors
```

**Program FPGA and Run:**
```bash
# 1. Program FPGA (if not already done)
Xilinx → Program FPGA

# 2. Run application
Run → Run Configurations
Select configuration → Run

# Or use Debug for step-through debugging
```

**Monitor Output:**
```bash
# Open serial terminal
minicom -D /dev/ttyUSB1 -b 115200

# Or in Vitis:
Window → Show View → Vitis Serial Terminal
Click + to add connection (115200 baud)
```

### Step 5.7: Implement Advanced Features

**Features to add:**

1. **Trigger modes:**
   - Rising edge
   - Falling edge
   - Both edges
   - Level trigger

2. **Capture modes:**
   - Single shot
   - Continuous/auto
   - Normal (wait for trigger)

3. **Signal processing:**
   - FFT (frequency domain)
   - RMS calculation
   - Peak detection
   - Frequency measurement

4. **User interface:**
   - UART command interpreter
   - Settings adjustment
   - Waveform export

5. **Data storage:**
   - Save to DDR3 memory
   - Export via Ethernet
   - Log to SD card (if available)

---

## Phase 6: System Integration and Testing

**Goal:** Complete, tested oscilloscope system  
**Duration:** 1-2 weeks

### Step 6.1: System-Level Testing

**Test Plan:**

| Test ID | Description | Expected Result | Status |
|---|---|---|---|
| SYS-001 | Power-on, all rails correct | 5V, 3.3V within spec | [ ] |
| SYS-002 | FPGA programs successfully | DONE LED on | [ ] |
| SYS-003 | UART communication works | Boot message received | [ ] |
| SYS-004 | ADC responds to SPI | ID register read | [ ] |
| SYS-005 | Capture DC input | Correct ADC value | [ ] |
| SYS-006 | Capture 1kHz sine wave | Correct frequency | [ ] |
| SYS-007 | Trigger on rising edge | Capture aligned | [ ] |
| SYS-008 | Sample rate accuracy | Within 1% | [ ] |
| SYS-009 | Input range correct | ±5V captured | [ ] |
| SYS-010 | Continuous operation | No crashes, 1hr+ | [ ] |

### Step 6.2: Performance Characterization

**Measurements to take:**

```python
# Use Python scripts to automate testing

import serial
import numpy as np
import matplotlib.pyplot as plt
from scipy import signal, fft

# 1. Sample Rate Accuracy
# Apply known frequency, measure captured frequency

# 2. Bandwidth
# Sweep frequency, measure -3dB point

# 3. Noise Floor
# Short input, measure noise

# 4. Dynamic Range
# Measure SNR at various input levels

# 5. Linearity
# Apply various DC voltages, check ADC response
```

### Step 6.3: Calibration

**Offset Calibration:**
```c
// Short input to ground
// Measure average value
int16_t offset_calibration(void) {
    int32_t sum = 0;
    for (int i = 0; i < 1000; i++) {
        sum += adc_read_sample();
    }
    return sum / 1000;
}

// Apply offset in real-time
uint16_t calibrated_sample = raw_sample - offset;
```

**Gain Calibration:**
```c
// Apply known voltage (e.g., 1.000V from calibrated source)
// Measure ADC value
float gain_calibration(float known_voltage) {
    float measured_voltage = adc_read_sample() * ADC_LSB;
    return known_voltage / measured_voltage;
}
```

### Step 6.4: Create User Documentation

**Minimum documentation:**
- Operating instructions
- Specifications (bandwidth, sample rate, etc.)
- Calibration procedure
- Troubleshooting guide
- Known limitations

### Step 6.5: Final Validation

**Before declaring "complete":**

✅ All tests pass  
✅ Performance meets specifications  
✅ Calibration performed  
✅ Documentation written  
✅ Code committed to version control  
✅ PCB files archived  
✅ Hardware photos taken  

---

## Troubleshooting Guide

### FPGA Issues

#### Vivado Won't Open Project
- Check Vivado version compatibility
- Try: Tools → Report → Report IP Status → Upgrade IP
- Regenerate output products

#### Synthesis Fails
- Check Messages tab for first error
- Common: Missing IP, incorrect version
- Solution: Regenerate IP, update to compatible version

#### Implementation Fails - Timing
- Relax timing constraints (temporary)
- Add pipeline stages
- Reduce clock frequency
- Check for combinational loops

#### Bitstream Won't Program
- Check JTAG connection
- Verify board power
- Try: Cable → Auto Connect
- Check USB drivers (Windows)

### Hardware Issues

#### No Power Output
- Verify input voltage
- Check regulator solder joints
- Measure regulator input
- Replace regulator if damaged

#### ADC Not Responding
- Check power at ADC pins
- Verify SPI connections (continuity)
- Check CS, CLK, MOSI signals with scope
- Review ADC initialization code

#### Noise/Instability
- Check ground plane integrity
- Add decoupling caps if missing
- Separate analog and digital grounds
- Check for ground loops

#### Incorrect Readings
- Calibrate offset and gain
- Check reference voltage
- Verify input conditioning circuit
- Test with known signal source

### Software Issues

#### Application Won't Build
- Clean and rebuild
- Check BSP is up to date
- Regenerate platform if hardware changed
- Verify all source files added to project

#### No UART Output
- Check baud rate (115200)
- Verify UART cable connected
- Check COM port number
- Try different terminal program

#### System Crashes/Hangs
- Check for stack overflow (increase stack size)
- Check for infinite loops
- Add watchdog timer
- Use debugger to find crash location

#### Data Corruption
- Check memory alignment
- Verify buffer sizes
- Check for array out-of-bounds
- Enable cache coherency if using DMA

---

## Performance Optimization

### Improving Sample Rate

**1. Optimize SPI Clock:**
```c
// Increase SPI clock speed to maximum supported by ADC
XSpi_SetOptions(&spi_instance, XSP_MASTER_OPTION);
// May need to adjust in block design
```

**2. Use DMA for Data Transfer:**
- Add AXI DMA IP to block design
- Configure to transfer ADC samples to DDR3
- Eliminates CPU overhead

**3. FPGA-Based Capture:**
- Move capture logic to FPGA (HDL)
- CPU only reads after capture complete
- Achieves maximum ADC sample rate

### Reducing Noise

**1. PCB Layout:**
- Minimize trace lengths (analog)
- Proper grounding
- Shielding if necessary

**2. Filtering:**
- Add anti-alias filter before ADC
- Digital filtering in FPGA or software

**3. Power Supply:**
- Use LDO regulators for analog supply
- Add ferrite beads
- Increase decoupling capacitors

### Improving Accuracy

**1. Better ADC:**
- Higher resolution (14-bit, 16-bit)
- Lower noise
- Better linearity

**2. Precision Reference:**
- Use precision voltage reference IC
- Temperature-compensated

**3. Calibration:**
- Implement full 2-point calibration
- Store calibration in EEPROM
- Periodic auto-calibration

---

## Next Steps and Enhancements

### Hardware Enhancements
- [ ] Multiple input channels (2-4)
- [ ] Programmable gain amplifier (PGA)
- [ ] AC/DC coupling switch
- [ ] Trigger output (for other instruments)
- [ ] Display interface (SPI/HDMI)

### Software Features
- [ ] GUI application (Qt/Python)
- [ ] Ethernet/TCP data streaming
- [ ] Waveform math functions
- [ ] Protocol decoders (I2C, SPI, UART)
- [ ] Automated measurements
- [ ] FFT/frequency analysis
- [ ] Waveform recording/playback

### Advanced Features
- [ ] Arbitrary waveform generator (AWG)
- [ ] Logic analyzer functionality
- [ ] Mixed-signal analysis
- [ ] Long-term data logging
- [ ] Remote web interface
- [ ] SCPI command compatibility

---

## Conclusion

You now have a complete guide to building a professional digital oscilloscope from scratch!

**Achievement Unlocked:**
- ✅ FPGA design and programming
- ✅ PCB design and manufacturing
- ✅ SMT assembly
- ✅ High-speed analog circuit design
- ✅ Embedded software development
- ✅ System integration and testing

**Skills Gained:**
- Digital signal processing
- Hardware-software co-design
- Professional debugging techniques
- Complete product development cycle

**What You've Built:**
A fully functional, custom digital oscilloscope that demonstrates real-world embedded systems engineering.

---

## Additional Resources

### Books
- "Architecting High-Performance Embedded Systems" by Jim Ledin
- "The Art of Electronics" by Horowitz & Hill
- "High-Speed Digital Design" by Howard Johnson

### Websites
- Xilinx Forums: forums.xilinx.com
- EEVblog Forum: eevblog.com/forum
- All About Circuits: allaboutcircuits.com
- Stack Exchange - Electrical Engineering

### Tools
- LTspice (circuit simulation)
- KiCad tutorials: kicad.org/help/tutorials
- Vivado tutorials: xilinx.com/training

---

**Congratulations on completing this advanced project!**

You've gained invaluable experience in modern embedded systems design. This oscilloscope can serve as a foundation for even more advanced projects.

**Share your success:**
- Document your build
- Post on forums/Reddit
- Help others who attempt this project
- Consider making it open-source

**Happy building!** 🎉🔬⚡

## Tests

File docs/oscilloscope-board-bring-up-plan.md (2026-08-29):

# Board Bring-Up Plan

## Safety boundary

**0–12 V DC RATED MEASUREMENT; 15 V OVERLOAD-SURVIVAL TARGET UNVERIFIED; GROUND REFERENCED; NOT ISOLATED; NO MAINS/CAT/HIGH ENERGY; NO NEGATIVE INPUT.**

## Power-off checks

1. Before assembly release, exclude the fourteen fabricated 1.0 × 1.0 mm test pads from BOM and pick-and-place; keep TP_GND (Keystone 4952) included.
2. Review Gerbers for protected dangling traces `Trace a4ae` and `Trace b74f`; clean up or record an explicit waiver.
3. Verify no short from VBUS_RAW, VBUS_PROT, 3V3 or VDDA to GND.
4. Confirm the fitted GND–AGND 0 Ω bond and USB-shield 0 Ω production bond.
5. Confirm BAV199 orientation on both channels: pin 1 AGND, pin 3 CHx_CLAMP, pin 2 VDDA.
6. Confirm LCD option and straps: pins 11–14, 19 and 20 high; pins 15–17 common MOSI; pin 18 SCK; pins 1–4 unused; pin 6 solid GND.
7. Confirm R12/R18 are 47 Ω Yageo RC0603FR-0747RL and fitted Q1 is NCE3401.

## Initial powered checks

1. Power from a current-limited USB source with the backlight disabled.
2. Measure TP_VBUS_RAW, TP_VBUS_PROT, TP_3V3, TP_VDDA and TP_GND.
3. Check LDO and ferrite temperatures and verify stable 3V3/VDDA rails.
4. Attach STDC14 and confirm SWDIO, SWCLK, NRST and VTref operation.
5. Program minimal firmware and verify the VCP crossover with a UART loopback test.

## Functional checks

1. Confirm USB enumeration and D+/D− continuity at the small test pads without long probe stubs.
2. Exercise RUN/STOP, MODE and SELECT; verify clean active-low transitions at the MCU-side RC nodes.
3. Test all four LEDs and verify intended roles.
4. Initialize the ERM19296-1 logic before enabling the backlight.
5. Sweep PA8 PWM and measure backlight current. Retain 27 Ω only if the maximum-brightness current is 60–75 mA under the defined VBUS condition.
6. Apply precision low-voltage DC sources to CH1 and CH2. Compare TP_CHx_IN, TP_CHx_DIV and TP_CHx_ADC; verify symmetry and ADC mapping.
7. Verify the fitted ADC isolation resistors are **47 Ω R12/R18** and C18/C25 remain 1.0 nF.
8. Alternate channel-equivalent inputs near 0.5 V and 12 V at the locked 80 MHz, 12.5-cycle sequence. Measure rank-end settling/crosstalk; acceptance is ≤1 LSB external acquisition error before ADC intrinsic TUE is added.
9. Perform square-wave and swept-sine compensation tests. Start with 15.1 pF total low-arm capacitance (8.2+2.2+4.7 pF), compare 12.9 pF, and reject 8.2 pF-only unless measured DC–100 kHz response remains within ±1 dB.
10. Measure the zero-input ADC floor and input-equivalent dead zone; characterize/calibrate the TLV9062 near-ground output limit rather than assuming a true zero code.
11. Repeat 0→12 V, 12→0 V, 1 kHz square, and 100 kHz sine tests on both channels and record overshoot, settling, gain, phase, and channel symmetry.
12. Perform current-limited 15 V positive overload/recovery tests. Negative-input and +20 V abuse tests are engineering stress tests only; keep them current-limited and do not convert them into user ratings.
13. Exercise 20→70 mA and 20→100 mA 3.3 V load steps and 0→75 mA backlight steps while recording VBUS_PROT/3V3 dip, overshoot, and AP7361C temperature.
14. Verify the actual pre-enumeration state remains below 100 mA with the backlight off; the 100 mA validation rail case plus regulator/TVS current is slightly above a strict 100 mA limit.

## Prototype gates

Do not close the design on schematic, layout, routing, or simulation evidence alone for bandwidth, divider compensation, 15 V overload survival, backlight operating point, USB ESD/hot-plug robustness, ADC timing, thermals, or HSI accuracy. The configured USB 45 Ω single-ended / 90 Ω differential target is not a measured or certified result.

## PCB baseline for bring-up records

Record that the tested article is the 100 × 100 mm, four-copper-layer, nominal 1.30 mm custom-stackup board with all components top-side. Pre-test CAD status is zero airwires and zero DRC errors. USB_DP includes a bottom-layer bypass with explicit top/bottom transition vias.

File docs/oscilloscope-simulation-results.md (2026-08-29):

# Simulation Results

## Scope and claim boundary

This file records Rev 0.2 analog-front-end SPICE simulations and power-path bounded calculations using the current schematic values and selected MPN properties. **These are modeled results, not measured prototype performance, safety certification, surge/ESD verification, or proof of component survival.**

Simulation date: 2026-08-24.

## Executive reconciliation

| Locked target / question | Result | Disposition |
|---|---|---|
| 0–12 V normal range | **Pass with limitation** | Nominal 12 V produces about 2.1817 V at ADC. TLV9062 worst-case output swing implies a possible ~20 mV zero floor (~0.11 V input-equivalent), requiring calibration/bench characterization. |
| 15 V overload-survival target | **Pass in electrical operating-point model; survival unverified** | 15 V produces about 2.7271 V; divider/clamp currents and resistor powers are small and the op-amp remains in its recommended common-mode range. Hardware overload/recovery testing remains mandatory. |
| ±1 dB DC–100 kHz | **Fail with fitted 8.2 pF only; pass with trim** | Baseline peaks about +2 to +4 dB depending BAV199 capacitance. Robust modeled choice is 15.1 pF total low-arm capacitance (8.2+2.2+4.7 pF); 12.9 pF is flattest if diode/stray capacitance is near 4 pF. |
| Expected ~200 kHz usable bandwidth | **Conditional pass** | 15.1 pF passes 100 kHz robustly but can be slightly beyond −1 dB near 200 kHz with high diode capacitance/source resistance. 12.9 pF gives ~298 kHz ±1 dB span in the 4 pF diode-cap case. Bench trim remains required. |
| ADC settling at 80 MHz, 12.5 cycles, original 330 Ω/1 nF | **Failed; corrected** | The original network produced about 9.5–9.9 LSB external acquisition error. R12/R18 are now 47 Ω with C18/C25 retained at 1 nF. |
| Implemented 47 Ω/1 nF network | **Pass in bounded model** | Worst modeled external acquisition error is 0.450 mV = 0.558 LSB for RADC bounds 0–680 Ω. R12/R18 are implemented as Yageo RC0603FR-0747RL. This remains modeled, not measured. |
| USB 125/145/175 mA budget cases | **Pass** | Including 80 µA LDO IQ and 20 µA TVS leakage gives approximately 125.10/145.10/175.10 mA. |
| AP7361C headroom/thermal | **Pass, layout-dependent** | Worst protected VBUS 4.3648 V; no dropout rows. Maximum LDO dissipation 0.1919 W, corresponding to ~28.8 °C rise with datasheet 150 °C/W test-board θJA. |
| Backlight current | **Unresolved by design evidence** | 60/75 mA were imposed load cases. Required LCD LED Vf is calculated, not verified. Retain the 27 Ω value-selection prototype gate. |

## Authoritative source parameters and model limitations

The following source-identified values were extracted from the manufacturer datasheets attached to the current project components. The extraction path returned OCR evidence without immutable inline citation IDs, so these facts are identified by datasheet document/table rather than represented as citation-resolved claims.

- **TLV9062, TI SBOS839N:** 10 MHz gain-bandwidth, 55° typical phase margin, 6.5 V/µs typical slew rate, common-mode range V−−0.1 V to V++0.1 V, output swing within 20 mV maximum of the rails at 10 kΩ, 0.5 pA typical input bias, 100 pF stated capacitive-load drive, signal-input absolute maximum V−−0.5 V to V++0.5 V and ±10 mA.
- **STM32L432, ST DS11451 Rev 4 Tables 63/64 and Figure 22:** CADC=5 pF typical; PA0/PA1 are fast channels; 12-bit 12.5-cycle sampling at 80 MHz is 156.25 ns; maximum external input impedance is 680 Ω.
- **BAV199LT1G, onsemi electrical characteristics:** each diode has ≤2 pF capacitance at 0 V/1 MHz, ≤5 nA leakage at 70 V/25 °C, and maximum Vf anchors 0.9 V at 1 mA and 1.0 V at 10 mA.
- **AP7361C, Diodes Inc. DS37274:** IQ 60 µA typical/80 µA maximum; dropout ≤140 mV at 300 mA for 2.6–3.3 V versions; output capacitor ≥2.2 µF with 10–300 mΩ ESR; 150 µs typical startup test; SOT-89-5 θJA=150 °C/W on the specified 1×1 inch minimum-pad FR-4 board.
- **MF-PSMF035X-2, Bourns:** 0.35 A hold, 0.75 A trip, 0.25 Ω Rmin, 1.2 Ω R1max, 0.14 A hold at 85 °C.
- **SMAJ5.0A-TR, ST:** 5.0 V stand-off, 20 µA maximum leakage at the stated test point, 6.4 V minimum breakdown, 13.4 V maximum clamp at the specified pulse current. TVS capacitance was not numerically resolved from the graph.
- **NCE3401 (fitted Q1):** 75 mΩ maximum RDS(on) at VGS=−4.5 V; θJA=104 °C/W under its stated board condition.
- **2N7002KT1G:** 2.5 Ω maximum RDS(on) at 4.5 V/200 mA; steady-state θJA depends strongly on copper area (300–417 °C/W stated conditions). Its steady load here is only the ~50 µA pull-up current.
- Selected passives are the exact MPNs in [Passive Sourcing Report](../files/passive-sourcing-report): Vishay TNPW 300 kΩ/200 kΩ precision parts, KEMET C0G compensation/filter capacitors, TDK 4.7 µF X7R regulator capacitors, and Yageo resistors.

No directly integrated vendor TLV9062 or AP7361C ngspice macromodel was available in the simulation invocation. The TLV9062 was therefore represented by a behavioral model constrained by datasheet GBW, phase margin, slew rate, common-mode, and output swing. AP7361C dynamic behavior is reported as bounded capacitor/ESR/dropout analysis rather than a fabricated loop model. TDK 4.7 µF DC-bias derating was not numerically available; transient calculations use nominal and tolerance-minimum 4.23 µF and must be rechecked against measured effective capacitance.

## Analog modeled circuit

One channel represents both identical channels:

`Vin—Rs—R7 300k—R8 300k—R9 300k—CH1_CLAMP; R10 200k to AGND; 12 pF across each 300k; 8.2 pF plus optional 2.2/4.7 pF across R10; BAV199 pin1 AGND, pin3 clamp, pin2 VDDA; R11 10k to TLV9062 follower; R12 47 Ω to ADC; C18 1 nF to AGND; STM32 CADC 5 pF.`

Source resistance cases were 50 Ω, 1 kΩ, and 100 kΩ. BAV199 off-capacitance was bounded from 0 to 4 pF total at the clamp node.

### DC and gain/linearity

| Vin | Ideal divider | Simulated ADC, nominal Rs=50 Ω |
|---:|---:|---:|
| 0 V | 0 V | ~20 mV behavioral output-floor bound |
| 0.2 V | 36.364 mV | 36.362 mV |
| 2 V | 0.363636 V | 0.363617 V |
| 6 V | 1.090909 V | 1.090849 V |
| 10 V | 1.818182 V | 1.818081 V |
| 12 V | 2.181818 V | 2.181697 V |
| 15 V | 2.727273 V | 2.727121 V |

At +20 V and low source resistance, CH1_CLAMP is about 3.636 V: above the 3.4 V recommended common-mode limit but below the 3.8 V absolute-maximum input-voltage limit. This is functional overdrive, not a verified safe operating condition. At −15 V, the external clamp model gives about −0.71 V, beyond the TLV9062 −0.5 V absolute-maximum voltage bound before its internal input clamp is included. Negative inputs remain explicitly prohibited.

Worst divider resistor dissipation over −15 to +20 V was ~0.10 mW per 300 kΩ part versus 0.52 W rating. This does not constitute a high-energy-source safety assessment.

### AC compensation

For Rs=50 Ω and BAV199=4 pF total:

| Low-arm C | Peak | ±1 dB span | −3 dB BW | 100 kHz result |
|---:|---:|---:|---:|---|
| 8.2 pF | +1.98 dB | 41 kHz | 774 kHz | Fail |
| 10.4 pF | +1.08 dB | 76.8 kHz | 645 kHz | Marginal/fail |
| 12.9 pF | +0.22 dB | 298 kHz | 523 kHz | Pass |
| 15.1 pF | no positive peak | 183 kHz | 429 kHz | Pass |

For BAV199=0 pF, only 15.1 pF passes the ±1 dB through 100 kHz target robustly. The 100 kΩ source reduces low-frequency gain as expected and narrows bandwidth, but 15.1 pF still passes 100 kHz.

**Expected population:** fit both trim parts for **15.1 pF total** as the robust simulation default, then select 12.9 pF instead only if prototype measurements show clamp/stray capacitance near the upper modeled bound. The current 8.2 pF-only fitted baseline does not meet the locked flatness target in the model.

[Exact raw-vector Bode plot](https://cdn2.flux.ai/flux-comment-files/files/commentFileId-cfeb2e3c91774b860bef7d3d6ae9f5212f864f685733756fa9281511fd41daad.png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)

[Exact plotted AC vectors CSV](https://cdn2.flux.ai/flux-comment-files/files/commentFileId-6255a8716985bdaef2be784c032de7df9cbc3f936438c63883aa5ea522067ec8.csv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)

### Transient behavior

The exact four-case AC sweep is authoritative for trim selection. A separate transient run used a simulator-selected ~14 pF low-arm case, not an exact production population; it is retained only as a behavioral illustration. It reduced rising-edge overshoot from ~26–27% with 8.2 pF to ~3%. Full-scale rising-step settling to ±1 ADC LSB remained ~17.5 µs in that behavioral model. Detailed THD and exact settling require the vendor macromodel and prototype measurement.

[100 kHz behavioral transient plot](https://cdn2.flux.ai/flux-comment-files/files/commentFileId-f514b4784acf8fbf21e6c81846089c4d95705bf9c503eca6c23d4357e78c8a13.png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)

### ADC acquisition settling and implemented correction

The original 330 Ω/1 nF network failed the 12.5-cycle alternating-channel case:

- End-of-acquisition error: **7.63–7.99 mV = 9.48–9.91 LSB** for RADC bounds 0–1.5 kΩ.
- Dominant mechanism: 5 pF sample-cap charge sharing kicks the local 1 nF node by ~11–12 mV, followed by recovery through 330 Ω.
- This external dynamic error is additional to the STM32 ADC intrinsic TUE.

[ADC acquisition waveform](https://cdn2.flux.ai/flux-comment-files/files/commentFileId-d196929d74555ab5165f09f0cc83d76e55a8e330eb5f28de092caae7130d685f.png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)

A candidate sweep showed **47 Ω with the existing 1 nF** is the least-invasive value change that preserves the filter capacitor and passes both RADC=0 and 680 Ω bounds: **0.450 mV = 0.558 LSB worst case**. 100 Ω/470 pF does not pass; 47 Ω/470 pF passes with larger margin but changes both parts.

[ADC candidate screening CSV](https://cdn2.flux.ai/flux-comment-files/files/commentFileId-63e4213e45febfdf0c0494c0fe9b49147d5dc2ad50fa8f390a3d9c0cdbd51140.csv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)

**Implemented before layout freeze:** R12 and R18 were changed from **330 Ω to 47 Ω**, retaining C18/C25 at 1.0 nF. Production MPN is Yageo **RC0603FR-0747RL** for both channels. Focused hardware validation remains required for channel-to-channel acquisition settling and op-amp stability with the routed parasitics.

## Power-path model and results

### DC matrix

Modeled topology:

`USB source—cable resistance—MF-PSMF035X-2—VBUS_PROT`, with SMAJ5.0A leakage and C1=4.7 µF; AP7361C to 3.3 V with C2=4.7 µF and 100 kΩ EN pull-up; direct backlight load through NCE3401 and 27 Ω.

Matrix dimensions:

- USB: 4.75/5.0/5.25 V
- Cable: 0.1/0.5/1.0 Ω
- PPTC: 0.25 Ω cold-min and 1.2 Ω R1max
- 3.3 V load: 50/70/100 mA
- Backlight: 0/60/75 mA

Key results across 162 points:

- Worst VBUS_PROT: **4.3648 V** at 4.75 V, 1 Ω cable, 1.2 Ω PPTC, 100 mA rail and 75 mA backlight.
- Worst LDO headroom after dropout bound: **1.0181 V**; regulation failures: **0/162**.
- Maximum LDO dissipation: **0.1919 W**.
- θJA=150 °C/W calculated rise: **28.8 °C**, strongly layout/ambient dependent.
- At 75 mA backlight: 27 Ω resistor dissipation **151.9 mW**; NCE3401 dissipation using 75 mΩ maximum **0.422 mW**.
- Required LCD Vf is `VBUS_PROT − IBL×(27 Ω+0.075 Ω)` and varies with source/path case; it is not an authoritative LED Vf or a predicted current.

[Power DC matrix CSV](https://cdn2.flux.ai/flux-comment-files/files/commentFileId-99a8e3bc4f5de6fb43ae5db692d158c7e15c89d2a157067bf285e125756307b0.csv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)

[Power matrix heatmap](https://cdn2.flux.ai/flux-comment-files/files/commentFileId-6da55f42e82d7b7065366a02b43b1118be3c3d9007233b856f939d9c3bea7b9a.png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)

### USB budget and pre-enumeration

Including worst-case modeled IQ/leakage:

- 50 mA + 75 mA → **125.10 mA**
- 70 mA + 75 mA → **145.10 mA**
- 100 mA + 75 mA → **175.10 mA**

With backlight off, 50 mA and 70 mA rail cases remain below 100 mA. The 100 mA validation load becomes approximately **100.10 mA**, so it does not meet a strict pre-enumeration <100 mA criterion. Firmware must hold the actual pre-enumeration rail load below about 99.9 mA; the planned ~50 mA state passes.

### Load transients

No vendor dynamic SPICE model was used. Bounded calculations use C2=4.23 µF tolerance-min and ESR 10–300 mΩ:

- 20→70 mA: immediate ESR step 0.5–15 mV; capacitor-only droop 11.8 mV after 1 µs, 59.1 mV after 5 µs, 118 mV after 10 µs before regulator correction.
- 20→100 mA: immediate ESR step 0.8–24 mV; capacitor-only droop 18.9 mV after 1 µs, 94.6 mV after 5 µs, 189 mV after 10 µs before regulator correction.

These are bounds, not predicted rail dips. The AP7361C datasheet includes 4.7 µF transient plots, but exact excursion was not digitized.

[Load-transient bounds CSV](https://cdn2.flux.ai/flux-comment-files/files/commentFileId-ed3b74ce3b14fb3c72d937722a3c89047e048957841160ed969658c58d3ece9b.csv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)

### Startup/hot-plug

An ideal source/R/C bound using C1=4.23–4.7 µF gives 10–90% VBUS_PROT rise times of **3.25–22.72 µs** and mathematical initial currents of **2.16–15 A**. Real USB source current limiting, connector inductance, source ramp, capacitor DC bias, PPTC heating, and TVS nonlinear dynamics are not represented. AP7361C typical startup is ~150 µs under its stated test condition. No surge or ESD verification is claimed.

[Startup/hot-plug RC bounds CSV](https://cdn2.flux.ai/flux-comment-files/files/commentFileId-6d89e029df5736dd46f3270ef9f8027f01d8ae552f2b194ab310b0825ab3b982.csv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)

## Post-layout validation status

1. **Implemented:** R12 and R18 are 47 Ω Yageo RC0603FR-0747RL, retaining C18/C25=1 nF. Rerun analysis if an actual TLV9062 macromodel becomes available, and validate on the prototype.
2. Keep both compensation trim footprints. Prototype default is expected to be 15.1 pF total low-arm capacitance, with 12.9 pF as the likely alternate after measured parasitic capacitance and square-wave response.
3. Preserve the existing backlight current-tuning and power/thermal prototype gates.
4. Bench-check the near-zero output floor, 15 V overload/recovery, negative-input behavior under current limitation, ADC crosstalk, and the final firmware sampling sequence.

## Layout and claim boundary update — 2026-08-28

The PCB is routed on a 100 × 100 mm, four-copper-layer, nominal 1.30 mm custom stackup with all components top-side. Current checks show zero airwires and zero DRC errors. USB_DP uses a bottom-layer bypass with explicit top/bottom transition vias; the configured 45 Ω single-ended / 90 Ω differential USB target is a fabrication target only. Two protected dangling-trace warnings (`Trace a4ae`, `Trace b74f`) require Gerber review and cleanup or explicit waiver.

No simulation result in this file closes the unmeasured gates for bandwidth, divider compensation, 15 V survival, backlight operating point, USB ESD/hot-plug, ADC timing, thermals, or HSI accuracy.

## Project-file reconciliation

- **MVP Design Decisions:** reconciled to the implemented 47 Ω/1 nF network while retaining prototype validation gates.
- **Design FMEA:** updated with the acquisition-settling failure and compensation-peaking risk.
- **Board Bring-Up Plan:** updated with explicit acquisition, compensation, zero-floor, overload, power-transient, and pre-enumeration tests.
- **Power Budget:** reconciled to use LDO input current = output current + quiescent current, with direct-source loads added separately.

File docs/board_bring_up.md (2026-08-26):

# Board Bring-Up Plan

## Safety boundary

**0–12 V DC RATED MEASUREMENT; 15 V OVERLOAD-SURVIVAL TARGET UNVERIFIED; GROUND REFERENCED; NOT ISOLATED; NO MAINS/CAT/HIGH ENERGY; NO NEGATIVE INPUT.**

## Power-off checks

1. Verify no short from VBUS_RAW, VBUS_PROT, 3V3 or VDDA to GND.
2. Confirm the fitted GND–AGND 0 Ω bond and USB-shield 0 Ω production bond.
3. Confirm BAV199 orientation on both channels: pin 1 AGND, pin 3 CHx_CLAMP, pin 2 VDDA.
4. Confirm LCD option and straps: pins 11–14, 19 and 20 high; pins 15–17 common MOSI; pin 18 SCK; pins 1–4 unused; pin 6 solid GND.

## Initial powered checks

1. Power from a current-limited USB source with the backlight disabled.
2. Measure TP_VBUS_RAW, TP_VBUS_PROT, TP_3V3, TP_VDDA and TP_GND.
3. Check LDO and ferrite temperatures and verify stable 3V3/VDDA rails.
4. Attach STDC14 and confirm SWDIO, SWCLK, NRST and VTref operation.
5. Program minimal firmware and verify the VCP crossover with a UART loopback test.

## Functional checks

1. Confirm USB enumeration and D+/D− continuity at the small test pads without long probe stubs.
2. Exercise RUN/STOP, MODE and SELECT; verify clean active-low transitions at the MCU-side RC nodes.
3. Test all four LEDs and verify intended roles.
4. Initialize the ERM19296-1 logic before enabling the backlight.
5. Sweep PA8 PWM and measure backlight current. Retain 27 Ω only if the maximum-brightness current is 60–75 mA under the defined VBUS condition.
6. Apply precision low-voltage DC sources to CH1 and CH2. Compare TP_CHx_IN, TP_CHx_DIV and TP_CHx_ADC; verify symmetry and ADC mapping.
7. Verify the fitted ADC isolation resistors are the post-simulation value (**47 Ω recommended for R12/R18**) and C18/C25 remain 1.0 nF.
8. Alternate channel-equivalent inputs near 0.5 V and 12 V at the locked 80 MHz, 12.5-cycle sequence. Measure rank-end settling/crosstalk; acceptance is ≤1 LSB external acquisition error before ADC intrinsic TUE is added.
9. Perform square-wave and swept-sine compensation tests. Start with 15.1 pF total low-arm capacitance (8.2+2.2+4.7 pF), compare 12.9 pF, and reject 8.2 pF-only unless measured DC–100 kHz response remains within ±1 dB.
10. Measure the zero-input ADC floor and input-equivalent dead zone; characterize/calibrate the TLV9062 near-ground output limit rather than assuming a true zero code.
11. Repeat 0→12 V, 12→0 V, 1 kHz square, and 100 kHz sine tests on both channels and record overshoot, settling, gain, phase, and channel symmetry.
12. Perform current-limited 15 V positive overload/recovery tests. Negative-input and +20 V abuse tests are engineering stress tests only; keep them current-limited and do not convert them into user ratings.
13. Exercise 20→70 mA and 20→100 mA 3.3 V load steps and 0→75 mA backlight steps while recording VBUS_PROT/3V3 dip, overshoot, and AP7361C temperature.
14. Verify the actual pre-enumeration state remains below 100 mA with the backlight off; the 100 mA validation rail case plus regulator/TVS current is slightly above a strict 100 mA limit.

## Prototype gates

Do not close the design on schematic evidence alone for analog bandwidth/settling, 15 V overload survival, ESD/hot-plug robustness, timebase accuracy, compensation selection, backlight value, or regulator/MOSFET/resistor thermal performance.

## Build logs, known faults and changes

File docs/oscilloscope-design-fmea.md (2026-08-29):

# Design FMEA

## Status convention

Status terms are evidence-specific: proposed/locked/target does not mean implemented, and implemented/modeled does not mean measured, tested, certified, or production-proven.

| Risk | Locked Rev 0.2 disposition | Residual prototype verification gate |
|---|---|---|
| Wrong ADC channel/order | CH1 = PA0/ADC1_IN5 rank 1; CH2 = PA1/ADC1_IN6 rank 2 | Firmware register/readback and injected-signal confirmation |
| ADC timing / acquisition error | Implemented R12/R18 = 47 Ω Yageo RC0603FR-0747RL with 1 nF; bounded model gives 0.558 LSB external error | ADC timing, rank skew, settling, and crosstalk remain unmeasured |
| BNC overvoltage/ADC damage | 1.10 MΩ low-frequency nominal divider; BAV199 pin 1→AGND, pin 3→CHx_CLAMP, pin 2→VDDA; 10 kΩ to buffer | 15 V overload-survival test, recovery, latch-up, and cross-channel corruption |
| Overstated input rating | 0–12 V DC is the normal rated range | 15 V remains an unverified overload target, not certification |
| Divider tolerance misstatement | Three 300 kΩ ±0.1% parts form 900 kΩ ±0.1%; guaranteed ratio error +0.1637/−0.1635% | Calibration and temperature characterization; RSS kept separate from worst case |
| Aliasing/source-dependent ADC error | Buffered ADC drive; recommended 47 Ω/1 nF and 12.5-cycle sample target | Settling, crosstalk, bandwidth, flatness, and alias characterization with alternating near-full-scale channels |
| Divider compensation mismatch / peaking | Fixed 8.2 pF plus 2.2/4.7 pF trim pads | 8.2 pF-only model peaks ~2–4 dB. Start prototype evaluation at 15.1 pF total and compare 12.9 pF; accept only after square-wave and swept-sine flatness tests. |
| HSI timebase error | USB-SOF/factory correction approach | Accuracy over voltage and 0–50 °C |
| VCP direction error | `VCP_TARGET_TX_TO_PROBE_RX` and `VCP_PROBE_TX_TO_TARGET_RX` | Continuity and loopback |
| LCD interface mismatch | Exact ERM19296-1 4-wire SPI pin-header option; 1×20, 2.54 mm interface and serial straps documented | Incoming inspection, cold-start, and strap verification |
| Backlight ground interruption | High-side NCE3401 switch feeds LEDA pin 5; LCD pin 6 VSS remains permanently grounded | Continuity inspection confirms no switch or series element in pin-6 ground path |
| Backlight unintended ON / wrong polarity | NCE3401 gate has 100 kΩ pull-up; 2N7002 gate has 100 kΩ pulldown; MCU PWM high = backlight ON | Verify reset/boot default OFF and PWM polarity on bench |
| Backlight overcurrent/overheating | 27 Ω, 0.75 W is provisional; acceptance is 60–75 mA | Measure exact module Vf/current; verify resistor, MOSFET, LCD, and enclosure temperatures |
| Backlight MOSFET overstress | Fitted Q1 is NCE3401; Q2 is 2N7002KT1G | Confirm assembly orientation; measure operating point and thermals |
| USB ESD/hot-plug | USBLC6-2SC6, PPTC, TVS, rated input capacitor | ESD, hot-plug, and nuisance-trip bench tests |
| LDO/MOSFET/LCD overheating | 70 mA 3.3 V design load and 75 mA backlight budget | Thermal tests at room and elevated ambient |
| Unsafe floating/high-energy use | Common-ground warnings and 0–12 V normal rating | Label/manual/UI inspection; no safety certification claim |
| Assembly BOM contamination | Fourteen fabricated 1.0 × 1.0 mm test pads are currently BOM elements | Block assembly export until excluded from BOM and pick-and-place; keep TP_GND included |
| Legacy dangling copper | Zero airwires and zero DRC errors, but protected warnings remain for Trace a4ae and Trace b74f | Gerber review, cleanup, or explicit waiver before fabrication release |
| USB impedance overclaim | 45 Ω single-ended / 90 Ω differential configured; USB_DP bottom-layer bypass uses explicit transition vias | Fabricator stackup confirmation; do not claim measured or certified impedance |

## Divider statistical note

Guaranteed worst-case divider ratio is approximately **+0.163741% / −0.163532%**. First-order RSS is **0.0945% (1σ)** only if each 0.1% tolerance is treated as an independent 1σ value, or **0.0545% (1σ)** if ±0.1% is treated as a rectangular bound. RSS values are statistical estimates and do not replace guaranteed limits.

## Current blockers and gates

The ADC resistor change is implemented. SMT assembly export remains blocked by the fourteen fabricated test-pad BOM elements. Bare-board release requires cleanup or waiver of `Trace a4ae` and `Trace b74f`. Bandwidth, divider compensation, 15 V overload survival, backlight operating point, USB ESD/hot-plug, ADC timing, thermals, and HSI accuracy remain unmeasured prototype gates.

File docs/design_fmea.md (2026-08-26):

# Design FMEA

## Status convention

Locked/proposed dispositions are approved for schematic capture; they are not implemented, tested, measured, or certified until verified on hardware.

| Risk | Locked Rev 0.2 disposition | Residual prototype verification gate |
|---|---|---|
| Wrong ADC channel/order | CH1 = PA0/ADC1_IN5 rank 1; CH2 = PA1/ADC1_IN6 rank 2 | Firmware register/readback and injected-signal confirmation |
| ADC timing / acquisition error | 80 MHz asynchronous clock target; 12.5+12.5 cycles; timer-triggered 3.2 Msps aggregate | Captured 330 Ω/1 nF drive fails modeled alternating-channel acquisition by ~9.5–9.9 LSB. Change R12/R18 to 47 Ω, re-simulate, then confirm ≤1 LSB settling and 312.5 ns rank timing on bench. |
| BNC overvoltage/ADC damage | 1.10 MΩ low-frequency nominal divider; BAV199 pin 1→AGND, pin 3→CHx_CLAMP, pin 2→VDDA; 10 kΩ to buffer | 15 V overload-survival test, recovery, latch-up, and cross-channel corruption |
| Overstated input rating | 0–12 V DC is the normal rated range | 15 V remains an unverified overload target, not certification |
| Divider tolerance misstatement | Three 300 kΩ ±0.1% parts form 900 kΩ ±0.1%; guaranteed ratio error +0.1637/−0.1635% | Calibration and temperature characterization; RSS kept separate from worst case |
| Aliasing/source-dependent ADC error | Buffered ADC drive; recommended 47 Ω/1 nF and 12.5-cycle sample target | Settling, crosstalk, bandwidth, flatness, and alias characterization with alternating near-full-scale channels |
| Divider compensation mismatch / peaking | Fixed 8.2 pF plus 2.2/4.7 pF trim pads | 8.2 pF-only model peaks ~2–4 dB. Start prototype evaluation at 15.1 pF total and compare 12.9 pF; accept only after square-wave and swept-sine flatness tests. |
| HSI timebase error | USB-SOF/factory correction approach | Accuracy over voltage and 0–50 °C |
| VCP direction error | `VCP_TARGET_TX_TO_PROBE_RX` and `VCP_PROBE_TX_TO_TARGET_RX` | Continuity and loopback |
| LCD interface mismatch | Exact ERM19296-1 4-wire SPI pin-header option; 1×20, 2.54 mm interface and serial straps documented | Incoming inspection, cold-start, and strap verification |
| Backlight ground interruption | High-side AO3401A switch feeds LEDA pin 5; LCD pin 6 VSS remains permanently grounded | Continuity inspection confirms no switch or series element in pin-6 ground path |
| Backlight unintended ON / wrong polarity | AO3401A gate has 100 kΩ pull-up; 2N7002 gate has 100 kΩ pulldown; MCU PWM high = backlight ON | Verify reset/boot default OFF and PWM polarity on bench |
| Backlight overcurrent/overheating | 27 Ω, 0.5 W is provisional; acceptance is 60–75 mA | Measure exact module Vf/current; verify resistor, MOSFET, LCD, and enclosure temperatures |
| Backlight MOSFET overstress | AO3401A: −30 V VDS, ±12 V VGS, ≤60 mΩ at −4.5 V; 2N7002KT1G: 60 V VDS, ±20 V VGS, ≥230 mA stated continuous capability | Confirm fitted exact MPNs and source/drain/gate pin mapping during capture and assembly review |
| USB ESD/hot-plug | USBLC6-2SC6, PPTC, TVS, rated input capacitor | ESD, hot-plug, and nuisance-trip bench tests |
| LDO/MOSFET/LCD overheating | 70 mA 3.3 V design load and 75 mA backlight budget | Thermal tests at room and elevated ambient |
| Unsafe floating/high-energy use | Common-ground warnings and 0–12 V normal rating | Label/manual/UI inspection; no safety certification claim |
| Unassigned headers | Remove both TS-107-T-AA headers | BOM and schematic audit |

## Divider statistical note

Guaranteed worst-case divider ratio is approximately **+0.163741% / −0.163532%**. First-order RSS is **0.0945% (1σ)** only if each 0.1% tolerance is treated as an independent 1σ value, or **0.0545% (1σ)** if ±0.1% is treated as a rectangular bound. RSS values are statistical estimates and do not replace guaranteed limits.

## Capture blockers

**Pre-layout electrical blocker:** resolve the ADC isolation resistor value. Current 330 Ω/1 nF fails the locked 12.5-cycle acquisition target; 47 Ω/1 nF passes the bounded model and is recommended for R12/R18. Compensation population remains a prototype trim gate because the necessary footprints already exist.

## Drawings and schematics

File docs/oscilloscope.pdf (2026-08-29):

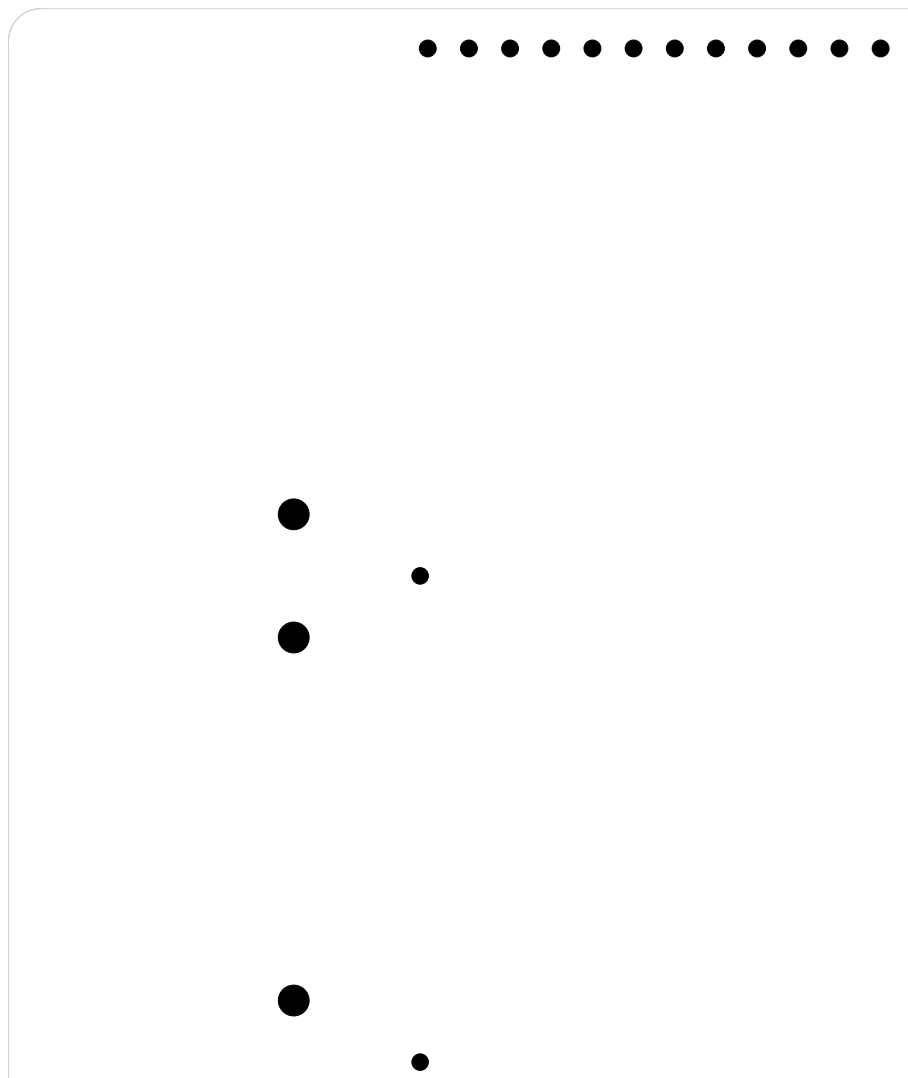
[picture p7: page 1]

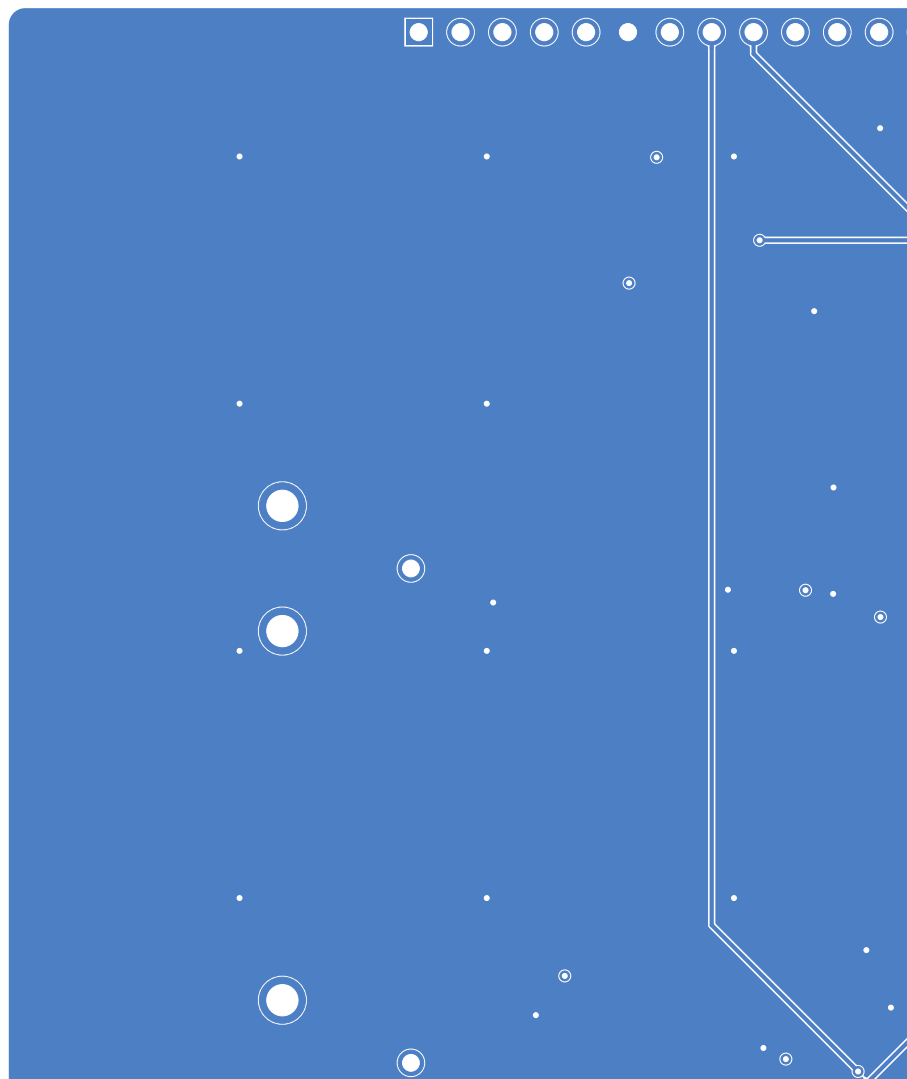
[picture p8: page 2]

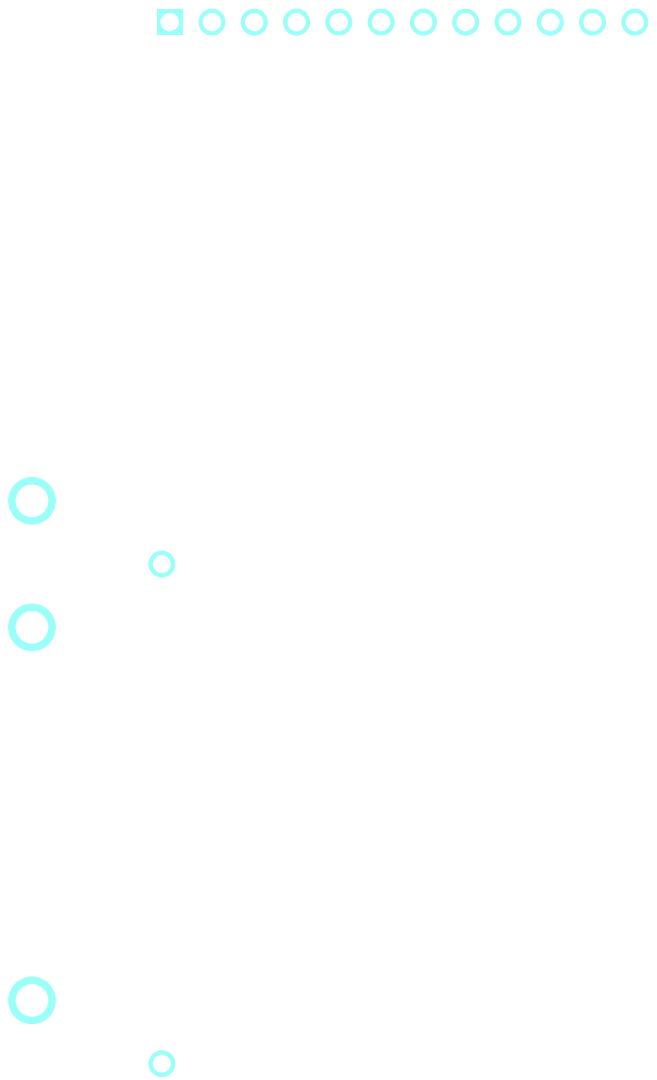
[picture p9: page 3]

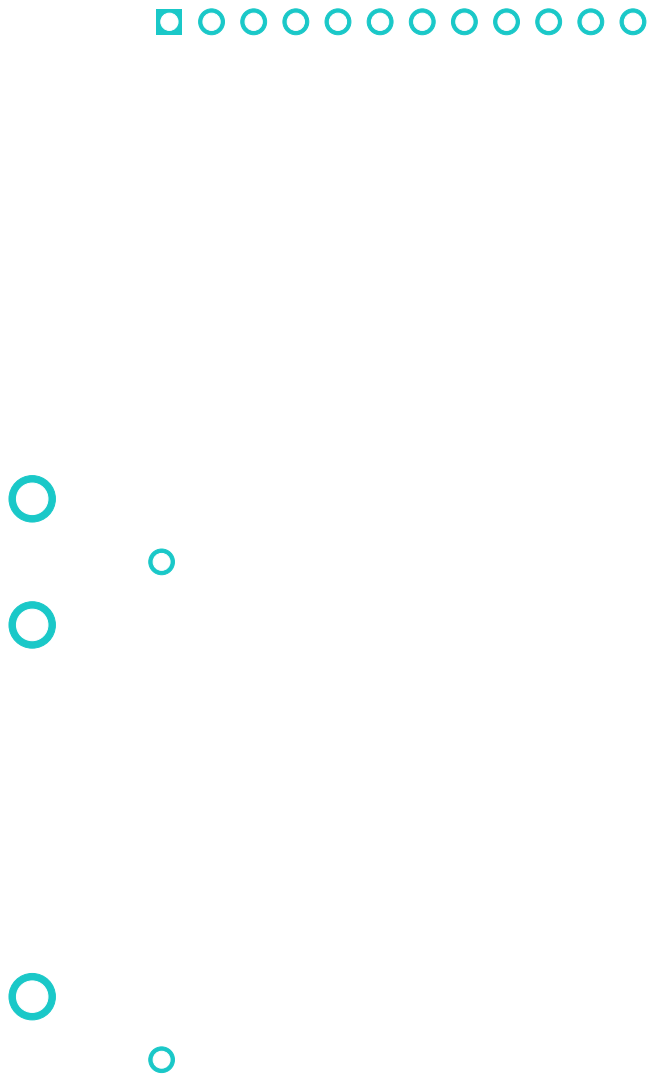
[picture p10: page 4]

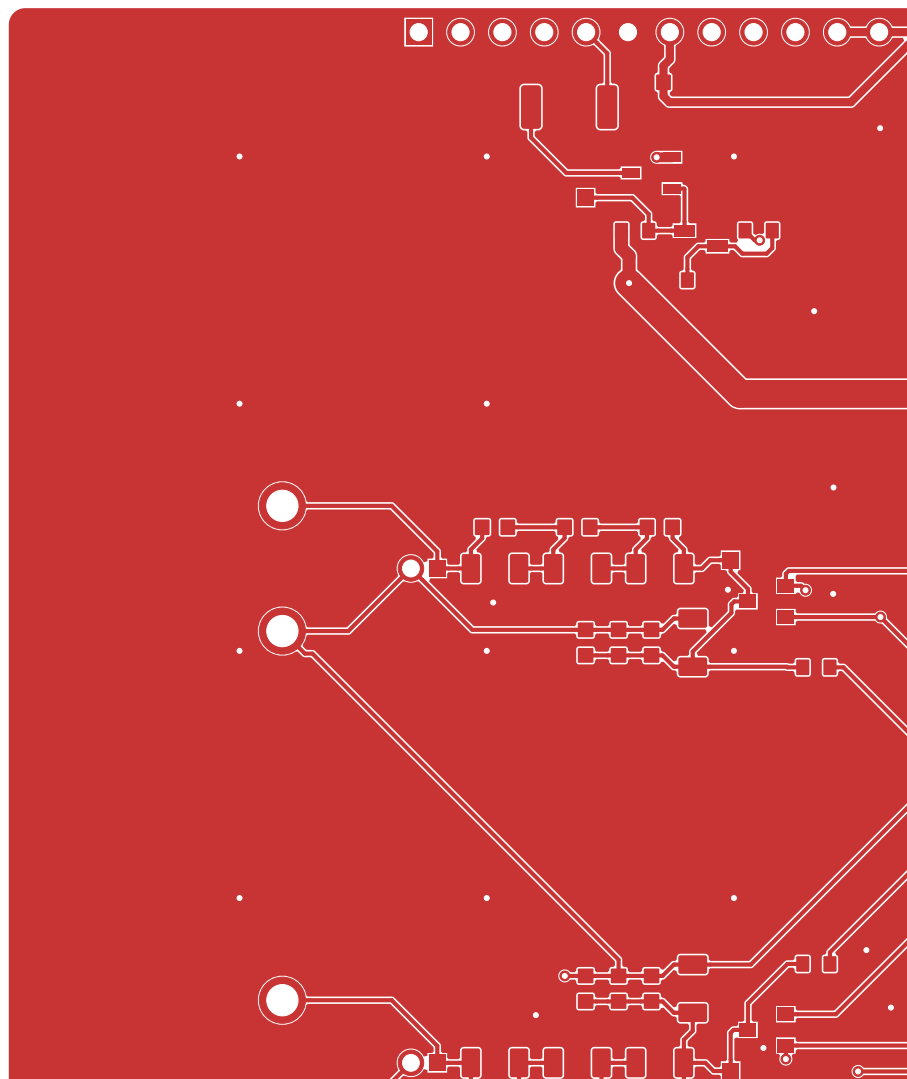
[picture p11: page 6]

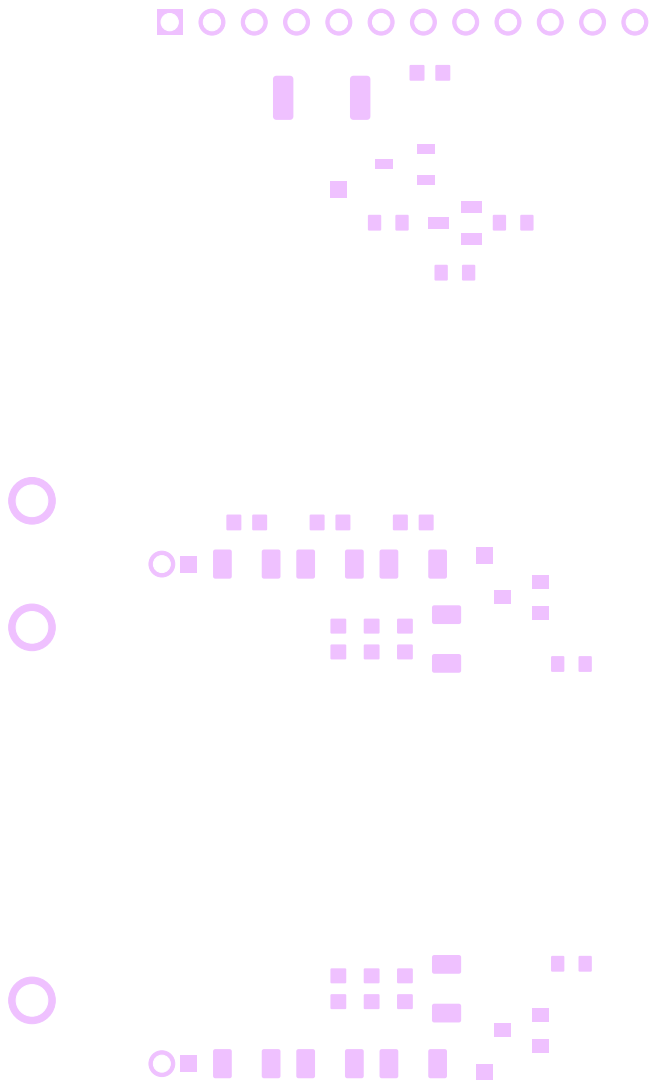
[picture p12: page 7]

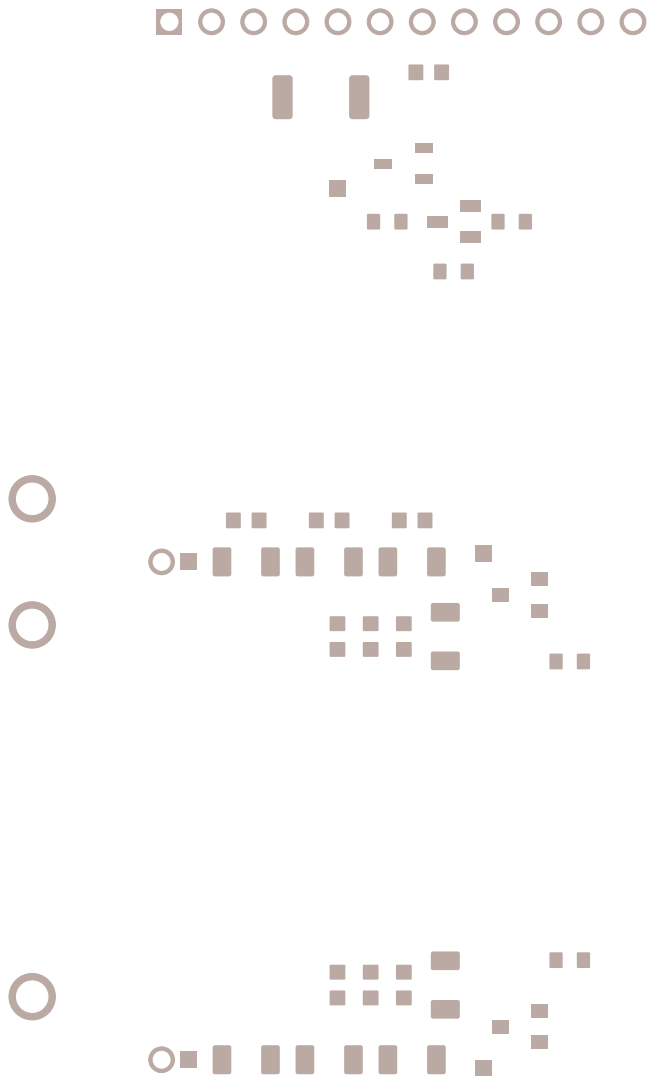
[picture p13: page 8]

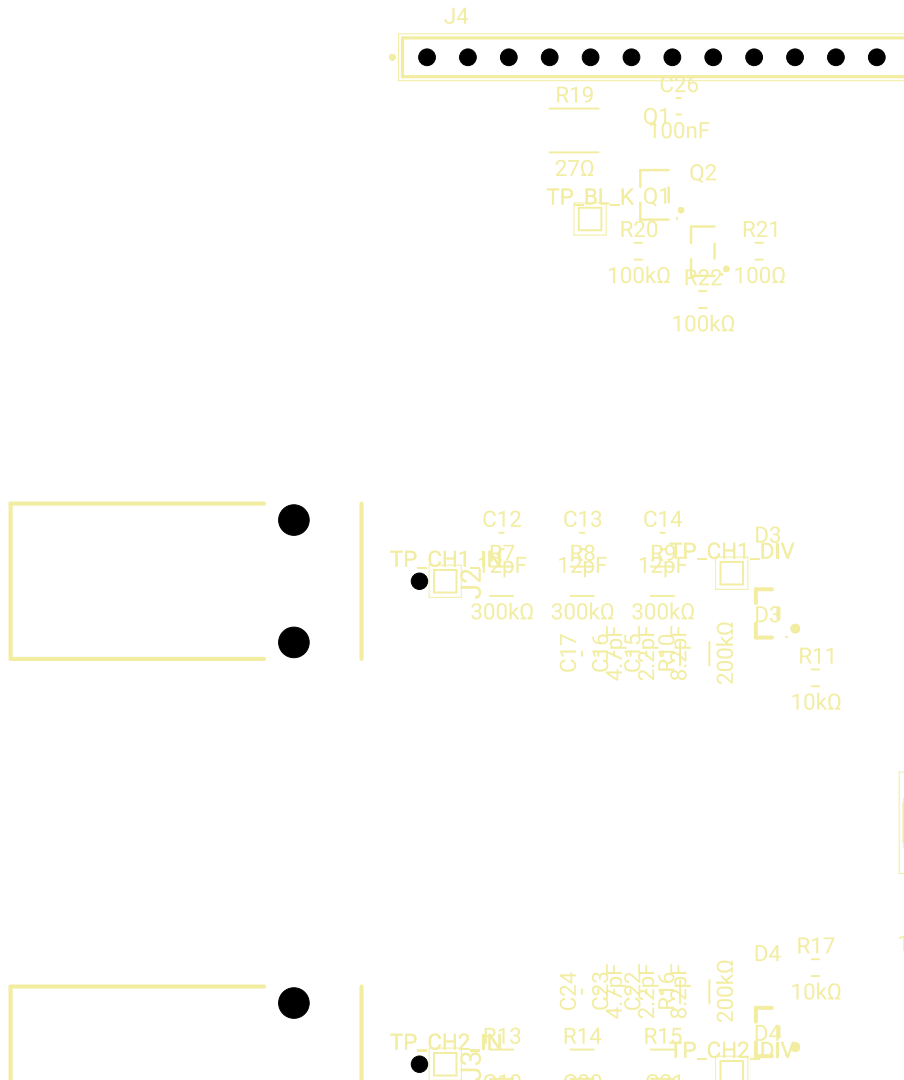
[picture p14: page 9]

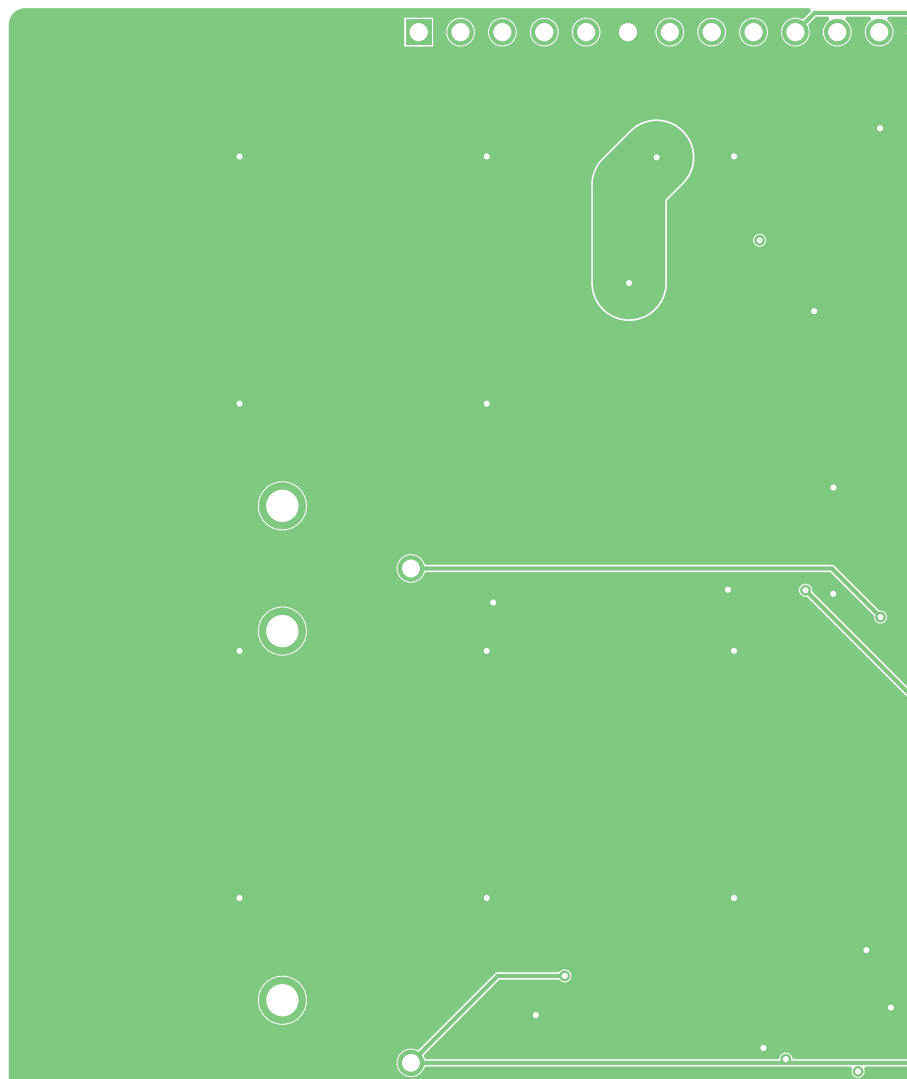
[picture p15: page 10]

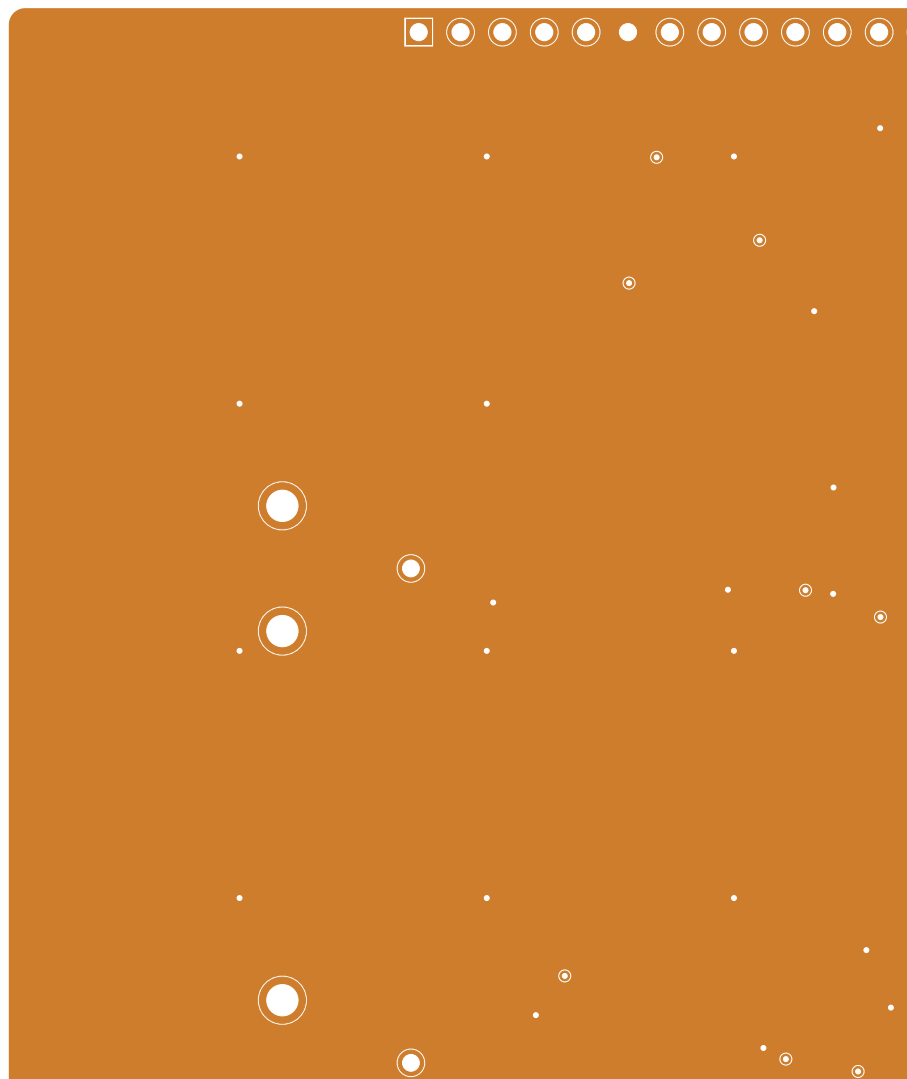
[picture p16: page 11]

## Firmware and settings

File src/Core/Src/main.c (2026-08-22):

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
/* Includes ------------------------------------------------------------------*/
#include "main.h"
#include "usb_device.h"

/* USER CODE BEGIN Includes */
#include <stdint.h>
#include <stdbool.h>

#include "sillyscope_app.h"

#include "channel_mgmt.h"
#include "channel_data.h"
/* USER CODE END Includes */

ADC_HandleTypeDef hadc1;
DMA_HandleTypeDef hdma_adc1;

CRC_HandleTypeDef hcrc;

SPI_HandleTypeDef hspi1;

TIM_HandleTypeDef htim16;

UART_HandleTypeDef huart2;

void SystemClock_Config(void);
void PeriphCommonClock_Config(void);
static void MX_GPIO_Init(void);
static void MX_DMA_Init(void);
static void MX_ADC1_Init(void);
static void MX_SPI1_Init(void);
static void MX_CRC_Init(void);
static void MX_USART2_UART_Init(void);
static void MX_TIM16_Init(void);
/**
  * @brief  The application entry point.
  * @retval int
  */
int main(void)
{

  /* USER CODE BEGIN 1 */

  ch_data_adc = &hadc1;
  ch_data_crc = &hcrc;
  ch_data_uart = &huart2;
  disp_spi = &hspi1;

  /* USER CODE END 1 */

  /* MCU Configuration--------------------------------------------------------*/

  /* Reset of all peripherals, Initializes the Flash interface and the Systick. */
  HAL_Init();

  /* Configure the system clock */
  SystemClock_Config();

  /* Configure the peripherals common clocks */
  PeriphCommonClock_Config();

  /* Initialize all configured peripherals */
  MX_GPIO_Init();
  MX_DMA_Init();
  MX_ADC1_Init();
  MX_SPI1_Init();
  MX_CRC_Init();
  MX_USART2_UART_Init();
  MX_USB_DEVICE_Init();
  MX_TIM16_Init();
  /* Infinite loop */
  /* USER CODE BEGIN WHILE */

  sillyscope_app();
  // NOTE: never reached

  while (1)
  {
    /* USER CODE END WHILE */

    /* USER CODE BEGIN 3 */
  }
  /* USER CODE END 3 */
}

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
/* USER CODE BEGIN 4 */

void HAL_GPIO_EXTI_Callback(uint16_t GPIO_Pin) {
  switch (GPIO_Pin) {
    case BTN_CH1_Pin: ch_mgmt_button1_callback(); break;
    case BTN_CH2_Pin: ch_mgmt_button2_callback(); break;
    case BTN_REC_Pin: rec_button_callback(); break;
    default: break;
  }
}

/* USER CODE END 4 */

/**
  * @brief  Period elapsed callback in non blocking mode
  * @note   This function is called  when TIM2 interrupt took place, inside
  * HAL_TIM_IRQHandler(). It makes a direct call to HAL_IncTick() to increment
  * a global variable "uwTick" used as application time base.
  * @param  htim : TIM handle
  * @retval None
  */
void HAL_TIM_PeriodElapsedCallback(TIM_HandleTypeDef *htim)
{
  if (htim->Instance == TIM2)
  {
    HAL_IncTick();
  }
  /* USER CODE BEGIN Callback 1 */
  if (htim->Instance == TIM16) {
    ch_data_timer_update_callback();
  }
  /* USER CODE END Callback 1 */
}

/**
  * @brief  This function is executed in case of error occurrence.
  * @retval None
  */
void Error_Handler(void)
{
  /* USER CODE BEGIN Error_Handler_Debug */
  /* User can add his own implementation to report the HAL error return state */
  __disable_irq();
  while (1)
  {
  }
  /* USER CODE END Error_Handler_Debug */
}
#ifdef USE_FULL_ASSERT
/**
  * @brief  Reports the name of the source file and the source line number
  *         where the assert_param error has occurred.
  * @param  file: pointer to the source file name
  * @param  line: assert_param error line source number
  * @retval None
  */
void assert_failed(uint8_t *file, uint32_t line)
{
  /* USER CODE BEGIN 6 */
  /* User can add his own implementation to report the file name and line number,
     ex: printf("Wrong parameters value: file %s on line %d\r\n", file, line) */
  /* USER CODE END 6 */
}
#endif /* USE_FULL_ASSERT */

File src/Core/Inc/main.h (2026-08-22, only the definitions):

#define DISP_RST_Pin GPIO_PIN_3
#define DISP_RST_GPIO_Port GPIOA
#define BTN_CH2_Pin GPIO_PIN_4
#define BTN_CH2_GPIO_Port GPIOA
#define BTN_CH2_EXTI_IRQn EXTI4_IRQn
#define SPI_CS_Pin GPIO_PIN_0
#define SPI_CS_GPIO_Port GPIOB
#define DISP_A0_Pin GPIO_PIN_1
#define DISP_A0_GPIO_Port GPIOB
#define BTN_CH1_Pin GPIO_PIN_8
#define BTN_CH1_GPIO_Port GPIOA
#define BTN_CH1_EXTI_IRQn EXTI9_5_IRQn
#define BTN_REC_Pin GPIO_PIN_3
#define BTN_REC_GPIO_Port GPIOB
#define BTN_REC_EXTI_IRQn EXTI3_IRQn
#define LED_REC_Pin GPIO_PIN_4
#define LED_REC_GPIO_Port GPIOB
#define LED_CH1_Pin GPIO_PIN_5
#define LED_CH1_GPIO_Port GPIOB
#define LED_CH2_Pin GPIO_PIN_6
#define LED_CH2_GPIO_Port GPIOB

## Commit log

2026-08-22 added project files
    [ADC.kicad_sch, ADC.sch, Analog Inputs.kicad_sch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]
2026-08-22 set up documentation and project
    [oscilloscope.kicad_pcb, oscilloscope.kicad_sch, sillyscope-bom - Sheet1.csv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]
2026-08-29 added new design documents
    [nbean-oscilloscope-BOM-V1b37e5ba-AdvancedCircuits.csv, nbean-oscilloscope-BOM-V1b37e5ba-AllPCB.csv, nbean-oscilloscope-BOM-V1b37e5ba-Elecrow.csv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]

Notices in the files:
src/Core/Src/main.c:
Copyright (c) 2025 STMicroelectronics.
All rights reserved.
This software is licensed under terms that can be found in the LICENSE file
